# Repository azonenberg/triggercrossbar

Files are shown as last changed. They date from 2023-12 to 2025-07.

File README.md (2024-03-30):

# PROJECT STATUS

You probably don't want to build this as is, there's a couple of bugs. May or may not respin later on with fixes, for now I'm just bodging my prototype.

Bodge log at https://docs.google.com/document/d/14ighvhOLtBR-3ShkNhyRGlamA1f7WH5_sXfJCJYxb1o/edit

# What is it?

When finished, it will be a 1U rack-mountable appliance with a TBD number of BNC and/or SMA connectors on the back side for trigger inputs and outputs. Some will be input only, some output only, and some bidirectional. Exact mix is TBD.

Additionally, a front panel SMA input will be connected through a precision 10 GHz comparator (ADI HMC675LP3E) to an FPGA transceiver input, allowing single ended CDR triggering.

There may or may not be front panel SMA inputs/outputs connected to otherwise unused transceiver channels for expansion or additional trigger capabilities.

An Ethernet SCPI interface will allow configuration of an FPGA-based crossbar, with the internal CDR trigger as well as all of the input channels available as inputs. Any input can be forwarded to any output, allowing arbitrary cross-triggering of attached instruments without the need to recable.

Front panel LEDs with pulse stretching will display the states of trigger in/out ports.

This system is intended in part as a testbed to de-risk several future projects (validating stackup and power supply design etc), and to use up an FPGA that I had lying around the lab. Only one unit is ever expected to be built, so a functionally equivalent platform could definitely be built for lower cost.

# Physical architecture

# Trigger ports

Koaxis AL62-CC086F-RL10-6.00-MK (6" CC086F hand formable FEP jacket SMA - SMPM), length open to change based on final mechanical and board design.

## Input range

The range of the inputs should be sufficient to accommodate all common T&M instruments, which will likely require variable thresholding.

Representative instrument trigger output specs:

* PicoScope 6000E (bidirectional): not specified, need to measure
* PicoVNA 108: 3.3V into high-Z
* Siglent SSG5000X (bidirectional): 5V TTL for trigger, 3.3V CMOS for pulse
* Siglent SDG7000A: 5V TTL (voh = 3.8V)
* Teledyne LeCroy (all recent models): 1V into 1M ohm / 500 mV into 50 ohm by default, adjustable a bit?

## Output range

The range of the outputs should be compatible with all common T&M instruments, which will likely require variable swing.

Representative instrument trigger input specs:

* PicoScope 6000E (bidirectional): 2.5V CMOS high-z input, fixed 1.25V threshold
* PicoVNA 108: 3.3V CMOS high-Z, nominal 1.5V threshold
* Siglent SSG5000X (bidirectional): 5V TTL for trigger, 3.3V CMOS for pulse
* Siglent SDG7000A: 5V TTL (Vih = 2 to 5.5V)
* Teledyne LeCroy (all recent models): adjustable threshold up to +/- 400 mV or +/- 4V in 1x / 10x mode respectively

# Input buffer design

We need a total of seven inputs today, plan for at least ten to provide some margin

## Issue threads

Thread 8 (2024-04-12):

Full reboot support

azonenberg, 2024-04-12:
Rather than having the main MCU just reset itself when we run "reload", do a full power down/up sequence via the supervisor

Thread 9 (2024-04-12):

Full reboot support via front panel reset button

azonenberg, 2024-04-12:
Probably require holding it for a few seconds to avoid inadvertent resets?

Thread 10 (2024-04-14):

Intermittent SPI issues

azonenberg, 2024-04-14:
Example: version numbers shown on front panel having a byte truncated

Not sure if timing or Si or something else yet.

Closed 2024-04-15.

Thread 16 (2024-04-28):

Switch QSPI bus to memory mapped to improve performance

azonenberg, 2024-04-28:

azonenberg, 2024-05-23:
Fixed in b0f43f4e122610cb90c49703867806bcb94aeec4

Closed 2024-05-23.

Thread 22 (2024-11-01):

Resetting IBC results in a false panic shutdown from 12V power failure (this should be a clean sleep we can wake from when the IBC comes back up)

azonenberg, 2024-11-01:

azonenberg, 2024-11-03:
Should be fixed in 69b09eb50da21b395305ae7aaae45e123857d962

Closed 2024-11-03.

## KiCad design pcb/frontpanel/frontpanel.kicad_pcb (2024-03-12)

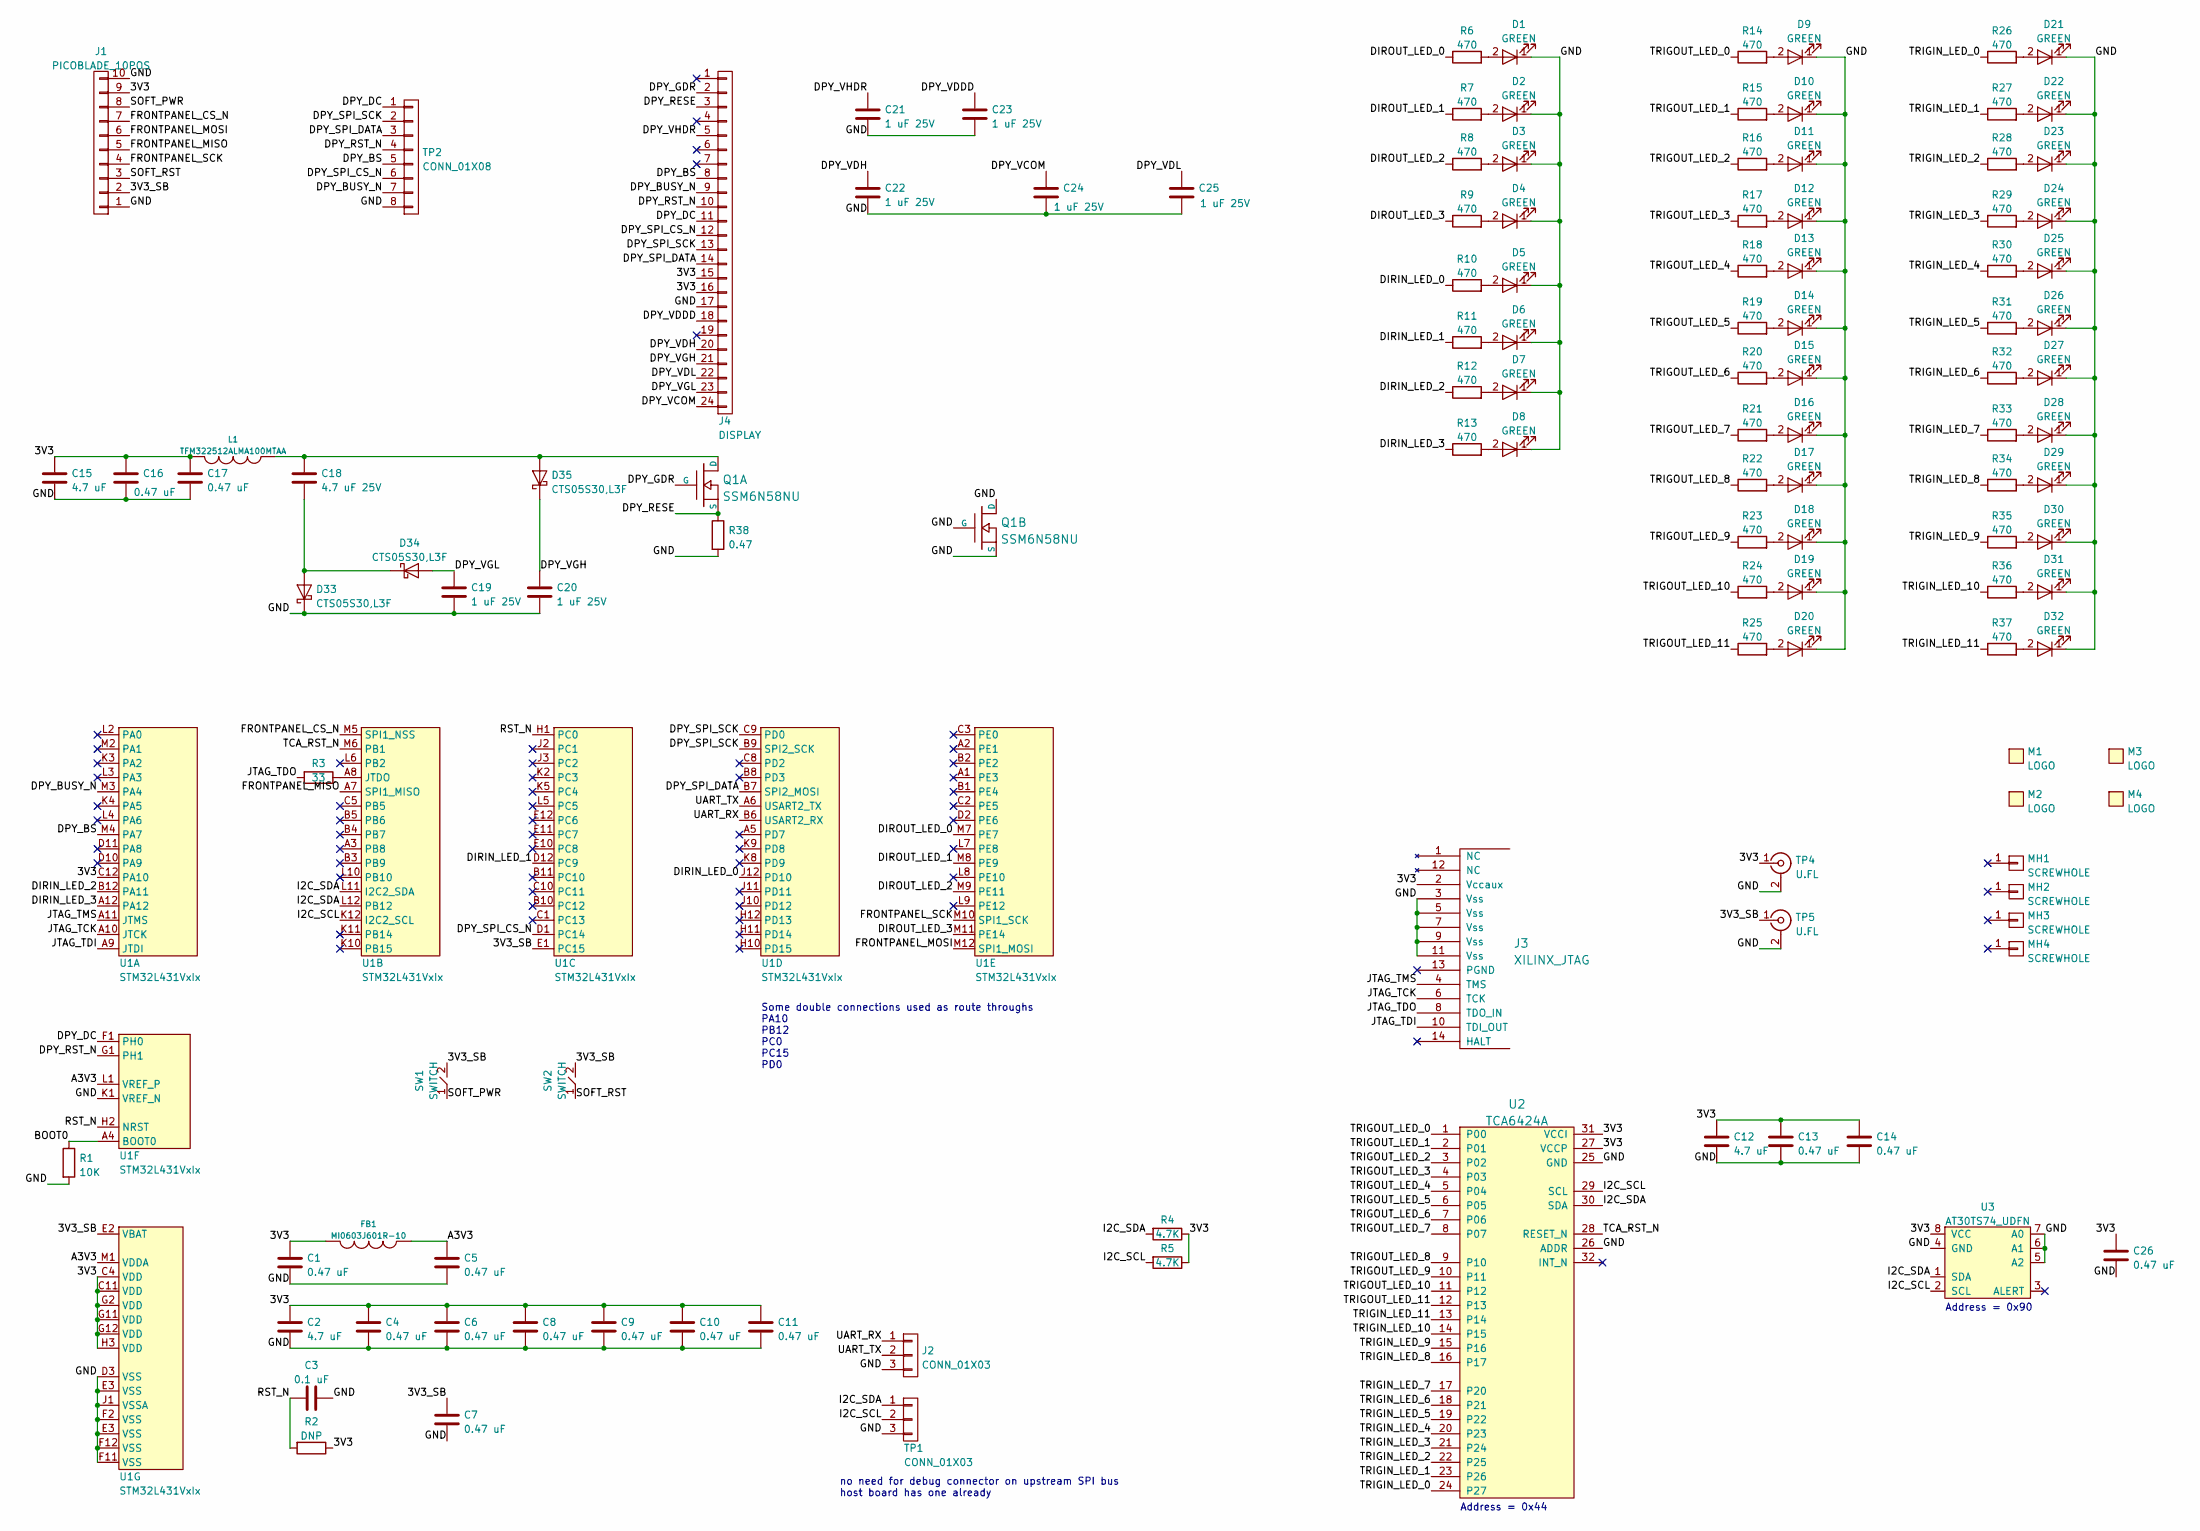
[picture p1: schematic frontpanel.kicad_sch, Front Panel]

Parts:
C1, C4, C5, C6, C7, C8, C9, C10, C11, C13, C14, C16, C17, C26: 0.47 uF; EIA_0402_CAP_NOSILK
C2, C12, C15: 4.7 uF; EIA_0603_CAP_NOSILK
C3: 0.1 uF; EIA_0402_CAP_NOSILK
C18: 4.7 uF 25V; EIA_0805_CAP_NOSILK
C19, C20, C21, C22, C23, C24, C25: 1 uF 25V; EIA_0805_CAP_NOSILK
D1, D2, D3, D4, D5, D6, D7, D8, D9, D10, D11, D12, D13, D14, D15, D16, D17, D18, D19, D20, D21, D22, D23, D24, D25, D26, D27, D28, D29, D30, D31, D32: GREEN; EIA_0603_LED
D33, D34, D35: CTS05S30,L3F; SOD882
FB1: MI0603J601R-10; EIA_0603_INDUCTOR_NOSILK
J1: PICOBLADE_10POS; CONN_MOLEX_PICOBLADE_10POS_0532611071
J2: CONN_01X03; CONN_HEADER_2.54MM_1x3
J3: XILINX_JTAG; XILINX_JTAG_PTH_MOLEX_0878311420
J4: DISPLAY; CONN_FFC_0.5MM_1x24_HIROSE_FH34SRJ-24S-0.5SH(50)
L1: TFM322512ALMA100MTAA; EIA_1210_CAP_NOSILK
M1: LOGO; LONGTHING-1200DPI
M2: LOGO; Logo_silk_WEEE_3.4x5mm
M3: LOGO; Logo_silk_OSHW_6x6mm
M4: LOGO; Logo_silk_ROHS_10x5.6mm
MH1, MH2, MH3, MH4: SCREWHOLE; MECHANICAL_CLEARANCEHOLE_4_40
Q1: SSM6N58NU; DFN_6_0.65MM_2x2MM_GDS
R1: 10K; EIA_0402_RES_NOSILK
R2: DNP; EIA_0402_RES_NOSILK
R3: 33; EIA_0402_RES_NOSILK
R4, R5: 4.7K; EIA_0402_RES_NOSILK
R6, R7, R8, R9, R10, R11, R12, R13, R14, R15, R16, R17, R18, R19, R20, R21, R22, R23, R24, R25, R26, R27, R28, R29, R30, R31, R32, R33, R34, R35, R36, R37: 470; EIA_0402_RES_NOSILK
R38: 0.47; EIA_0402_RES_NOSILK
SW1, SW2: SWITCH; SWITCH_RAFI_MICON_5
TP1: CONN_01X03; CONN_HEADER_2.54MM_1x3
TP2: CONN_01X08; CONN_HEADER_2.54MM_1x8
TP4, TP5: U.FL; CONN_U.FL_TE_1909763-1
U1: STM32L431VxIx; BGA_100_7x7_DEPOP_0.5MM_STM32_UFBGA100_OSHPARK
U2: TCA6424A; QFN_32_0.5MM_5x5MM
U3: AT30TS74_UDFN; DFN_8_0.5MM_2x3MM_TALL

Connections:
/3V3: C1.1, C2.1, C4.1, C6.1, C8.1, C9.1, C10.1, C11.1, C12.1, C13.1, C14.1, C15.1, C16.1, C17.1, C26.1, FB1.2, J1.9, J3.2 (Vccaux), J4.15, J4.16, L1.2, R2.1, R4.1, R5.1, TP4.1 (In), U1.C4 (VDD), U1.C11 (VDD), U1.C12 (PA10), U1.G2 (VDD), U1.G11 (VDD), U1.G12 (VDD), U1.H3 (VDD), U2.27 (VCCP), U2.31 (VCCI), U3.8 (VCC)
/3V3_SB: C7.1, J1.2, SW1.2, SW2.2, TP5.1 (In), U1.E1 (PC15), U1.E2 (VBAT)
/A3V3: C5.1, FB1.1, U1.L1 (VREF_P), U1.M1 (VDDA)
/BOOT0: R1.1, U1.A4 (BOOT0)
/DIRIN_LED_0: R10.1, U1.J12 (PD10)
/DIRIN_LED_1: R11.1, U1.D12 (PC9)
/DIRIN_LED_2: R12.1, U1.B12 (PA11)
/DIRIN_LED_3: R13.1, U1.A12
/DIROUT_LED_0: R6.1, U1.M7 (PE7)
/DIROUT_LED_1: R7.1, U1.M8 (PE9)
/DIROUT_LED_2: R8.1, U1.M9 (PE11)
/DIROUT_LED_3: R9.1, U1.M11 (PE14)
/DPY_BS: J4.8, TP2.5, U1.M4 (PA7)
/DPY_BUSY_N: J4.9, TP2.7, U1.M3 (PA4)
/DPY_DC: J4.11, TP2.1, U1.F1 (PH0)
/DPY_GDR: J4.2, Q1.G1 (G)
/DPY_RESE: J4.3, Q1.S1 (S), R38.1
/DPY_RST_N: J4.10, TP2.4, U1.G1 (PH1)
/DPY_SPI_CS_N: J4.12, TP2.6, U1.D1 (PC14)
/DPY_SPI_DATA: J4.14, TP2.3, U1.B7 (SPI2_MOSI)
/DPY_SPI_SCK: J4.13, TP2.2, U1.B9 (SPI2_SCK), U1.C9 (PD0)
/DPY_VCOM: C24.1, J4.24
/DPY_VDDD: C23.1, J4.18
/DPY_VDH: C22.1, J4.20
/DPY_VDL: C25.1, J4.22
/DPY_VGH: C20.1, D35.1 (K), J4.21
/DPY_VGL: C19.1, D34.2 (A), J4.23
/DPY_VHDR: C21.1, J4.5
/FRONTPANEL_CS_N: J1.7, U1.M5 (SPI1_NSS)
/FRONTPANEL_MISO: J1.5, U1.A7 (SPI1_MISO)
/FRONTPANEL_MOSI: J1.6, U1.M12 (SPI1_MOSI)
/FRONTPANEL_SCK: J1.4, U1.M10 (SPI1_SCK)
/GND: C1.2, C2.2, C3.2, C4.2, C5.2, C6.2, C7.2, C8.2, C9.2, C10.2, C11.2, C12.2, C13.2, C14.2, C15.2, C16.2, C17.2, C19.2, C20.2, C21.2, C22.2, C23.2, C24.2, C25.2, C26.2, D1.1 (K), D2.1 (K), D3.1 (K), D4.1 (K), D5.1 (K), D6.1 (K), D7.1 (K), D8.1 (K), D9.1 (K), D10.1 (K), D11.1 (K), D12.1 (K), D13.1 (K), D14.1 (K), D15.1 (K), D16.1 (K), D17.1 (K), D18.1 (K), D19.1 (K), D20.1 (K), D21.1 (K), D22.1 (K), D23.1 (K), D24.1 (K), D25.1 (K), D26.1 (K), D27.1 (K), D28.1 (K), D29.1 (K), D30.1 (K), D31.1 (K), D32.1 (K), D33.1 (K), J1.1, J1.10, J2.3, J3.3 (Vss), J3.5 (Vss), J3.7 (Vss), J3.9 (Vss), J3.11 (Vss), J4.17, Q1.D2 (D), Q1.G2 (G), Q1.S2 (S), R1.2, R38.2, TP1.3, TP2.8, TP4.2 (Ext), TP5.2 (Ext), U1.D3 (VSS), U1.E3 (VSS), U1.F2 (VSS), U1.F11 (VSS), U1.F12 (VSS), U1.J1 (VSSA), U1.K1 (VREF_N), U2.25 (GND), U2.26 (ADDR), U3.4 (GND), U3.5 (A2), U3.6 (A1), U3.7 (A0)
/I2C_SCL: R5.2, TP1.2, U1.K12 (I2C2_SCL), U2.29 (SCL), U3.2 (SCL)
/I2C_SDA: R4.2, TP1.1, U1.L11 (I2C2_SDA), U1.L12 (PB12), U2.30 (SDA), U3.1 (SDA)
/JTAG_TCK: J3.6 (TCK), U1.A10 (JTCK)
/JTAG_TDI: J3.10 (TDI_OUT), U1.A9 (JTDI)
/JTAG_TDO: J3.8 (TDO_IN), R3.2
/JTAG_TMS: J3.4 (TMS), U1.A11 (JTMS)
/RST_N: C3.1, R2.2, U1.H1 (PC0), U1.H2 (NRST)
/SOFT_PWR: J1.8, SW1.1
/SOFT_RST: J1.3, SW2.1
/TCA_RST_N: U1.M6 (PB1), U2.28 (RESET_N)
/TRIGIN_LED_0: R26.1, U2.24 (P27)
/TRIGIN_LED_1: R27.1, U2.23 (P26)
/TRIGIN_LED_2: R28.1, U2.22 (P25)
/TRIGIN_LED_3: R29.1, U2.21 (P24)
/TRIGIN_LED_4: R30.1, U2.20 (P23)
/TRIGIN_LED_5: R31.1, U2.19 (P22)
/TRIGIN_LED_6: R32.1, U2.18 (P21)
/TRIGIN_LED_7: R33.1, U2.17 (P20)
/TRIGIN_LED_8: R34.1, U2.16 (P17)
/TRIGIN_LED_9: R35.1, U2.15 (P16)
/TRIGIN_LED_10: R36.1, U2.14 (P15)
/TRIGIN_LED_11: R37.1, U2.13 (P14)
/TRIGOUT_LED_0: R14.1, U2.1 (P00)
/TRIGOUT_LED_1: R15.1, U2.2 (P01)
/TRIGOUT_LED_2: R16.1, U2.3 (P02)
/TRIGOUT_LED_3: R17.1, U2.4 (P03)
/TRIGOUT_LED_4: R18.1, U2.5 (P04)
/TRIGOUT_LED_5: R19.1, U2.6 (P05)
/TRIGOUT_LED_6: R20.1, U2.7 (P06)
/TRIGOUT_LED_7: R21.1, U2.8 (P07)
/TRIGOUT_LED_8: R22.1, U2.9 (P10)
/TRIGOUT_LED_9: R23.1, U2.10 (P11)
/TRIGOUT_LED_10: R24.1, U2.11 (P12)
/TRIGOUT_LED_11: R25.1, U2.12 (P13)
/UART_RX: J2.1, U1.B6 (USART2_RX)
/UART_TX: J2.2, U1.A6 (USART2_TX)
unnamed: C18.1, D35.2 (A), L1.1, Q1.D1 (D)
unnamed: C18.2, D33.2 (A), D34.1 (K)
unnamed: D1.2 (A), R6.2
unnamed: D2.2 (A), R7.2
unnamed: D3.2 (A), R8.2
unnamed: D4.2 (A), R9.2
unnamed: D5.2 (A), R10.2
unnamed: D6.2 (A), R11.2
unnamed: D7.2 (A), R12.2
unnamed: D8.2 (A), R13.2
unnamed: D9.2 (A), R14.2
unnamed: D10.2 (A), R15.2
unnamed: D11.2 (A), R16.2
unnamed: D12.2 (A), R17.2
unnamed: D13.2 (A), R18.2
unnamed: D14.2 (A), R19.2
unnamed: D15.2 (A), R20.2
unnamed: D16.2 (A), R21.2
unnamed: D17.2 (A), R22.2
unnamed: D18.2 (A), R23.2
unnamed: D19.2 (A), R24.2
unnamed: D20.2 (A), R25.2
unnamed: D21.2 (A), R26.2
unnamed: D22.2 (A), R27.2
unnamed: D23.2 (A), R28.2
unnamed: D24.2 (A), R29.2
unnamed: D25.2 (A), R30.2
unnamed: D26.2 (A), R31.2
unnamed: D27.2 (A), R32.2
unnamed: D28.2 (A), R33.2
unnamed: D29.2 (A), R34.2
unnamed: D30.2 (A), R35.2
unnamed: D31.2 (A), R36.2
unnamed: D32.2 (A), R37.2
unnamed: R3.1, U1.A8 (JTDO)

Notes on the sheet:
Address = 0x90
no need for debug connector on upstream SPI bus host board has one already
Address = 0x44
Some double connections used as route throughs PA10 PB12 PC0 PC15 PD0

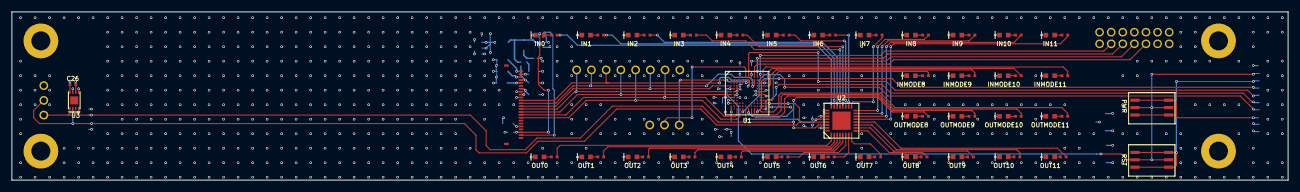
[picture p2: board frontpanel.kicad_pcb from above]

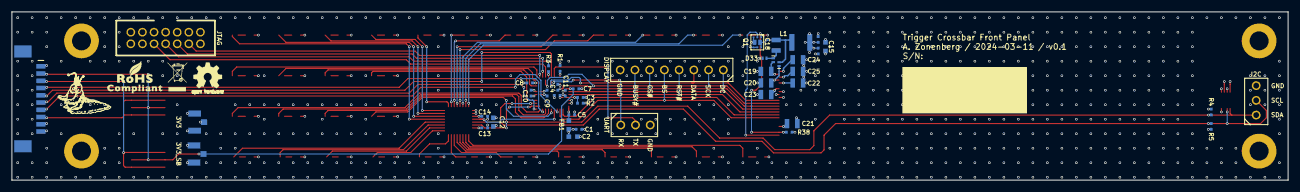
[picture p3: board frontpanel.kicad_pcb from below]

Board: 4 copper layers, 220.0 x 29.0 mm, 123 parts (52 on the bottom side), 104 nets.

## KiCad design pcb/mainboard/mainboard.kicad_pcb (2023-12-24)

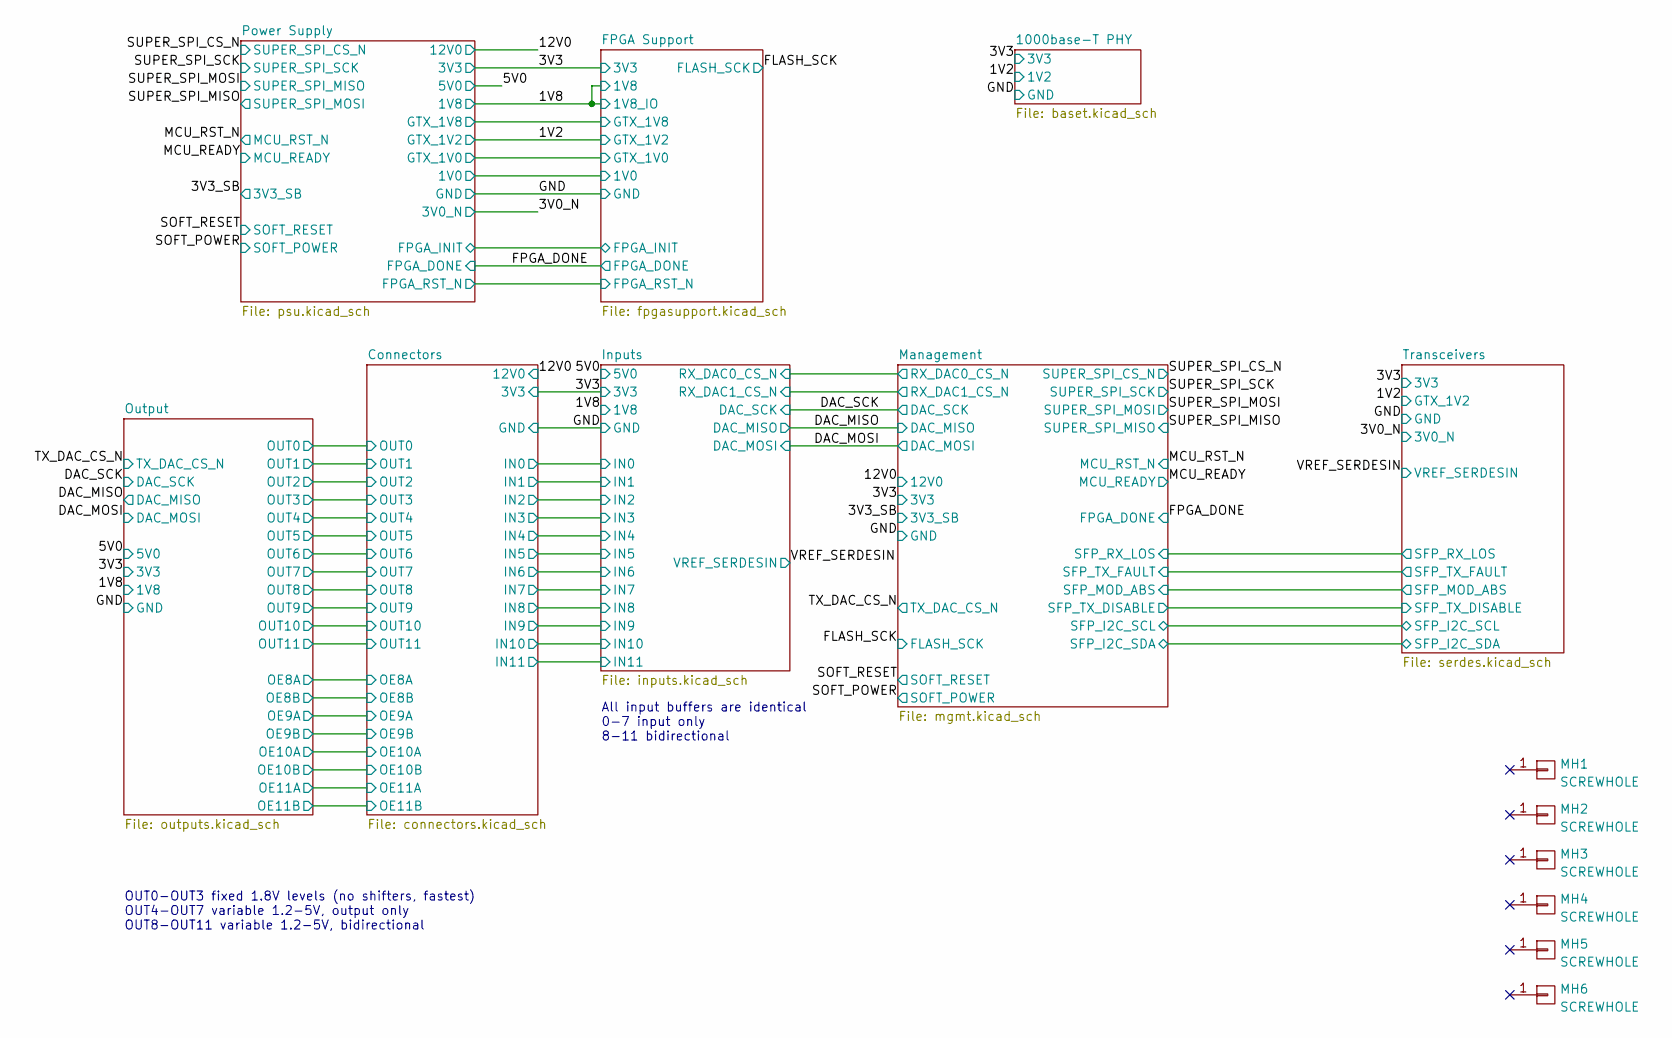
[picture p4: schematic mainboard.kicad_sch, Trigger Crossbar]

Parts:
MH1, MH2, MH3, MH4, MH5, MH6: SCREWHOLE; MECHANICAL_CLEARANCEHOLE_4_40

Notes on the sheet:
All input buffers are identical 0-7 input only 8-11 bidirectional
OUT0-OUT3 fixed 1.8V levels (no shifters, fastest) OUT4-OUT7 variable 1.2-5V, output only OUT8-OUT11 variable 1.2-5V, bidirectional

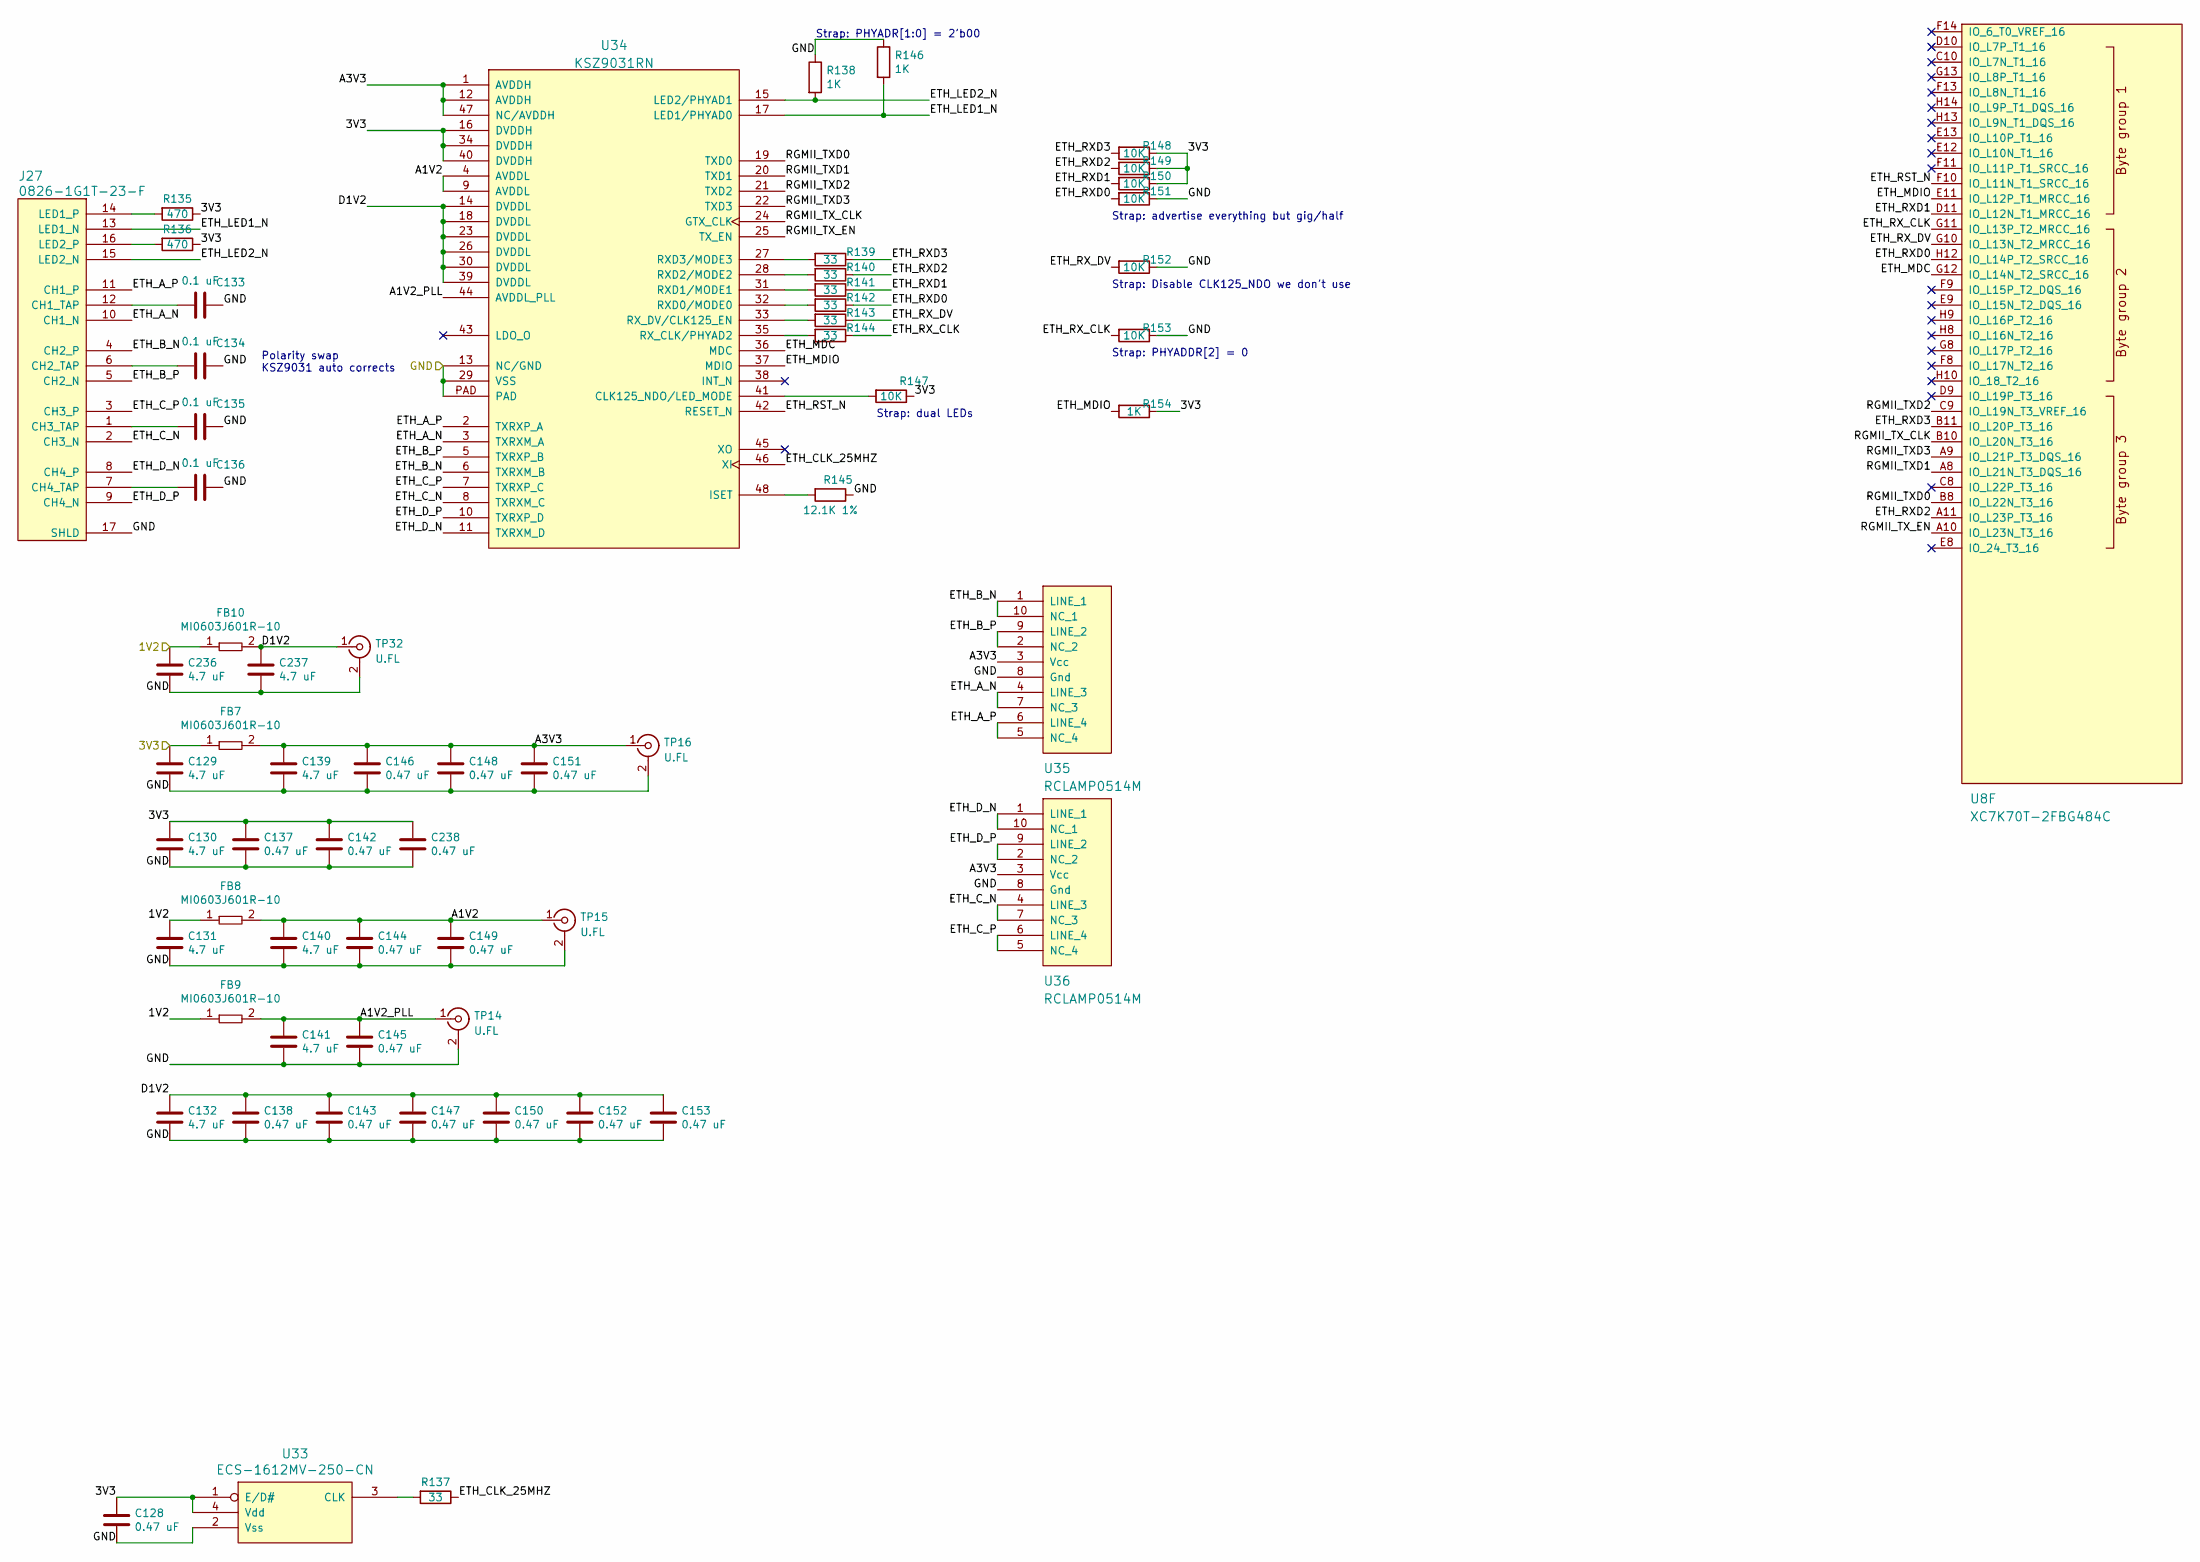
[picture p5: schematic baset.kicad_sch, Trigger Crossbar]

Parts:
C128, C137, C138, C142, C143, C144, C145, C146, C147, C148, C149, C150, C151, C152, C153, C238: 0.47 uF; EIA_0402_CAP_NOSILK
C129, C130, C131, C132, C139, C140, C141, C236, C237: 4.7 uF; EIA_0603_CAP_NOSILK
C133, C134, C135, C136: 0.1 uF; EIA_0402_CAP_NOSILK
FB7, FB8, FB9, FB10: MI0603J601R-10; EIA_0603_INDUCTOR_NOSILK
J27: 0826-1G1T-23-F; CONN_BELFUSE_0826_1G1T_23_F
R135, R136: 470; EIA_0402_RES_NOSILK
R137, R139, R140, R141, R142, R143, R144: 33; EIA_0402_RES_NOSILK
R138, R146, R154: 1K; EIA_0402_RES_NOSILK
R145: 12.1K 1%; EIA_0402_RES_NOSILK
R147, R148, R149, R150, R151, R152, R153: 10K; EIA_0402_RES_NOSILK
TP14, TP15, TP16, TP32: U.FL; CONN_U.FL_TE_1909763-1
U8: XC7K70T-2FBG484C; BGA_484_22x22_FULLARRAY_1MM
U33: ECS-1612MV-250-CN; OSCILLATOR_1.6x1.2
U34: KSZ9031RN; QFN_48_0.5MM_7x7MM
U35, U36: RCLAMP0514M; SOP_10_0.5MM_3MM

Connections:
/1V2: C131.1, C236.1, FB8.1, FB9.1, FB10.1; also elsewhere on the board
/3V3: C128.1, C129.1, C130.1, C137.1, C142.1, C238.1, FB7.1, R135.1, R136.1, R147.1, R148.1, R149.1, R150.1, R154.1, U33.1 (E/D#), U33.4 (Vdd), U34.16 (DVDDH), U34.34 (DVDDH), U34.40 (DVDDH); also elsewhere on the board
/1000base-T PHY/A1V2: C140.1, C144.1, C149.1, FB8.2, TP15.1 (In), U34.4 (AVDDL), U34.9 (AVDDL)
/1000base-T PHY/A1V2_PLL: C141.1, C145.1, FB9.2, TP14.1 (In), U34.44 (AVDDL_PLL)
/1000base-T PHY/A3V3: C139.1, C146.1, C148.1, C151.1, FB7.2, TP16.1 (In), U34.1 (AVDDH), U34.12 (AVDDH), U34.47 (NC/AVDDH), U35.3 (Vcc), U36.3 (Vcc)
/1000base-T PHY/D1V2: C132.1, C138.1, C143.1, C147.1, C150.1, C152.1, C153.1, C237.1, FB10.2, TP32.1 (In), U34.14 (DVDDL), U34.18 (DVDDL), U34.23 (DVDDL), U34.26 (DVDDL), U34.30 (DVDDL), U34.39 (DVDDL)
/1000base-T PHY/ETH_A_N: J27.10 (CH1_N), U34.3 (TXRXM_A), U35.4 (LINE_3), U35.7 (NC_3)
/1000base-T PHY/ETH_A_P: J27.11 (CH1_P), U34.2 (TXRXP_A), U35.5 (NC_4), U35.6 (LINE_4)
/1000base-T PHY/ETH_B_N: J27.4 (CH2_P), U34.6 (TXRXM_B), U35.1 (LINE_1), U35.10 (NC_1)
/1000base-T PHY/ETH_B_P: J27.5 (CH2_N), U34.5 (TXRXP_B), U35.2 (NC_2), U35.9 (LINE_2)
/1000base-T PHY/ETH_CLK_25MHZ: R137.1, U34.46 (XI)
/1000base-T PHY/ETH_C_N: J27.2 (CH3_N), U34.8 (TXRXM_C), U36.4 (LINE_3), U36.7 (NC_3)
/1000base-T PHY/ETH_C_P: J27.3 (CH3_P), U34.7 (TXRXP_C), U36.5 (NC_4), U36.6 (LINE_4)
/1000base-T PHY/ETH_D_N: J27.8 (CH4_P), U34.11 (TXRXM_D), U36.1 (LINE_1), U36.10 (NC_1)
/1000base-T PHY/ETH_D_P: J27.9 (CH4_N), U34.10 (TXRXP_D), U36.2 (NC_2), U36.9 (LINE_2)
/1000base-T PHY/ETH_LED1_N: J27.13 (LED1_N), R146.2, U34.17 (LED1/PHYAD0)
/1000base-T PHY/ETH_LED2_N: J27.15 (LED2_N), R138.2, U34.15 (LED2/PHYAD1)
/1000base-T PHY/ETH_MDC: U8.G12 (IO_L14N_T2_SRCC_16), U34.36 (MDC)
/1000base-T PHY/ETH_MDIO: R154.2, U8.E11 (IO_L12P_T1_MRCC_16), U34.37 (MDIO)
/1000base-T PHY/ETH_RST_N: U8.F10 (IO_L11N_T1_SRCC_16), U34.42 (RESET_N)
/1000base-T PHY/ETH_RXD0: R142.1, R151.2, U8.H12 (IO_L14P_T2_SRCC_16)
/1000base-T PHY/ETH_RXD1: R141.1, R150.2, U8.D11 (IO_L12N_T1_MRCC_16)
/1000base-T PHY/ETH_RXD2: R140.1, R149.2, U8.A11 (IO_L23P_T3_16)
/1000base-T PHY/ETH_RXD3: R139.1, R148.2, U8.B11 (IO_L20P_T3_16)
/1000base-T PHY/ETH_RX_CLK: R144.1, R153.2, U8.G11 (IO_L13P_T2_MRCC_16)
/1000base-T PHY/ETH_RX_DV: R143.1, R152.2, U8.G10 (IO_L13N_T2_MRCC_16)
/1000base-T PHY/RGMII_TXD0: U8.B8 (IO_L22N_T3_16), U34.19 (TXD0)
/1000base-T PHY/RGMII_TXD1: U8.A8 (IO_L21N_T3_DQS_16), U34.20 (TXD1)
/1000base-T PHY/RGMII_TXD2: U8.C9 (IO_L19N_T3_VREF_16), U34.21 (TXD2)
/1000base-T PHY/RGMII_TXD3: U8.A9 (IO_L21P_T3_DQS_16), U34.22 (TXD3)
/1000base-T PHY/RGMII_TX_CLK: U8.B10 (IO_L20N_T3_16), U34.24 (GTX_CLK)
/1000base-T PHY/RGMII_TX_EN: U8.A10 (IO_L23N_T3_16), U34.25 (TX_EN)
/GND: C128.2, C129.2, C130.2, C131.2, C132.2, C133.1, C134.1, C135.1, C136.1, C137.2, C138.2, C139.2, C140.2, C141.2, C142.2, C143.2, C144.2, C145.2, C146.2, C147.2, C148.2, C149.2, C150.2, C151.2, C152.2, C153.2, C236.2, C237.2, C238.2, J27.17 (SHLD), R138.1, R145.1, R146.1, R151.1, R152.1, R153.1, TP14.2 (Ext), TP15.2 (Ext), TP16.2 (Ext), TP32.2 (Ext), U33.2 (Vss), U34.13 (NC/GND), U34.29 (VSS), U34.PAD, U35.8 (Gnd), U36.8 (Gnd); also elsewhere on the board
unnamed: C133.2, J27.12 (CH1_TAP)
unnamed: C134.2, J27.6 (CH2_TAP)
unnamed: C135.2, J27.1 (CH3_TAP)
unnamed: C136.2, J27.7 (CH4_TAP)
unnamed: J27.14 (LED1_P), R135.2
unnamed: J27.16 (LED2_P), R136.2
unnamed: R137.2, U33.3 (CLK)
unnamed: R139.2, U34.27 (RXD3/MODE3)
unnamed: R140.2, U34.28 (RXD2/MODE2)
unnamed: R141.2, U34.31 (RXD1/MODE1)
unnamed: R142.2, U34.32 (RXD0/MODE0)
unnamed: R143.2, U34.33 (RX_DV/CLK125_EN)
unnamed: R144.2, U34.35 (RX_CLK/PHYAD2)
unnamed: R145.2, U34.48 (ISET)
unnamed: R147.2, U34.41 (CLK125_NDO/LED_MODE)

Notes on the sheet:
Polarity swap KSZ9031 auto corrects
Strap: PHYADR[1:0] = 2'b00
Strap: PHYADDR[2] = 0
Strap: advertise everything but gig/half
Strap: dual LEDs
Strap: Disable CLK125_NDO we don't use

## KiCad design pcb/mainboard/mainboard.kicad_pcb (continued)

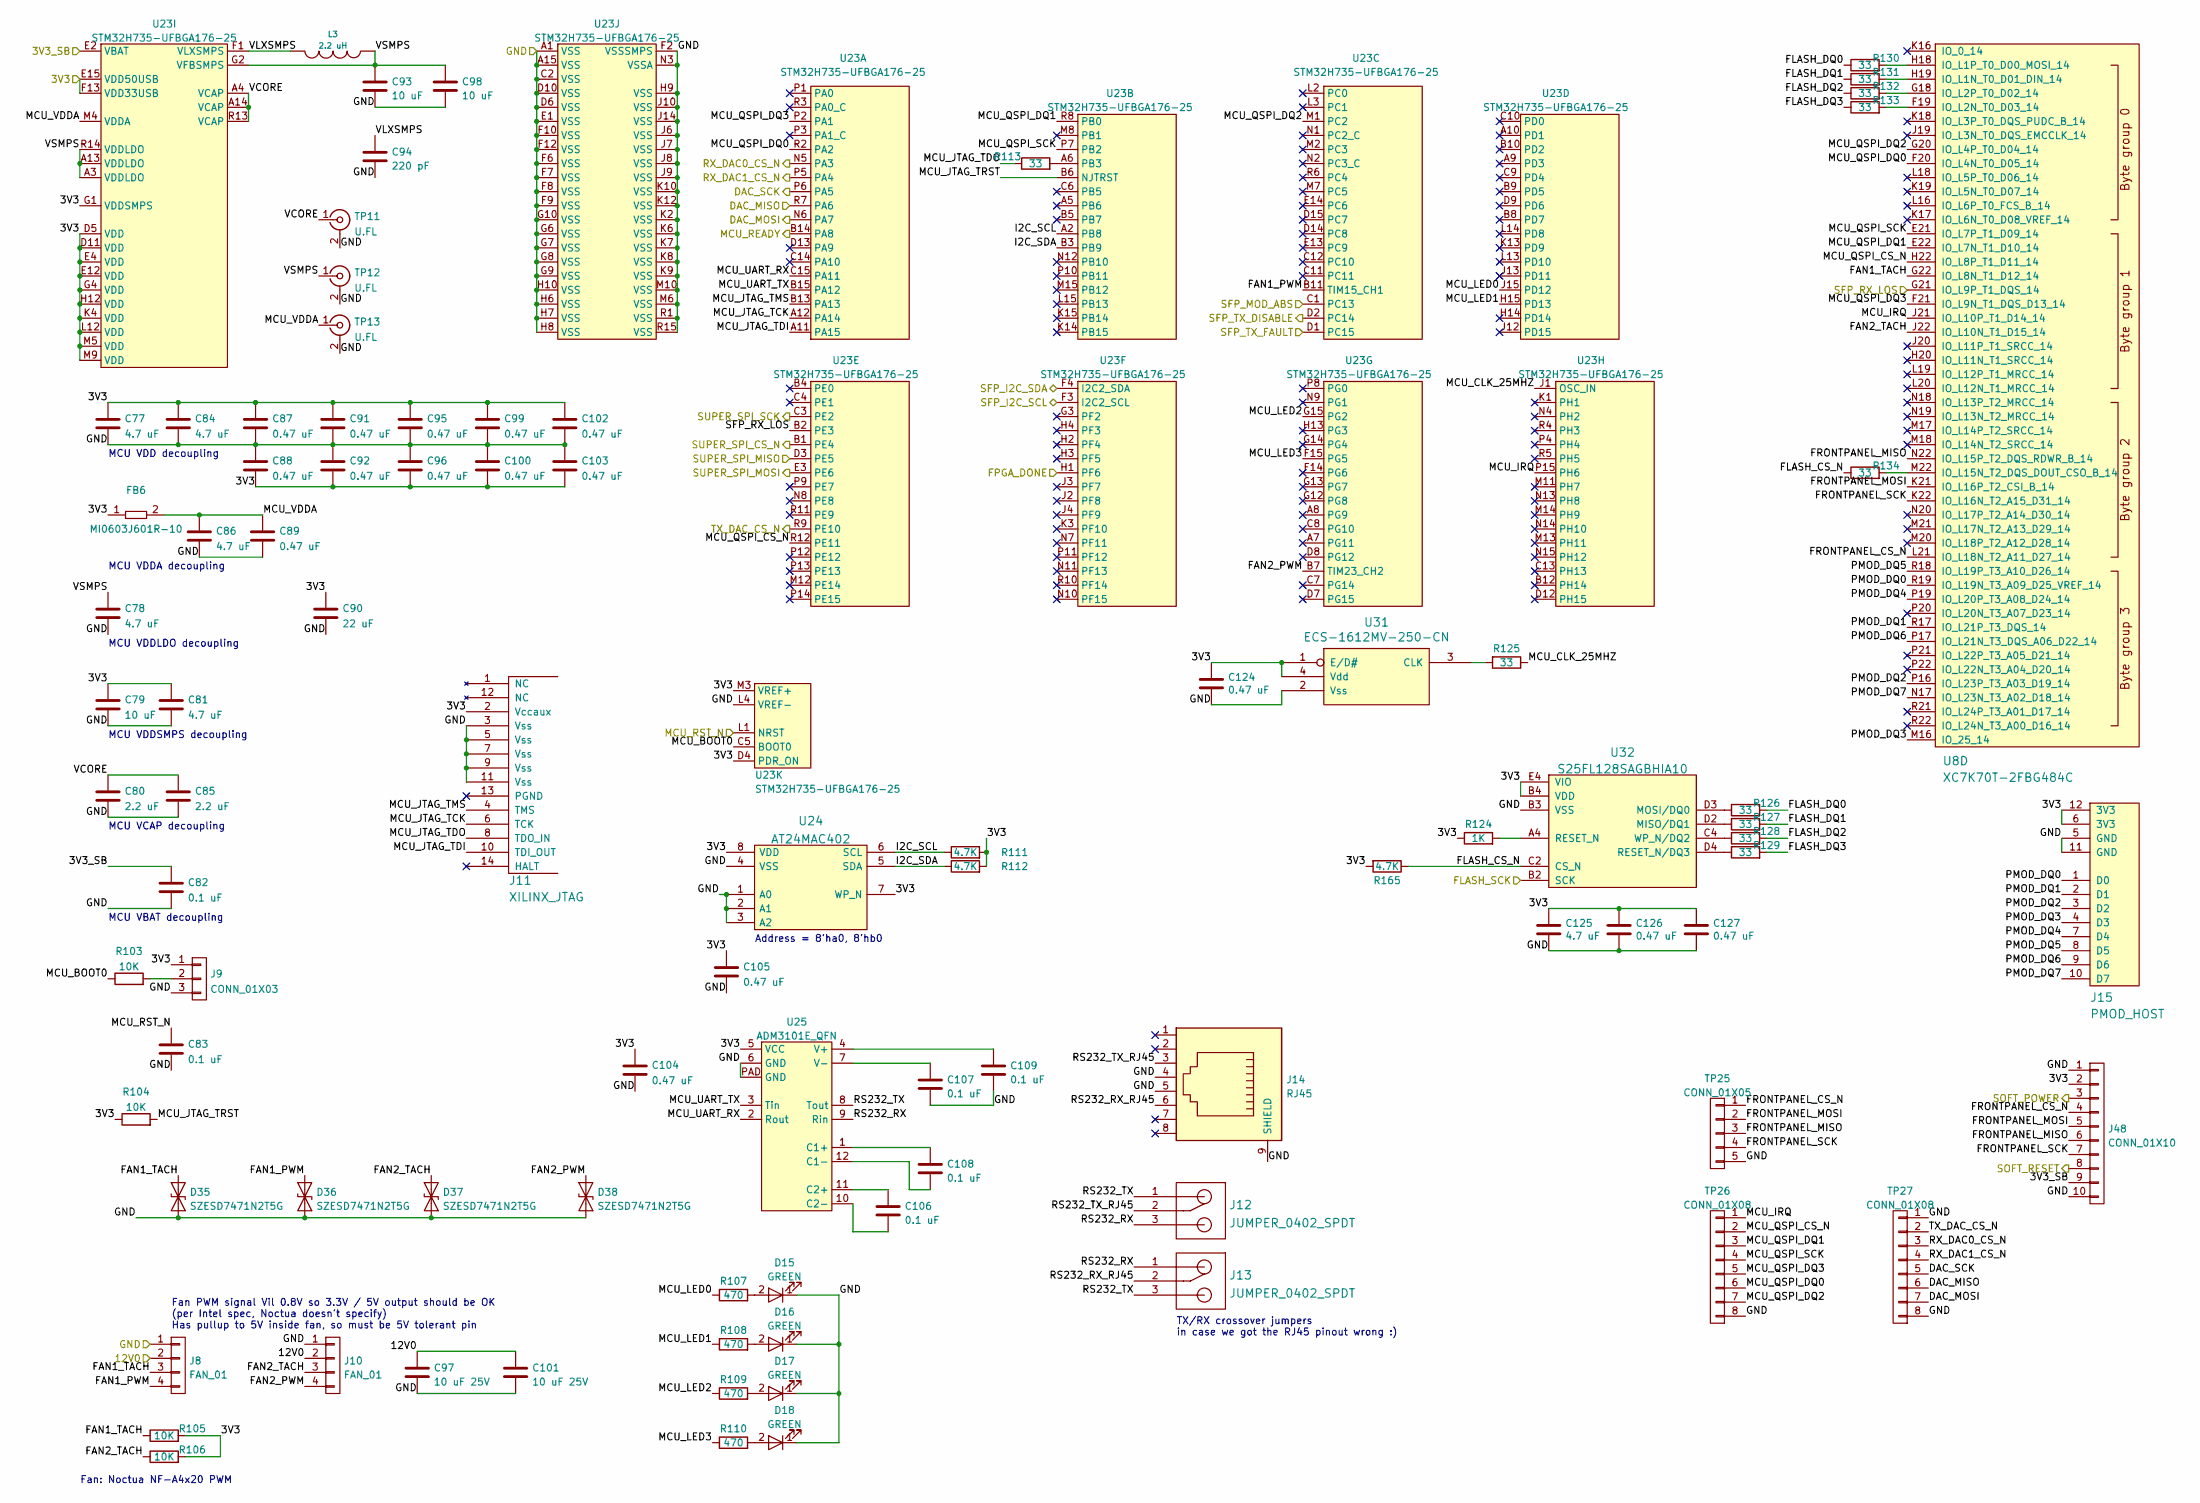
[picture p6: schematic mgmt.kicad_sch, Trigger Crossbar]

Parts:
C77, C78, C81, C84, C86, C125: 4.7 uF; EIA_0603_CAP_NOSILK
C79, C93, C98: 10 uF; EIA_0805_CAP_NOSILK
C80, C85: 2.2 uF; EIA_0805_CAP_NOSILK
C82, C83, C106, C107, C108, C109: 0.1 uF; EIA_0402_CAP_NOSILK
C87, C88, C89, C91, C92, C95, C96, C99, C100, C102, C103, C104, C105, C124, C126, C127: 0.47 uF; EIA_0402_CAP_NOSILK
C90: 22 uF; EIA_0805_CAP_NOSILK
C94: 220 pF; EIA_0402_CAP_NOSILK
C97, C101: 10 uF 25V; EIA_1210_CAP_NOSILK
D15, D16, D17, D18: GREEN; EIA_0603_LED
D35, D36, D37, D38: SZESD7471N2T5G; SOD882
FB6: MI0603J601R-10; EIA_0603_INDUCTOR_NOSILK
J8, J10: FAN_01; CONN_MOLEX_KK_0470531000
J9: CONN_01X03; CONN_HEADER_2.54MM_1x3
J11: XILINX_JTAG; XILINX_JTAG_PTH_MOLEX_0878311420
J12, J13: JUMPER_0402_SPDT; EIA_0402_JUMPER
J14: RJ45; CONN_RJ45_BELSTEWART_SS-7188S-A-PG4-1-BA-xx
J15: PMOD_HOST; CONN_HEADER_2.54MM_2x6_RA_PMOD_HOST
J48: CONN_01X10; CONN_MOLEX_PICOBLADE_10POS_0532611071
L3: 2.2 uH; EIA_1210_CAP_NOSILK
R103, R104, R105, R106: 10K; EIA_0402_RES_NOSILK
R107, R108, R109, R110: 470; EIA_0402_RES_NOSILK
R111, R112, R165: 4.7K; EIA_0402_RES_NOSILK
R113, R125, R126, R127, R128, R129, R130, R131, R132, R133, R134: 33; EIA_0402_RES_NOSILK
R124: 1K; EIA_0402_RES_NOSILK
TP11, TP12, TP13: U.FL; CONN_U.FL_TE_1909763-1
TP25: CONN_01X05; CONN_HEADER_2.54MM_1x5
TP26, TP27: CONN_01X08; CONN_HEADER_2.54MM_1x8
U8: XC7K70T-2FBG484C; BGA_484_22x22_FULLARRAY_1MM
U23: STM32H735-UFBGA176-25; BGA_201_10x10_DEPOP_0.65MM_OSHPARK
U24: AT24MAC402; DFN_8_0.5MM_2x3MM_TALL
U25: ADM3101E_QFN; QFN_12_0.5MM_3x3MM
U31: ECS-1612MV-250-CN; OSCILLATOR_1.6x1.2
U32: S25FL128SAGBHIA10; BGA_24_6x8_DEPOP1_1MM

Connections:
/3V3: C77.1, C79.1, C81.1, C84.1, C87.1, C88.2, C90.1, C91.1, C92.2, C95.1, C96.2, C99.1, C100.2, C102.1, C103.2, C104.1, C105.1, C124.1, C125.1, C126.1, C127.1, FB6.1, J9.1, J11.2 (Vccaux), J15.6 (3V3), J15.12 (3V3), J48.2, R104.1, R105.2, R106.2, R111.2, R112.2, R124.1, R165.2, U23.D4 (PDR_ON), U23.D5 (VDD), U23.D11 (VDD), U23.E4 (VDD), U23.E12 (VDD), U23.E15 (VDD50USB), U23.F13 (VDD33USB), U23.G1 (VDDSMPS), U23.G4 (VDD), U23.H12 (VDD), U23.K4 (VDD), U23.L12 (VDD), U23.M3 (VREF+), U23.M5 (VDD), U23.M9 (VDD), U24.7 (WP_N), U24.8 (VDD), U25.5 (VCC), U31.1 (E/D#), U31.4 (Vdd), U32.B4 (VDD), U32.E4 (VIO); also elsewhere on the board
/3V3_SB: C82.1, J48.9, U23.E2 (VBAT); also elsewhere on the board
/12V0: C97.1, C101.1, J8.2, J10.2; also elsewhere on the board
/DAC_MISO: TP27.6, U23.R7 (PA6); also elsewhere on the board
/DAC_MOSI: TP27.7, U23.N6 (PA7); also elsewhere on the board
/DAC_SCK: TP27.5, U23.P6 (PA5); also elsewhere on the board
/FLASH_SCK: U32.B2 (SCK); also elsewhere on the board
/FPGA_DONE: U23.H1 (PF6); also elsewhere on the board
/GND: C77.2, C78.2, C79.2, C80.2, C81.2, C82.2, C83.2, C84.2, C85.2, C86.2, C87.2, C88.1, C89.2, C90.2, C91.2, C92.1, C93.2, C94.2, C95.2, C96.1, C97.2, C98.2, C99.2, C100.1, C101.2, C102.2, C103.1, C104.2, C105.2, C107.2, C109.2, C124.2, C125.2, C126.2, C127.2, D15.1 (K), D16.1 (K), D17.1 (K), D18.1 (K), D35.1 (A1), D36.1 (A1), D37.1 (A1), D38.1 (A1), J8.1, J9.3, J10.1, J11.3 (Vss), J11.5 (Vss), J11.7 (Vss), J11.9 (Vss), J11.11 (Vss), J14.4, J14.5, J14.9 (SHIELD), J15.5 (GND), J15.11 (GND), J48.1, J48.10, TP11.2 (Ext), TP12.2 (Ext), TP13.2 (Ext), TP25.5, TP26.8, TP27.1, TP27.8, U23.A1 (VSS), U23.A15 (VSS), U23.C2 (VSS), U23.D6 (VSS), U23.D10 (VSS), U23.E1 (VSS), U23.F2 (VSSSMPS), U23.F6 (VSS), U23.F7 (VSS), U23.F8 (VSS), U23.F9 (VSS), U23.F10 (VSS), U23.F12 (VSS), U23.G6 (VSS), U23.G7 (VSS), U23.G8 (VSS), U23.G9 (VSS), U23.G10 (VSS), U23.H6 (VSS), U23.H7 (VSS), U23.H8 (VSS), U23.H9 (VSS), U23.H10 (VSS), U23.J6 (VSS), U23.J7 (VSS), U23.J8 (VSS), U23.J9 (VSS), U23.J10 (VSS), U23.J14 (VSS), U23.K2 (VSS), U23.K6 (VSS), U23.K7 (VSS), U23.K8 (VSS), U23.K9 (VSS), U23.K10 (VSS), U23.K12 (VSS), U23.L4 (VREF-), U23.M6 (VSS), U23.M10 (VSS), U23.N3 (VSSA), U23.R1 (VSS), U23.R15 (VSS), U24.1 (A0), U24.2 (A1), U24.3 (A2), U24.4 (VSS), U25.6 (GND), U25.PAD (GND), U31.2 (Vss), U32.B3 (VSS); also elsewhere on the board
/MCU_READY: U23.B14 (PA8); also elsewhere on the board
/MCU_RST_N: C83.1, U23.L1 (NRST); also elsewhere on the board
/Management/FAN1_PWM: D36.2 (A2), J8.4, U23.B11 (TIM15_CH1)
/Management/FAN1_TACH: D35.2 (A2), J8.3, R105.1, U8.G22 (IO_L8N_T1_D12_14)
/Management/FAN2_PWM: D38.2 (A2), J10.4, U23.B7 (TIM23_CH2)
/Management/FAN2_TACH: D37.2 (A2), J10.3, R106.1, U8.J22 (IO_L10N_T1_D15_14)
/Management/FLASH_CS_N: R134.1, R165.1, U32.C2 (CS_N)
/Management/FLASH_DQ0: R126.2, R130.1
/Management/FLASH_DQ1: R127.2, R131.1
/Management/FLASH_DQ2: R128.2, R132.1
/Management/FLASH_DQ3: R129.2, R133.1
/Management/FRONTPANEL_CS_N: J48.4, TP25.1, U8.L21 (IO_L18N_T2_A11_D27_14)
/Management/FRONTPANEL_MISO: J48.6, TP25.3, U8.N22 (IO_L15P_T2_DQS_RDWR_B_14)
/Management/FRONTPANEL_MOSI: J48.5, TP25.2, U8.K21 (IO_L16P_T2_CSI_B_14)
/Management/FRONTPANEL_SCK: J48.7, TP25.4, U8.K22 (IO_L16N_T2_A15_D31_14)
/Management/I2C_SCL: R111.1, U23.A2 (PB8), U24.6 (SCL)
/Management/I2C_SDA: R112.1, U23.B3 (PB9), U24.5 (SDA)
/Management/MCU_BOOT0: R103.1, U23.C5 (BOOT0)
/Management/MCU_CLK_25MHZ: R125.1, U23.J1 (OSC_IN)
/Management/MCU_IRQ: TP26.1, U8.J21 (IO_L10P_T1_D14_14), U23.P15 (PH6)
/Management/MCU_JTAG_TCK: J11.6 (TCK), U23.A12 (PA14)
/Management/MCU_JTAG_TDI: J11.10 (TDI_OUT), U23.A11 (PA15)
/Management/MCU_JTAG_TDO: J11.8 (TDO_IN), R113.1
/Management/MCU_JTAG_TMS: J11.4 (TMS), U23.B13 (PA13)
/Management/MCU_JTAG_TRST: R104.2, U23.B6 (NJTRST)
/Management/MCU_LED0: R107.1, U23.J15 (PD12)
/Management/MCU_LED1: R108.1, U23.H15 (PD13)
/Management/MCU_LED2: R109.1, U23.G15 (PG2)
/Management/MCU_LED3: R110.1, U23.F15 (PG5)
/Management/MCU_QSPI_CS_N: TP26.2, U8.H22 (IO_L8P_T1_D11_14), U23.R12 (PE11)
/Management/MCU_QSPI_DQ0: TP26.6, U8.F20 (IO_L4N_T0_D05_14), U23.R2 (PA2)
/Management/MCU_QSPI_DQ1: TP26.3, U8.E22 (IO_L7N_T1_D10_14), U23.R8 (PB0)
/Management/MCU_QSPI_DQ2: TP26.7, U8.G20 (IO_L4P_T0_D04_14), U23.M1 (PC2)
/Management/MCU_QSPI_DQ3: TP26.5, U8.F21 (IO_L9N_T1_DQS_D13_14), U23.P2 (PA1)
/Management/MCU_QSPI_SCK: TP26.4, U8.E21 (IO_L7P_T1_D09_14), U23.P7 (PB2)
/Management/MCU_UART_RX: U23.C15 (PA11), U25.2 (Rout)
/Management/MCU_UART_TX: U23.B15 (PA12), U25.3 (Tin)
/Management/MCU_VDDA: C86.1, C89.1, FB6.2, TP13.1 (In), U23.M4 (VDDA)
/Management/PMOD_DQ0: J15.1 (D0), U8.R19 (IO_L19N_T3_A09_D25_VREF_14)
/Management/PMOD_DQ1: J15.2 (D1), U8.R17 (IO_L21P_T3_DQS_14)
/Management/PMOD_DQ2: J15.3 (D2), U8.P16 (IO_L23P_T3_A03_D19_14)
/Management/PMOD_DQ3: J15.4 (D3), U8.M16 (IO_25_14)
/Management/PMOD_DQ4: J15.7 (D4), U8.P19 (IO_L20P_T3_A08_D24_14)
/Management/PMOD_DQ5: J15.8 (D5), U8.R18 (IO_L19P_T3_A10_D26_14)
/Management/PMOD_DQ6: J15.9 (D6), U8.P17 (IO_L21N_T3_DQS_A06_D22_14)
/Management/PMOD_DQ7: J15.10 (D7), U8.N17 (IO_L23N_T3_A02_D18_14)
/Management/RS232_RX: J12.3, J13.1, U25.9 (Rin)
/Management/RS232_RX_RJ45: J13.2, J14.6
/Management/RS232_TX: J12.1, J13.3, U25.8 (Tout)
/Management/RS232_TX_RJ45: J12.2, J14.3
/Management/RX_DAC0_CS_N: TP27.3, U23.N5 (PA3); also elsewhere on the board
/Management/RX_DAC1_CS_N: TP27.4, U23.P5 (PA4); also elsewhere on the board
/Management/SFP_MOD_ABS: U23.C1 (PC13); also elsewhere on the board
/Management/SFP_RX_LOS: U8.G21 (IO_L9P_T1_DQS_14), U23.B2 (PE3); also elsewhere on the board
/Management/SFP_TX_DISABLE: U23.D2 (PC14); also elsewhere on the board
/Management/SFP_TX_FAULT: U23.D1 (PC15); also elsewhere on the board
/Management/VCORE: C80.1, C85.1, TP11.1 (In), U23.A4 (VCAP), U23.A14 (VCAP), U23.R13 (VCAP)
/Management/VLXSMPS: C94.1, L3.2, U23.F1 (VLXSMPS)
/Management/VSMPS: C78.1, C93.1, C98.1, L3.1, TP12.1 (In), U23.A3 (VDDLDO), U23.A13 (VDDLDO), U23.G2 (VFBSMPS), U23.R14 (VDDLDO)
/SOFT_POWER: J48.3; also elsewhere on the board
/SOFT_RESET: J48.8; also elsewhere on the board
/SUPER_SPI_CS_N: U23.B1 (PE4); also elsewhere on the board
/SUPER_SPI_MISO: U23.D3 (PE5); also elsewhere on the board
/SUPER_SPI_MOSI: U23.E3 (PE6); also elsewhere on the board
/SUPER_SPI_SCK: U23.C3 (PE2); also elsewhere on the board
/TX_DAC_CS_N: TP27.2, U23.R9 (PE10); also elsewhere on the board
/Transceivers/SFP_I2C_SCL: U23.F3 (I2C2_SCL); also elsewhere on the board
/Transceivers/SFP_I2C_SDA: U23.F4 (I2C2_SDA); also elsewhere on the board
unnamed: C106.1, U25.11 (C2+)
unnamed: C106.2, U25.10 (C2-)
unnamed: C107.1, U25.7 (V-)
unnamed: C108.1, U25.1 (C1+)
unnamed: C108.2, U25.12 (C1-)
unnamed: C109.1, U25.4 (V+)
unnamed: D15.2 (A), R107.2
unnamed: D16.2 (A), R108.2
unnamed: D17.2 (A), R109.2
unnamed: D18.2 (A), R110.2
unnamed: J9.2, R103.2
unnamed: R113.2, U23.A6 (PB3)
unnamed: R124.2, U32.A4 (RESET_N)
unnamed: R125.2, U31.3 (CLK)
unnamed: R126.1, U32.D3 (MOSI/DQ0)
unnamed: R127.1, U32.D2 (MISO/DQ1)
unnamed: R128.1, U32.C4 (WP_N/DQ2)
unnamed: R129.1, U32.D4 (RESET_N/DQ3)
unnamed: R130.2, U8.H18 (IO_L1P_T0_D00_MOSI_14)
unnamed: R131.2, U8.H19 (IO_L1N_T0_D01_DIN_14)
unnamed: R132.2, U8.G18 (IO_L2P_T0_D02_14)
unnamed: R133.2, U8.F19 (IO_L2N_T0_D03_14)
unnamed: R134.2, U8.M22 (IO_L15N_T2_DQS_DOUT_CSO_B_14)

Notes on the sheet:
MCU VCAP decoupling
MCU VDDLDO decoupling
MCU VDDSMPS decoupling
MCU VDD decoupling
Fan: Noctua NF-A4x20 PWM
MCU VDDA decoupling
Fan PWM signal Vil 0.8V so 3.3V / 5V output should be OK (per Intel spec, Noctua doesn't specify) Has pullup to 5V inside fan, so must be 5V tolerant pin
Address = 8'ha0, 8'hb0
MCU VBAT decoupling
TX/RX crossover jumpers in case we got the RJ45 pinout wrong :)

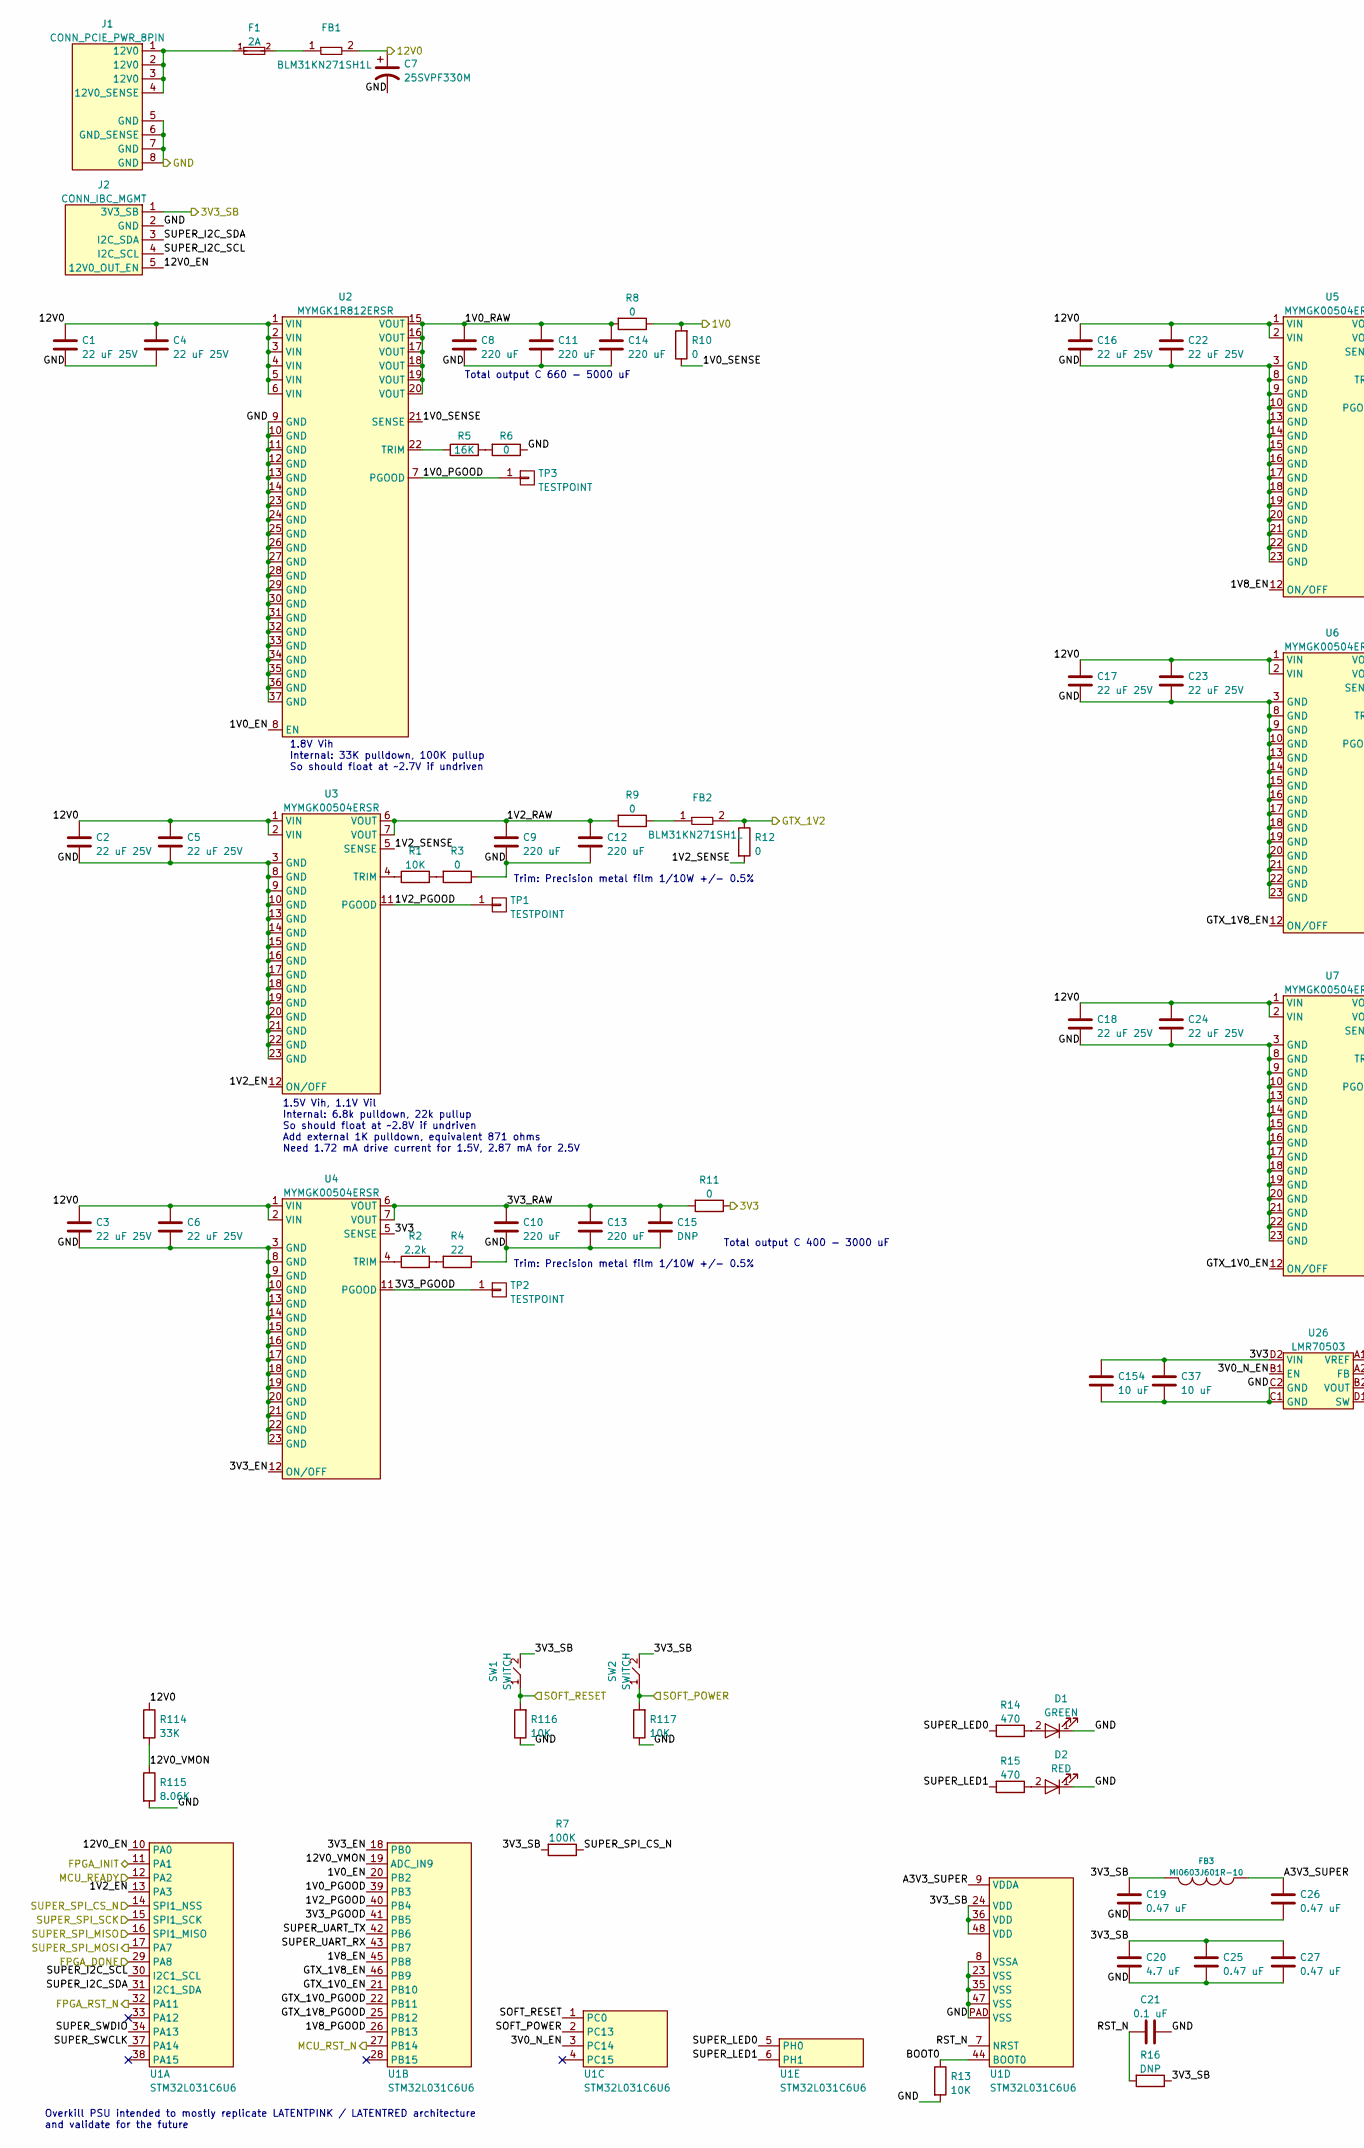
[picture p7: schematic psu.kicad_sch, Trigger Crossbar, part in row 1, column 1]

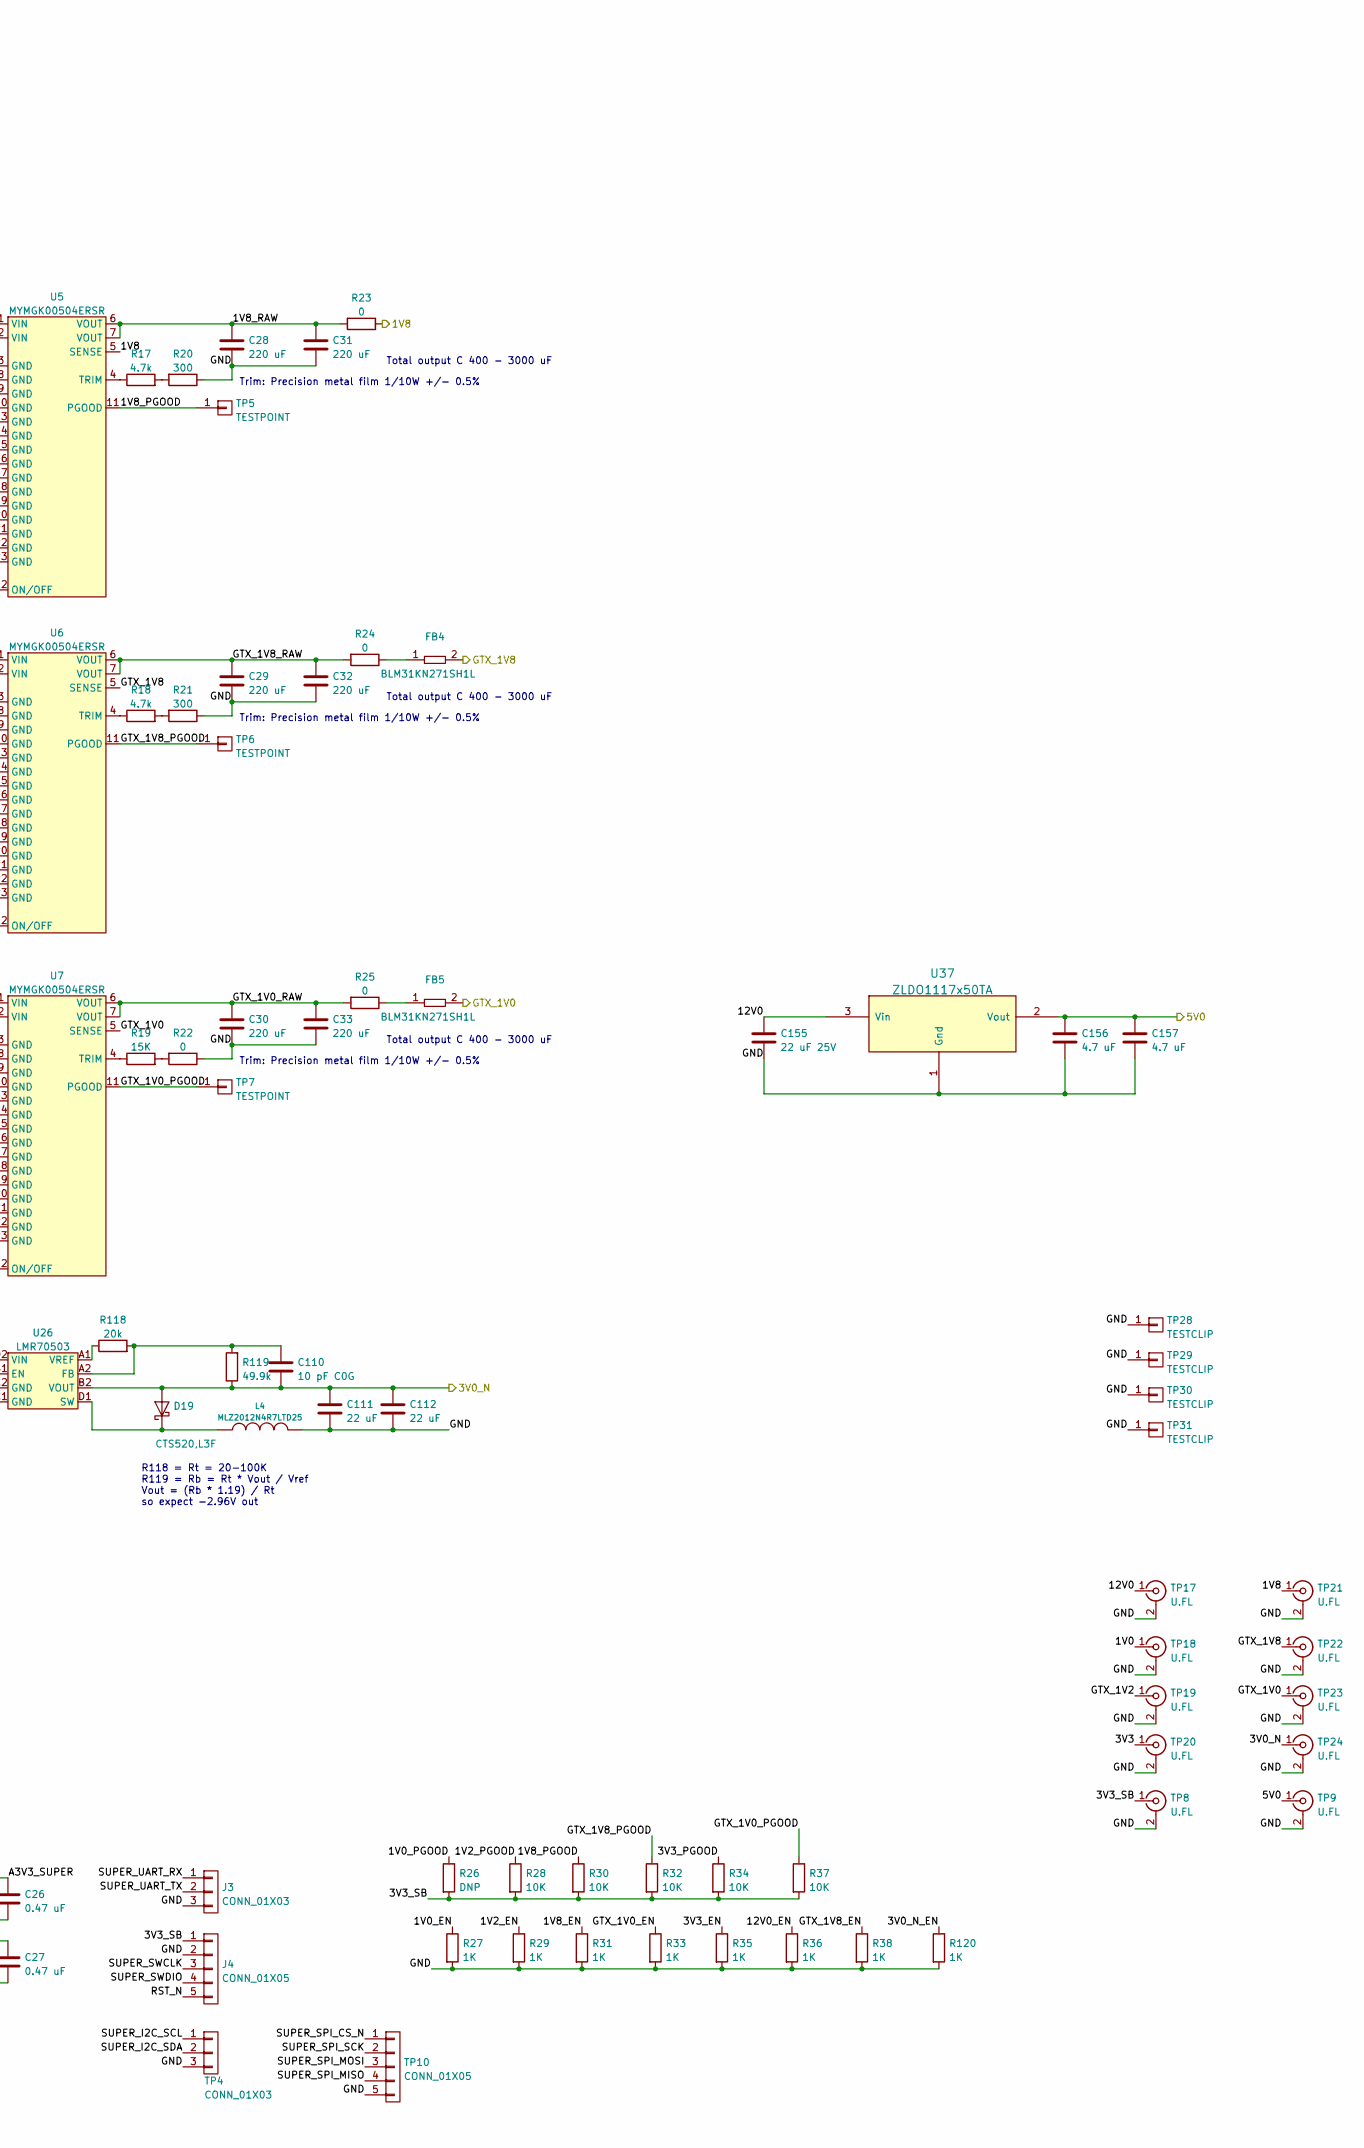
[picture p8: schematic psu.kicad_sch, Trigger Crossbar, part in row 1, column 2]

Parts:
C1, C2, C3, C4, C5, C6, C16, C17, C18, C22, C23, C24, C155: 22 uF 25V; EIA_1812_CAP_NOSILK
C7: 25SVPF330M; CAP_AL_10MM_SMT
C8, C9, C10, C11, C12, C13, C14, C28, C29, C30, C31, C32, C33: 220 uF; EIA_1210_CAP_NOSILK
C15: DNP; EIA_1210_CAP_NOSILK
C19, C25, C26, C27: 0.47 uF; EIA_0402_CAP_NOSILK
C20, C156, C157: 4.7 uF; EIA_0603_CAP_NOSILK
C21: 0.1 uF; EIA_0402_CAP_NOSILK
C37, C154: 10 uF; EIA_0805_CAP_NOSILK
C110: 10 pF C0G; EIA_0402_CAP_NOSILK
C111, C112: 22 uF; EIA_0805_CAP_NOSILK
D1: GREEN; EIA_0603_LED
D2: RED; EIA_0603_LED
D19: CTS520,L3F; SOD882
F1: 2A; EIA_0603_CAP_NOSILK
FB1, FB2, FB4, FB5: BLM31KN271SH1L; EIA_1206_CAP_NOSILK
FB3: MI0603J601R-10; EIA_0603_INDUCTOR_NOSILK
J1: CONN_PCIE_PWR_8PIN; CONN_MOLEX_MINIFITJR_8POS_0039291087
J2: CONN_IBC_MGMT; CONN_MOLEX_PICOBLADE_5POS_0532610571
J3: CONN_01X03; CONN_HEADER_2.54MM_1x3
J4: CONN_01X05; CONN_HEADER_2.54MM_1x5
L4: MLZ2012N4R7LTD25; EIA_0805_INDUCTOR_NOSILK
R1, R13, R28, R30, R32, R34, R37, R116, R117: 10K; EIA_0402_RES_NOSILK
R2: 2.2k; EIA_0402_RES_NOSILK
R3, R6, R8, R9, R10, R11, R12, R22, R23, R24, R25: 0; EIA_0402_RES_NOSILK
R4: 22; EIA_0402_RES_NOSILK
R5: 16K; EIA_0402_RES_NOSILK
R7: 100K; EIA_0402_RES_NOSILK
R14, R15: 470; EIA_0402_RES_NOSILK
R16, R26: DNP; EIA_0402_RES_NOSILK
R17, R18: 4.7k; EIA_0402_RES_NOSILK
R19: 15K; EIA_0402_RES_NOSILK
R20, R21: 300; EIA_0402_RES_NOSILK
R27, R29, R31, R33, R35, R36, R38, R120: 1K; EIA_0402_RES_NOSILK
R114: 33K; EIA_0402_RES_NOSILK
R115: 8.06K; EIA_0402_RES_NOSILK
R118: 20k; EIA_0402_RES_NOSILK
R119: 49.9k; EIA_0402_RES_NOSILK
SW1, SW2: SWITCH; SWITCH_RAFI_MICON_5
TP1, TP2, TP3, TP5, TP6, TP7: TESTPOINT; TESTPOINT_SMT_0.5MM
TP4: CONN_01X03; CONN_HEADER_2.54MM_1x3
TP8, TP9, TP17, TP18, TP19, TP20, TP21, TP22, TP23, TP24: U.FL; CONN_U.FL_TE_1909763-1
TP10: CONN_01X05; CONN_HEADER_2.54MM_1x5
TP28, TP29, TP30, TP31: TESTCLIP; TESTPOINT_SMT_KEYSTONE_5016
U1: STM32L031C6U6; QFN_48_0.5MM_7x7MM
U2: MYMGK1R812ERSR; MODULE_MURATA_MYMGK1R812
U3, U4, U5, U6, U7: MYMGK00504ERSR; MODULE_MURATA_MYMGK00504ERSR
U26: LMR70503; BGA_8_1.65x0.865_0.4MM_TI_YFX
U37: ZLDO1117x50TA; SOT223-4

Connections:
/1V2: FB2.2, R12.1, TP19.1 (In); also elsewhere on the board
/3V0_N: C110.2, C111.1, C112.1, D19.2 (A), R119.1, TP24.1 (In), U26.B2 (VOUT); also elsewhere on the board
/3V3: C37.1, C154.1, R11.1, TP20.1 (In), U4.5 (SENSE), U26.D2 (VIN); also elsewhere on the board
/3V3_SB: C19.1, C20.1, C25.1, C27.1, FB3.2, J2.1 (3V3_SB), J4.1, R7.2, R16.1, R26.2, R28.2, R30.2, R32.2, R34.2, R37.2, SW1.2, SW2.2, TP8.1 (In), U1.24 (VDD), U1.36 (VDD), U1.48 (VDD); also elsewhere on the board
/5V0: C156.1, C157.1, TP9.1 (In), U37.2 (Vout); also elsewhere on the board
/12V0: C1.1, C2.1, C3.1, C4.1, C5.1, C6.1, C7.1, C16.1, C17.1, C18.1, C22.1, C23.1, C24.1, C155.1, FB1.2, R114.1, TP17.1 (In), U2.1 (VIN), U2.2 (VIN), U2.3 (VIN), U2.4 (VIN), U2.5 (VIN), U2.6 (VIN), U3.1 (VIN), U3.2 (VIN), U4.1 (VIN), U4.2 (VIN), U5.1 (VIN), U5.2 (VIN), U6.1 (VIN), U6.2 (VIN), U7.1 (VIN), U7.2 (VIN), U37.3 (Vin); also elsewhere on the board
/FPGA Support/1V0: R8.1, R10.2, TP18.1 (In); also elsewhere on the board
/FPGA Support/FPGA_INIT: U1.11 (PA1); also elsewhere on the board
/FPGA Support/FPGA_RST_N: U1.32 (PA11); also elsewhere on the board
/FPGA Support/GTX_1V0: FB5.2, TP23.1 (In), U7.5 (SENSE); also elsewhere on the board
/FPGA Support/GTX_1V8: FB4.2, TP22.1 (In), U6.5 (SENSE); also elsewhere on the board
/FPGA_DONE: U1.29 (PA8); also elsewhere on the board
/GND: C1.2, C2.2, C3.2, C4.2, C5.2, C6.2, C7.2, C8.2, C9.2, C10.2, C11.2, C12.2, C13.2, C14.2, C15.2, C16.2, C17.2, C18.2, C19.2, C20.2, C21.2, C22.2, C23.2, C24.2, C25.2, C26.2, C27.2, C28.2, C29.2, C30.2, C31.2, C32.2, C33.2, C37.2, C111.2, C112.2, C154.2, C155.2, C156.2, C157.2, D1.1 (K), D2.1 (K), J1.5 (GND), J1.6 (GND_SENSE), J1.7 (GND), J1.8 (GND), J2.2 (GND), J3.3, J4.2, L4.2, R3.1, R4.1, R6.1, R13.2, R20.1, R21.1, R22.1, R27.2, R29.2, R31.2, R33.2, R35.2, R36.2, R38.2, R115.2, R116.1, R117.1, R120.2, TP4.3, TP8.2 (Ext), TP9.2 (Ext), TP10.5, TP17.2 (Ext), TP18.2 (Ext), TP19.2 (Ext), TP20.2 (Ext), TP21.2 (Ext), TP22.2 (Ext), TP23.2 (Ext), TP24.2 (Ext), TP28.1, TP29.1, TP30.1, TP31.1, U1.8 (VSSA), U1.23 (VSS), U1.35 (VSS), U1.47 (VSS), U1.PAD (VSS), U2.9 (GND), U2.10 (GND), U2.11 (GND), U2.12 (GND), U2.13 (GND), U2.14 (GND), U2.23 (GND), U2.24 (GND), U2.25 (GND), U2.26 (GND), U2.27 (GND), U2.28 (GND), U2.29 (GND), U2.30 (GND), U2.31 (GND), U2.32 (GND), U2.33 (GND), U2.34 (GND), U2.35 (GND), U2.36 (GND), U2.37 (GND), U3.3 (GND), U3.8 (GND), U3.9 (GND), U3.10 (GND), U3.13 (GND), U3.14 (GND), U3.15 (GND), U3.16 (GND), U3.17 (GND), U3.18 (GND), U3.19 (GND), U3.20 (GND), U3.21 (GND), U3.22 (GND), U3.23 (GND), U4.3 (GND), U4.8 (GND), U4.9 (GND), U4.10 (GND), U4.13 (GND), U4.14 (GND), U4.15 (GND), U4.16 (GND), U4.17 (GND), U4.18 (GND), U4.19 (GND), U4.20 (GND), U4.21 (GND), U4.22 (GND), U4.23 (GND), U5.3 (GND), U5.8 (GND), U5.9 (GND), U5.10 (GND), U5.13 (GND), U5.14 (GND), U5.15 (GND), U5.16 (GND), U5.17 (GND), U5.18 (GND), U5.19 (GND), U5.20 (GND), U5.21 (GND), U5.22 (GND), U5.23 (GND), U6.3 (GND), U6.8 (GND), U6.9 (GND), U6.10 (GND), U6.13 (GND), U6.14 (GND), U6.15 (GND), U6.16 (GND), U6.17 (GND), U6.18 (GND), U6.19 (GND), U6.20 (GND), U6.21 (GND), U6.22 (GND), U6.23 (GND), U7.3 (GND), U7.8 (GND), U7.9 (GND), U7.10 (GND), U7.13 (GND), U7.14 (GND), U7.15 (GND), U7.16 (GND), U7.17 (GND), U7.18 (GND), U7.19 (GND), U7.20 (GND), U7.21 (GND), U7.22 (GND), U7.23 (GND), U26.C1 (GND), U26.C2 (GND), U37.1 (Gnd); also elsewhere on the board
/MCU_READY: U1.12 (PA2); also elsewhere on the board
/MCU_RST_N: U1.27 (PB14); also elsewhere on the board
/Power Supply/1V0_EN: R27.1, U1.20 (PB2), U2.8 (EN)
/Power Supply/1V0_PGOOD: R26.1, TP3.1, U1.39 (PB3), U2.7 (PGOOD)
/Power Supply/1V0_RAW: C8.1, C11.1, C14.1, R8.2, U2.15 (VOUT), U2.16 (VOUT), U2.17 (VOUT), U2.18 (VOUT), U2.19 (VOUT), U2.20 (VOUT)
/Power Supply/1V0_SENSE: R10.1, U2.21 (SENSE)
/Power Supply/1V2_EN: R29.1, U1.13 (PA3), U3.12 (ON/OFF)
/Power Supply/1V2_PGOOD: R28.1, TP1.1, U1.40 (PB4), U3.11 (PGOOD)
/Power Supply/1V2_RAW: C9.1, C12.1, R9.2, U3.6 (VOUT), U3.7 (VOUT)
/Power Supply/1V2_SENSE: R12.2, U3.5 (SENSE)
/Power Supply/1V8_EN: R31.1, U1.45 (PB8), U5.12 (ON/OFF)
/Power Supply/1V8_PGOOD: R30.1, TP5.1, U1.26 (PB13), U5.11 (PGOOD)
/Power Supply/1V8_RAW: C28.1, C31.1, R23.2, U5.6 (VOUT), U5.7 (VOUT)
/Power Supply/3V0_N_EN: R120.1, U1.3 (PC14), U26.B1 (EN)
/Power Supply/3V3_EN: R35.1, U1.18 (PB0), U4.12 (ON/OFF)
/Power Supply/3V3_PGOOD: R34.1, TP2.1, U1.41 (PB5), U4.11 (PGOOD)
/Power Supply/3V3_RAW: C10.1, C13.1, C15.1, R11.2, U4.6 (VOUT), U4.7 (VOUT)
/Power Supply/12V0_EN: J2.5 (12V0_OUT_EN), R36.1, U1.10 (PA0)
/Power Supply/12V0_VMON: R114.2, R115.1, U1.19 (ADC_IN9)
/Power Supply/A3V3_SUPER: C26.1, FB3.1, U1.9 (VDDA)
/Power Supply/BOOT0: R13.1, U1.44 (BOOT0)
/Power Supply/GTX_1V0_EN: R33.1, U1.21 (PB10), U7.12 (ON/OFF)
/Power Supply/GTX_1V0_PGOOD: R37.1, TP7.1, U1.22 (PB11), U7.11 (PGOOD)
/Power Supply/GTX_1V0_RAW: C30.1, C33.1, R25.2, U7.6 (VOUT), U7.7 (VOUT)
/Power Supply/GTX_1V8_EN: R38.1, U1.46 (PB9), U6.12 (ON/OFF)
/Power Supply/GTX_1V8_PGOOD: R32.1, TP6.1, U1.25 (PB12), U6.11 (PGOOD)
/Power Supply/GTX_1V8_RAW: C29.1, C32.1, R24.2, U6.6 (VOUT), U6.7 (VOUT)
/Power Supply/RST_N: C21.1, J4.5, R16.2, U1.7 (NRST)
/Power Supply/SUPER_I2C_SCL: J2.4 (I2C_SCL), TP4.1, U1.30 (I2C1_SCL)
/Power Supply/SUPER_I2C_SDA: J2.3 (I2C_SDA), TP4.2, U1.31 (I2C1_SDA)
/Power Supply/SUPER_LED0: R14.2, U1.5 (PH0)
/Power Supply/SUPER_LED1: R15.2, U1.6 (PH1)
/Power Supply/SUPER_SWCLK: J4.3, U1.37 (PA14)
/Power Supply/SUPER_SWDIO: J4.4, U1.34 (PA13)
/Power Supply/SUPER_UART_RX: J3.1, U1.43 (PB7)
/Power Supply/SUPER_UART_TX: J3.2, U1.42 (PB6)
/SOFT_POWER: R117.2, SW2.1, U1.2 (PC13); also elsewhere on the board
/SOFT_RESET: R116.2, SW1.1, U1.1 (PC0); also elsewhere on the board
/SUPER_SPI_CS_N: R7.1, TP10.1, U1.14 (SPI1_NSS); also elsewhere on the board
/SUPER_SPI_MISO: TP10.3, U1.17 (PA7); also elsewhere on the board
/SUPER_SPI_MOSI: TP10.4, U1.16 (SPI1_MISO); also elsewhere on the board
/SUPER_SPI_SCK: TP10.2, U1.15 (SPI1_SCK); also elsewhere on the board
unnamed: C110.1, R118.2, R119.2, U26.A2 (FB)
unnamed: D1.2 (A), R14.1
unnamed: D2.2 (A), R15.1
unnamed: D19.1 (K), L4.1, U26.D1 (SW)
unnamed: F1.1, J1.1 (12V0), J1.2 (12V0), J1.3 (12V0), J1.4 (12V0_SENSE)
unnamed: F1.2, FB1.1
unnamed: FB2.1, R9.1
unnamed: FB4.1, R24.1
unnamed: FB5.1, R25.1
unnamed: R1.1, U3.4 (TRIM)
unnamed: R1.2, R3.2
unnamed: R2.1, U4.4 (TRIM)
unnamed: R2.2, R4.2
unnamed: R5.1, U2.22 (TRIM)
unnamed: R5.2, R6.2
unnamed: R17.1, U5.4 (TRIM)
unnamed: R17.2, R20.2
unnamed: R18.1, U6.4 (TRIM)
unnamed: R18.2, R21.2
unnamed: R19.1, U7.4 (TRIM)
unnamed: R19.2, R22.2
unnamed: R118.1, U26.A1 (VREF)

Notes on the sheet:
Trim: Precision metal film 1/10W +/- 0.5%
Total output C 400 - 3000 uF
Overkill PSU intended to mostly replicate LATENTPINK / LATENTRED architecture and validate for the future
R118 = Rt = 20-100K R119 = Rb = Rt * Vout / Vref Vout = (Rb * 1.19) / Rt so expect -2.96V out
1.8V Vih Internal: 33K pulldown, 100K pullup So should float at ~2.7V if undriven
Total output C 660 - 5000 uF
1.5V Vih, 1.1V Vil Internal: 6.8k pulldown, 22k pullup So should float at ~2.8V if undriven Add external 1K pulldown, equivalent 871 ohms Need 1.72 mA drive current for 1.5V, 2.87 mA for 2.5V

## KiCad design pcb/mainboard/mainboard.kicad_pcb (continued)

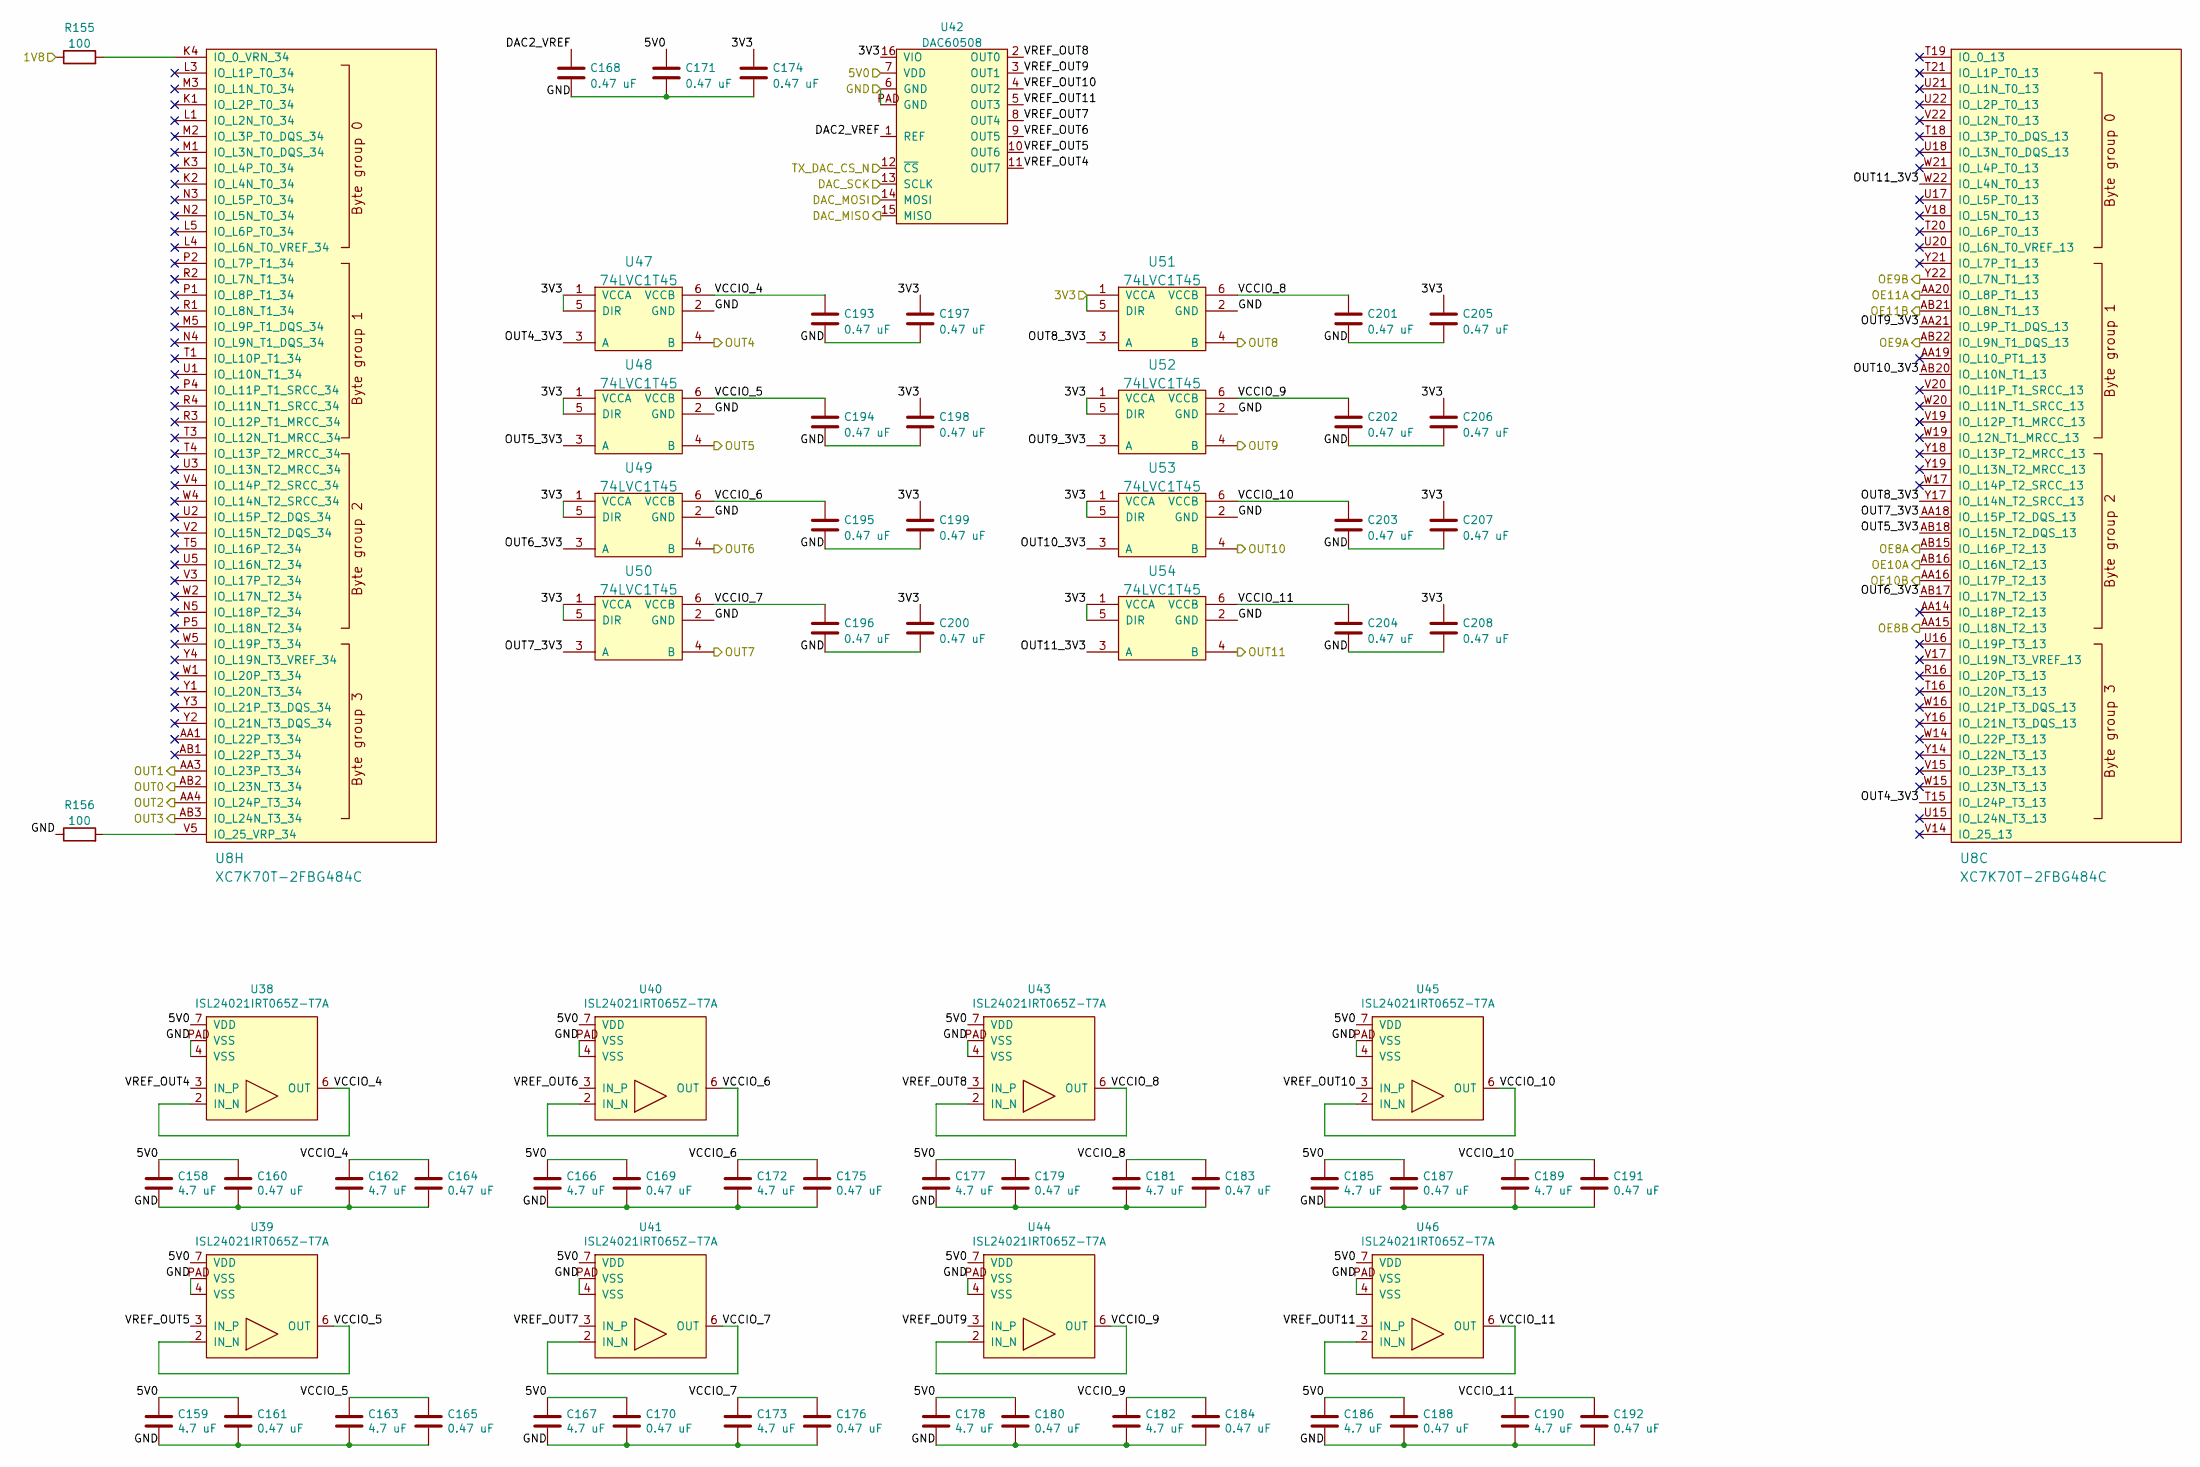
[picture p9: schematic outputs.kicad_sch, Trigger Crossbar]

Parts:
C158, C159, C162, C163, C166, C167, C172, C173, C177, C178, C181, C182, C185, C186, C189, C190: 4.7 uF; EIA_0603_CAP_NOSILK
C160, C161, C164, C165, C168, C169, C170, C171, C174, C175, C176, C179, C180, C183, C184, C187, C188, C191, C192, C193, C194, C195, C196, C197, C198, C199, C200, C201, C202, C203, C204, C205, C206, C207, C208: 0.47 uF; EIA_0402_CAP_NOSILK
R155, R156: 100; EIA_0402_RES_NOSILK
U8: XC7K70T-2FBG484C; BGA_484_22x22_FULLARRAY_1MM
U38, U39, U40, U41, U43, U44, U45, U46: ISL24021IRT065Z-T7A‎; DFN_8_0.65MM_3x3MM
U42: DAC60508; QFN_16_0.5MM_3x3MM
U47, U48, U49, U50, U51, U52, U53, U54: 74LVC1T45; DFN_6_0.5MM_1.6x1.6MM_TI_DPK

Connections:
/3V3: C174.1, C197.1, C198.1, C199.1, C200.1, C205.1, C206.1, C207.1, C208.1, U42.16 (VIO), U47.1 (VCCA), U47.5 (DIR), U48.1 (VCCA), U48.5 (DIR), U49.1 (VCCA), U49.5 (DIR), U50.1 (VCCA), U50.5 (DIR), U51.1 (VCCA), U51.5 (DIR), U52.1 (VCCA), U52.5 (DIR), U53.1 (VCCA), U53.5 (DIR), U54.1 (VCCA), U54.5 (DIR); also elsewhere on the board
/5V0: C158.1, C159.1, C160.1, C161.1, C166.1, C167.1, C169.1, C170.1, C171.1, C177.1, C178.1, C179.1, C180.1, C185.1, C186.1, C187.1, C188.1, U38.7 (VDD), U39.7 (VDD), U40.7 (VDD), U41.7 (VDD), U42.7 (VDD), U43.7 (VDD), U44.7 (VDD), U45.7 (VDD), U46.7 (VDD); also elsewhere on the board
/Connectors/OE8A: U8.AB15 (IO_L16P_T2_13); also elsewhere on the board
/Connectors/OE8B: U8.AA15 (IO_L18N_T2_13); also elsewhere on the board
/Connectors/OE9A: U8.AB22 (IO_L9N_T1_DQS_13); also elsewhere on the board
/Connectors/OE9B: U8.Y22 (IO_L7N_T1_13); also elsewhere on the board
/Connectors/OE10A: U8.AB16 (IO_L16N_T2_13); also elsewhere on the board
/Connectors/OE10B: U8.AA16 (IO_L17P_T2_13); also elsewhere on the board
/Connectors/OE11A: U8.AA20 (IO_L8P_T1_13); also elsewhere on the board
/Connectors/OE11B: U8.AB21 (IO_L8N_T1_13); also elsewhere on the board
/Connectors/OUT0: U8.AB2 (IO_L23N_T3_34); also elsewhere on the board
/Connectors/OUT1: U8.AA3 (IO_L23P_T3_34); also elsewhere on the board
/Connectors/OUT2: U8.AA4 (IO_L24P_T3_34); also elsewhere on the board
/Connectors/OUT3: U8.AB3 (IO_L24N_T3_34); also elsewhere on the board
/Connectors/OUT4: U47.4 (B); also elsewhere on the board
/Connectors/OUT5: U48.4 (B); also elsewhere on the board
/Connectors/OUT6: U49.4 (B); also elsewhere on the board
/Connectors/OUT7: U50.4 (B); also elsewhere on the board
/Connectors/OUT8: U51.4 (B); also elsewhere on the board
/Connectors/OUT9: U52.4 (B); also elsewhere on the board
/Connectors/OUT10: U53.4 (B); also elsewhere on the board
/Connectors/OUT11: U54.4 (B); also elsewhere on the board
/DAC_MISO: U42.15 (MISO); also elsewhere on the board
/DAC_MOSI: U42.14 (MOSI); also elsewhere on the board
/DAC_SCK: U42.13 (SCLK); also elsewhere on the board
/GND: C158.2, C159.2, C160.2, C161.2, C162.2, C163.2, C164.2, C165.2, C166.2, C167.2, C168.2, C169.2, C170.2, C171.2, C172.2, C173.2, C174.2, C175.2, C176.2, C177.2, C178.2, C179.2, C180.2, C181.2, C182.2, C183.2, C184.2, C185.2, C186.2, C187.2, C188.2, C189.2, C190.2, C191.2, C192.2, C193.2, C194.2, C195.2, C196.2, C197.2, C198.2, C199.2, C200.2, C201.2, C202.2, C203.2, C204.2, C205.2, C206.2, C207.2, C208.2, R156.1, U38.4 (VSS), U38.PAD (VSS), U39.4 (VSS), U39.PAD (VSS), U40.4 (VSS), U40.PAD (VSS), U41.4 (VSS), U41.PAD (VSS), U42.6 (GND), U42.PAD (GND), U43.4 (VSS), U43.PAD (VSS), U44.4 (VSS), U44.PAD (VSS), U45.4 (VSS), U45.PAD (VSS), U46.4 (VSS), U46.PAD (VSS), U47.2 (GND), U48.2 (GND), U49.2 (GND), U50.2 (GND), U51.2 (GND), U52.2 (GND), U53.2 (GND), U54.2 (GND); also elsewhere on the board
/Output/DAC2_VREF: C168.1, U42.1 (REF)
/Output/OUT4_3V3: U8.T15 (IO_L24P_T3_13), U47.3 (A)
/Output/OUT5_3V3: U8.AB18 (IO_L15N_T2_DQS_13), U48.3 (A)
/Output/OUT6_3V3: U8.AB17 (IO_L17N_T2_13), U49.3 (A)
/Output/OUT7_3V3: U8.AA18 (IO_L15P_T2_DQS_13), U50.3 (A)
/Output/OUT8_3V3: U8.Y17 (IO_L14N_T2_SRCC_13), U51.3 (A)
/Output/OUT9_3V3: U8.AA21 (IO_L9P_T1_DQS_13), U52.3 (A)
/Output/OUT10_3V3: U8.AB20 (IO_L10N_T1_13), U53.3 (A)
/Output/OUT11_3V3: U8.W22 (IO_L4N_T0_13), U54.3 (A)
/Output/VCCIO_4: C162.1, C164.1, C193.1, U38.2 (IN_N), U38.6 (OUT), U47.6 (VCCB)
/Output/VCCIO_5: C163.1, C165.1, C194.1, U39.2 (IN_N), U39.6 (OUT), U48.6 (VCCB)
/Output/VCCIO_6: C172.1, C175.1, C195.1, U40.2 (IN_N), U40.6 (OUT), U49.6 (VCCB)
/Output/VCCIO_7: C173.1, C176.1, C196.1, U41.2 (IN_N), U41.6 (OUT), U50.6 (VCCB)
/Output/VCCIO_8: C181.1, C183.1, C201.1, U43.2 (IN_N), U43.6 (OUT), U51.6 (VCCB)
/Output/VCCIO_9: C182.1, C184.1, C202.1, U44.2 (IN_N), U44.6 (OUT), U52.6 (VCCB)
/Output/VCCIO_10: C189.1, C191.1, C203.1, U45.2 (IN_N), U45.6 (OUT), U53.6 (VCCB)
/Output/VCCIO_11: C190.1, C192.1, C204.1, U46.2 (IN_N), U46.6 (OUT), U54.6 (VCCB)
/Output/VREF_OUT4: U38.3 (IN_P), U42.11 (OUT7)
/Output/VREF_OUT5: U39.3 (IN_P), U42.10 (OUT6)
/Output/VREF_OUT6: U40.3 (IN_P), U42.9 (OUT5)
/Output/VREF_OUT7: U41.3 (IN_P), U42.8 (OUT4)
/Output/VREF_OUT8: U42.2 (OUT0), U43.3 (IN_P)
/Output/VREF_OUT9: U42.3 (OUT1), U44.3 (IN_P)
/Output/VREF_OUT10: U42.4 (OUT2), U45.3 (IN_P)
/Output/VREF_OUT11: U42.5 (OUT3), U46.3 (IN_P)
/TX_DAC_CS_N: U42.12 (~CS); also elsewhere on the board
unnamed: R155.2, U8.K4 (IO_0_VRN_34)
unnamed: R156.2, U8.V5 (IO_25_VRP_34)

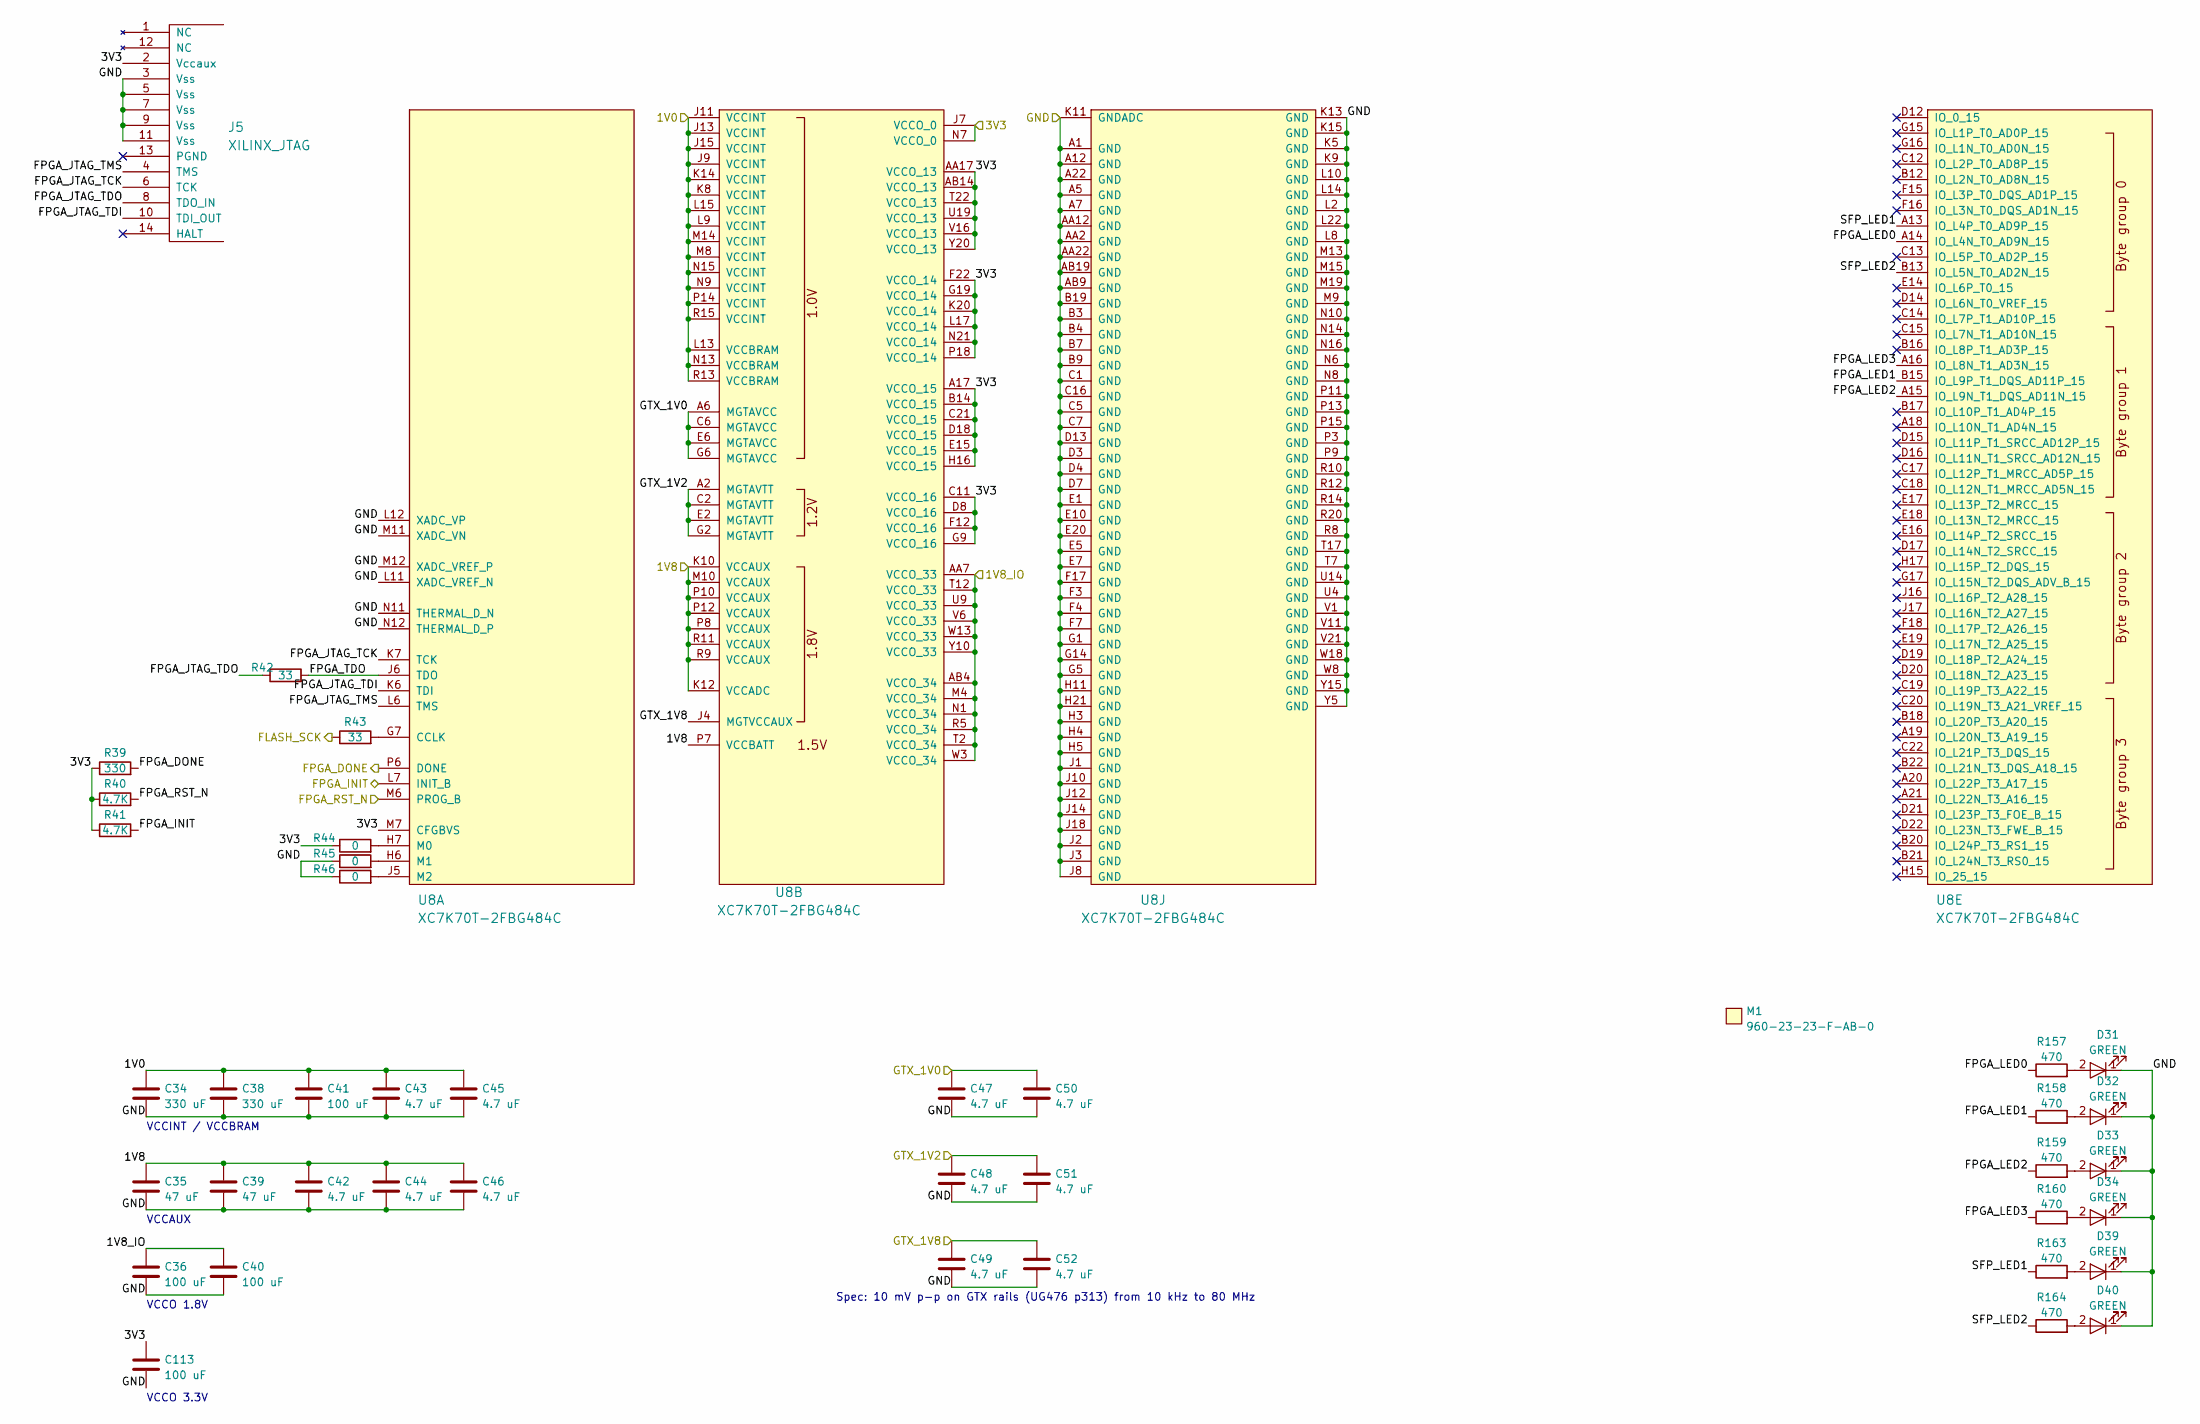
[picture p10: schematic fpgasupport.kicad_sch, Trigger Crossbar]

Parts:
C34, C38: 330 uF; EIA_1210_CAP_NOSILK
C35, C39: 47 uF; EIA_1210_CAP_NOSILK
C36, C40, C41: 100 uF; EIA_1206_CAP_NOSILK
C42, C43, C44, C45, C46, C47, C48, C49, C50, C51, C52: 4.7 uF; EIA_0603_CAP_NOSILK
C113: 100 uF; EIA_1210_CAP_NOSILK
D31, D32, D33, D34, D39, D40: GREEN; EIA_0603_LED
J5: XILINX_JTAG; XILINX_JTAG_PTH_MOLEX_0878311420
M1: 960-23-23-F-AB-0; HEATSINK_WAKEFIELDVETTE_960-23-23-F-AB-0
R39: 330; EIA_0402_RES_NOSILK
R40, R41: 4.7K; EIA_0402_RES_NOSILK
R42, R43: 33; EIA_0402_RES_NOSILK
R44, R45, R46: 0; EIA_0402_RES_NOSILK
R157, R158, R159, R160, R163, R164: 470; EIA_0402_RES_NOSILK
U8: XC7K70T-2FBG484C; BGA_484_22x22_FULLARRAY_1MM

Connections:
/1V2: C48.1, C51.1, U8.A2 (MGTAVTT), U8.C2 (MGTAVTT), U8.E2 (MGTAVTT), U8.G2 (MGTAVTT); also elsewhere on the board
/3V3: C113.1, J5.2 (Vccaux), R39.1, R40.1, R41.1, R44.1, U8.A17 (VCCO_15), U8.AA17 (VCCO_13), U8.AB14 (VCCO_13), U8.B14 (VCCO_15), U8.C11 (VCCO_16), U8.C21 (VCCO_15), U8.D8 (VCCO_16), U8.D18 (VCCO_15), U8.E15 (VCCO_15), U8.F12 (VCCO_16), U8.F22 (VCCO_14), U8.G9 (VCCO_16), U8.G19 (VCCO_14), U8.H16 (VCCO_15), U8.J7 (VCCO_0), U8.K20 (VCCO_14), U8.L17 (VCCO_14), U8.M7 (CFGBVS), U8.N7 (VCCO_0), U8.N21 (VCCO_14), U8.P18 (VCCO_14), U8.T22 (VCCO_13), U8.U19 (VCCO_13), U8.V16 (VCCO_13), U8.Y20 (VCCO_13); also elsewhere on the board
/FLASH_SCK: R43.1; also elsewhere on the board
/FPGA Support/1V0: C34.1, C38.1, C41.1, C43.1, C45.1, U8.J9 (VCCINT), U8.J11 (VCCINT), U8.J13 (VCCINT), U8.J15 (VCCINT), U8.K8 (VCCINT), U8.K14 (VCCINT), U8.L9 (VCCINT), U8.L13 (VCCBRAM), U8.L15 (VCCINT), U8.M8 (VCCINT), U8.M14 (VCCINT), U8.N9 (VCCINT), U8.N13 (VCCBRAM), U8.N15 (VCCINT), U8.P14 (VCCINT), U8.R13 (VCCBRAM), U8.R15 (VCCINT); also elsewhere on the board
/FPGA Support/FPGA_INIT: R41.2, U8.L7 (INIT_B); also elsewhere on the board
/FPGA Support/FPGA_JTAG_TCK: J5.6 (TCK), U8.K7 (TCK)
/FPGA Support/FPGA_JTAG_TDI: J5.10 (TDI_OUT), U8.K6 (TDI)
/FPGA Support/FPGA_JTAG_TDO: J5.8 (TDO_IN), R42.2
/FPGA Support/FPGA_JTAG_TMS: J5.4 (TMS), U8.L6 (TMS)
/FPGA Support/FPGA_LED0: R157.1, U8.A14 (IO_L4N_T0_AD9N_15)
/FPGA Support/FPGA_LED1: R158.1, U8.B15 (IO_L9P_T1_DQS_AD11P_15)
/FPGA Support/FPGA_LED2: R159.1, U8.A15 (IO_L9N_T1_DQS_AD11N_15)
/FPGA Support/FPGA_LED3: R160.1, U8.A16 (IO_L8N_T1_AD3N_15)
/FPGA Support/FPGA_RST_N: R40.2, U8.M6 (PROG_B); also elsewhere on the board
/FPGA Support/FPGA_TDO: R42.1, U8.J6 (TDO)
/FPGA Support/GTX_1V0: C47.1, C50.1, U8.A6 (MGTAVCC), U8.C6 (MGTAVCC), U8.E6 (MGTAVCC), U8.G6 (MGTAVCC); also elsewhere on the board
/FPGA Support/GTX_1V8: C49.1, C52.1, U8.J4 (MGTVCCAUX); also elsewhere on the board
/FPGA Support/SFP_LED1: R163.1, U8.A13 (IO_L4P_T0_AD9P_15)
/FPGA Support/SFP_LED2: R164.1, U8.B13 (IO_L5N_T0_AD2N_15)
/FPGA_DONE: R39.2, U8.P6 (DONE); also elsewhere on the board
/GND: C34.2, C35.2, C36.2, C38.2, C39.2, C40.2, C41.2, C42.2, C43.2, C44.2, C45.2, C46.2, C47.2, C48.2, C49.2, C50.2, C51.2, C52.2, C113.2, D31.1 (K), D32.1 (K), D33.1 (K), D34.1 (K), D39.1 (K), D40.1 (K), J5.3 (Vss), J5.5 (Vss), J5.7 (Vss), J5.9 (Vss), J5.11 (Vss), R45.1, R46.1, U8.A1 (GND), U8.A5 (GND), U8.A7 (GND), U8.A12 (GND), U8.A22 (GND), U8.AA2 (GND), U8.AA12 (GND), U8.AA22 (GND), U8.AB9 (GND), U8.AB19 (GND), U8.B3 (GND), U8.B4 (GND), U8.B7 (GND), U8.B9 (GND), U8.B19 (GND), U8.C1 (GND), U8.C5 (GND), U8.C7 (GND), U8.C16 (GND), U8.D3 (GND), U8.D4 (GND), U8.D7 (GND), U8.D13 (GND), U8.E1 (GND), U8.E5 (GND), U8.E7 (GND), U8.E10 (GND), U8.E20 (GND), U8.F3 (GND), U8.F4 (GND), U8.F7 (GND), U8.F17 (GND), U8.G1 (GND), U8.G5 (GND), U8.G14 (GND), U8.H3 (GND), U8.H4 (GND), U8.H5 (GND), U8.H11 (GND), U8.H21 (GND), U8.J1 (GND), U8.J2 (GND), U8.J3 (GND), U8.J8 (GND), U8.J10 (GND), U8.J12 (GND), U8.J14 (GND), U8.J18 (GND), U8.K5 (GND), U8.K9 (GND), U8.K11 (GNDADC), U8.K13 (GND), U8.K15 (GND), U8.L2 (GND), U8.L8 (GND), U8.L10 (GND), U8.L11 (XADC_VREF_N), U8.L12 (XADC_VP), U8.L14 (GND), U8.L22 (GND), U8.M9 (GND), U8.M11 (XADC_VN), U8.M12 (XADC_VREF_P), U8.M13 (GND), U8.M15 (GND), U8.M19 (GND), U8.N6 (GND), U8.N8 (GND), U8.N10 (GND), U8.N11 (THERMAL_D_N), U8.N12 (THERMAL_D_P), U8.N14 (GND), U8.N16 (GND), U8.P3 (GND), U8.P9 (GND), U8.P11 (GND), U8.P13 (GND), U8.P15 (GND), U8.R8 (GND), U8.R10 (GND), U8.R12 (GND), U8.R14 (GND), U8.R20 (GND), U8.T7 (GND), U8.T17 (GND), U8.U4 (GND), U8.U14 (GND), U8.V1 (GND), U8.V11 (GND), U8.V21 (GND), U8.W8 (GND), U8.W18 (GND), U8.Y5 (GND), U8.Y15 (GND); also elsewhere on the board
unnamed: D31.2 (A), R157.2
unnamed: D32.2 (A), R158.2
unnamed: D33.2 (A), R159.2
unnamed: D34.2 (A), R160.2
unnamed: D39.2 (A), R163.2
unnamed: D40.2 (A), R164.2
unnamed: R43.2, U8.G7 (CCLK)
unnamed: R44.2, U8.H7 (M0)
unnamed: R45.2, U8.H6 (M1)
unnamed: R46.2, U8.J5 (M2)

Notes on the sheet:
VCCO 1.8V
VCCAUX
Spec: 10 mV p-p on GTX rails (UG476 p313) from 10 kHz to 80 MHz
VCCO 3.3V
VCCINT / VCCBRAM

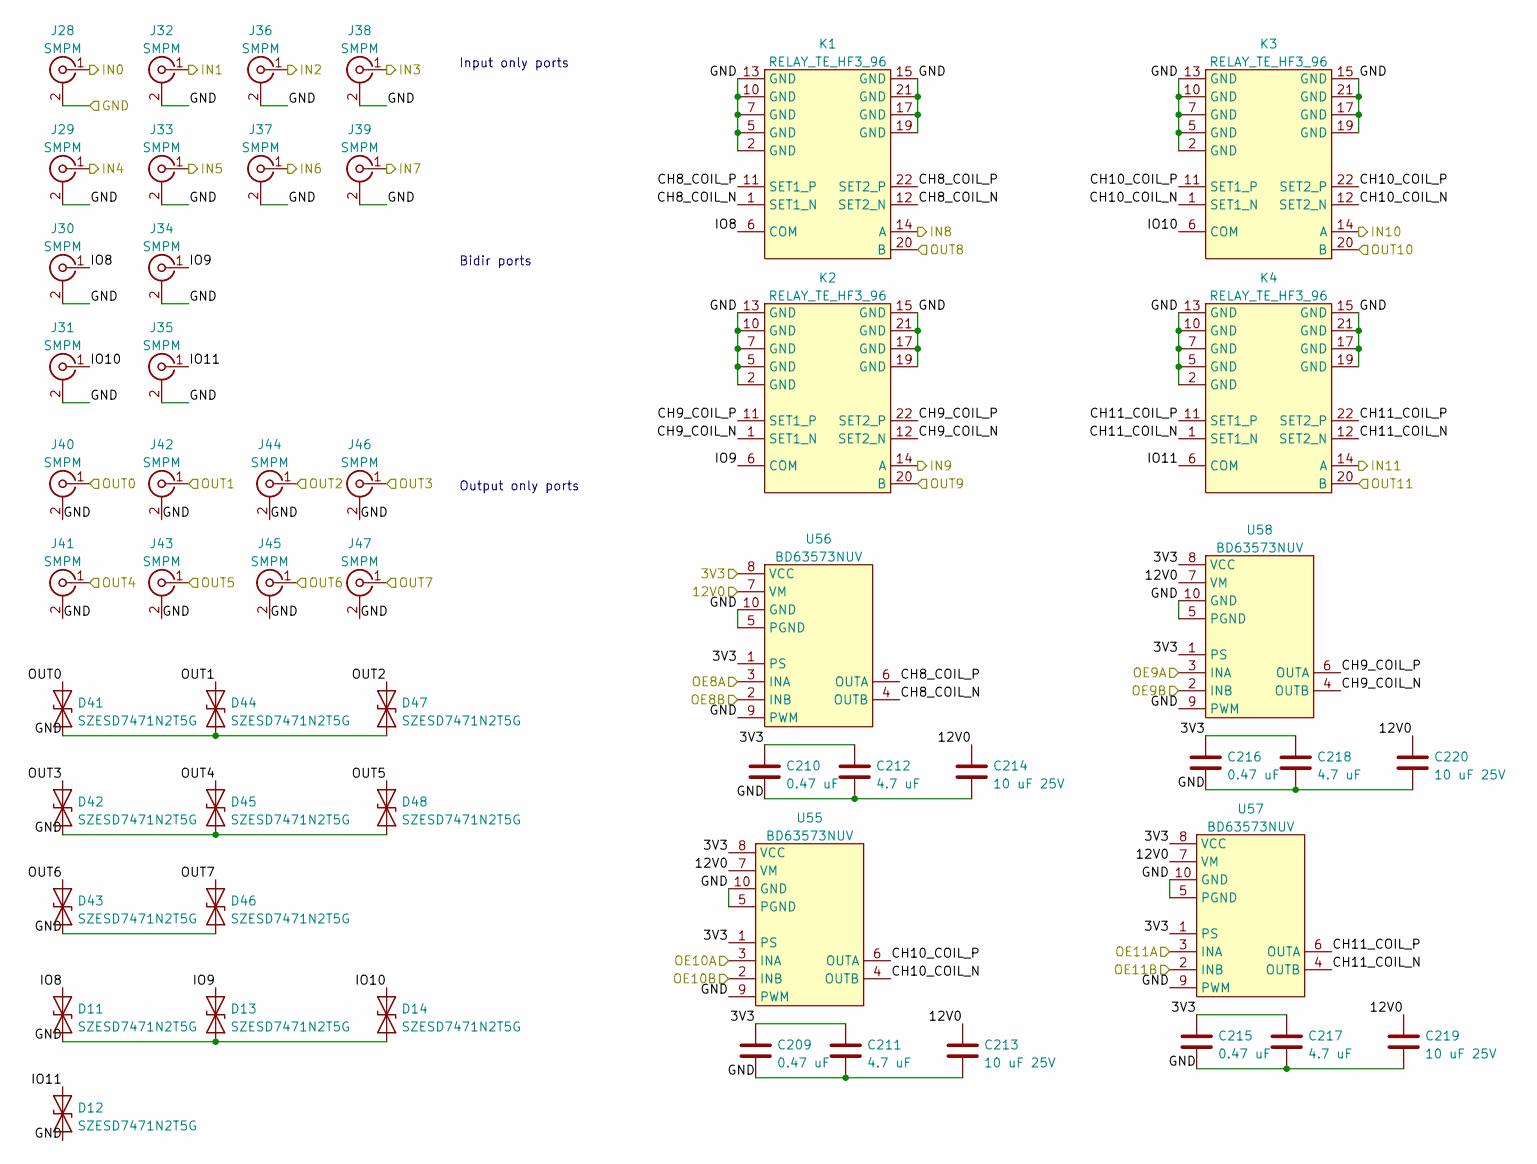
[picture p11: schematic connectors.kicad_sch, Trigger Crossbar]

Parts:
C209, C210, C215, C216: 0.47 uF; EIA_0402_CAP_NOSILK
C211, C212, C217, C218: 4.7 uF; EIA_0603_CAP_NOSILK
C213, C214, C219, C220: 10 uF 25V; EIA_1210_CAP_NOSILK
D11, D12, D13, D14, D41, D42, D43, D44, D45, D46, D47, D48: SZESD7471N2T5G; SOD882
J28, J29, J30, J31, J32, J33, J34, J35, J36, J37, J38, J39, J40, J41, J42, J43, J44, J45, J46, J47: SMPM; CONN_SMPM_AMPHENOL_C925-197J-51PT
K1, K2, K3, K4: RELAY_TE_HF3_96; RELAY_TE_HF3_2COIL_50OHM
U55, U56, U57, U58: BD63573NUV; DFN_10_0.5MM_3x3MM

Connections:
/3V3: C209.1, C210.1, C211.1, C212.1, C215.1, C216.1, C217.1, C218.1, U55.1 (PS), U55.8 (VCC), U56.1 (PS), U56.8 (VCC), U57.1 (PS), U57.8 (VCC), U58.1 (PS), U58.8 (VCC); also elsewhere on the board
/12V0: C213.1, C214.1, C219.1, C220.1, U55.7 (VM), U56.7 (VM), U57.7 (VM), U58.7 (VM); also elsewhere on the board
/Connectors/CH8_COIL_N: K1.1 (SET1_N), K1.12 (SET2_N), U56.4 (OUTB)
/Connectors/CH8_COIL_P: K1.11 (SET1_P), K1.22 (SET2_P), U56.6 (OUTA)
/Connectors/CH9_COIL_N: K2.1 (SET1_N), K2.12 (SET2_N), U58.4 (OUTB)
/Connectors/CH9_COIL_P: K2.11 (SET1_P), K2.22 (SET2_P), U58.6 (OUTA)
/Connectors/CH10_COIL_N: K3.1 (SET1_N), K3.12 (SET2_N), U55.4 (OUTB)
/Connectors/CH10_COIL_P: K3.11 (SET1_P), K3.22 (SET2_P), U55.6 (OUTA)
/Connectors/CH11_COIL_N: K4.1 (SET1_N), K4.12 (SET2_N), U57.4 (OUTB)
/Connectors/CH11_COIL_P: K4.11 (SET1_P), K4.22 (SET2_P), U57.6 (OUTA)
/Connectors/IN0: J28.1 (In); also elsewhere on the board
/Connectors/IN1: J32.1 (In); also elsewhere on the board
/Connectors/IN2: J36.1 (In); also elsewhere on the board
/Connectors/IN3: J38.1 (In); also elsewhere on the board
/Connectors/IN4: J29.1 (In); also elsewhere on the board
/Connectors/IN5: J33.1 (In); also elsewhere on the board
/Connectors/IN6: J37.1 (In); also elsewhere on the board
/Connectors/IN7: J39.1 (In); also elsewhere on the board
/Connectors/IN8: K1.14 (A); also elsewhere on the board
/Connectors/IN9: K2.14 (A); also elsewhere on the board
/Connectors/IN10: K3.14 (A); also elsewhere on the board
/Connectors/IN11: K4.14 (A); also elsewhere on the board
/Connectors/IO8: D11.2 (A2), J30.1 (In), K1.6 (COM)
/Connectors/IO9: D13.2 (A2), J34.1 (In), K2.6 (COM)
/Connectors/IO10: D14.2 (A2), J31.1 (In), K3.6 (COM)
/Connectors/IO11: D12.2 (A2), J35.1 (In), K4.6 (COM)
/Connectors/OE8A: U56.3 (INA); also elsewhere on the board
/Connectors/OE8B: U56.2 (INB); also elsewhere on the board
/Connectors/OE9A: U58.3 (INA); also elsewhere on the board
/Connectors/OE9B: U58.2 (INB); also elsewhere on the board
/Connectors/OE10A: U55.3 (INA); also elsewhere on the board
/Connectors/OE10B: U55.2 (INB); also elsewhere on the board
/Connectors/OE11A: U57.3 (INA); also elsewhere on the board
/Connectors/OE11B: U57.2 (INB); also elsewhere on the board
/Connectors/OUT0: D41.2 (A2), J40.1 (In); also elsewhere on the board
/Connectors/OUT1: D44.2 (A2), J42.1 (In); also elsewhere on the board
/Connectors/OUT2: D47.2 (A2), J44.1 (In); also elsewhere on the board
/Connectors/OUT3: D42.2 (A2), J46.1 (In); also elsewhere on the board
/Connectors/OUT4: D45.2 (A2), J41.1 (In); also elsewhere on the board
/Connectors/OUT5: D48.2 (A2), J43.1 (In); also elsewhere on the board
/Connectors/OUT6: D43.2 (A2), J45.1 (In); also elsewhere on the board
/Connectors/OUT7: D46.2 (A2), J47.1 (In); also elsewhere on the board
/Connectors/OUT8: K1.20 (B); also elsewhere on the board
/Connectors/OUT9: K2.20 (B); also elsewhere on the board
/Connectors/OUT10: K3.20 (B); also elsewhere on the board
/Connectors/OUT11: K4.20 (B); also elsewhere on the board
/GND: C209.2, C210.2, C211.2, C212.2, C213.2, C214.2, C215.2, C216.2, C217.2, C218.2, C219.2, C220.2, D11.1 (A1), D12.1 (A1), D13.1 (A1), D14.1 (A1), D41.1 (A1), D42.1 (A1), D43.1 (A1), D44.1 (A1), D45.1 (A1), D46.1 (A1), D47.1 (A1), D48.1 (A1), J28.2 (Ext), J29.2 (Ext), J30.2 (Ext), J31.2 (Ext), J32.2 (Ext), J33.2 (Ext), J34.2 (Ext), J35.2 (Ext), J36.2 (Ext), J37.2 (Ext), J38.2 (Ext), J39.2 (Ext), J40.2 (Ext), J41.2 (Ext), J42.2 (Ext), J43.2 (Ext), J44.2 (Ext), J45.2 (Ext), J46.2 (Ext), J47.2 (Ext), K1.2 (GND), K1.5 (GND), K1.7 (GND), K1.10 (GND), K1.13 (GND), K1.15 (GND), K1.17 (GND), K1.19 (GND), K1.21 (GND), K2.2 (GND), K2.5 (GND), K2.7 (GND), K2.10 (GND), K2.13 (GND), K2.15 (GND), K2.17 (GND), K2.19 (GND), K2.21 (GND), K3.2 (GND), K3.5 (GND), K3.7 (GND), K3.10 (GND), K3.13 (GND), K3.15 (GND), K3.17 (GND), K3.19 (GND), K3.21 (GND), K4.2 (GND), K4.5 (GND), K4.7 (GND), K4.10 (GND), K4.13 (GND), K4.15 (GND), K4.17 (GND), K4.19 (GND), K4.21 (GND), U55.5 (PGND), U55.9 (PWM), U55.10 (GND), U56.5 (PGND), U56.9 (PWM), U56.10 (GND), U57.5 (PGND), U57.9 (PWM), U57.10 (GND), U58.5 (PGND), U58.9 (PWM), U58.10 (GND); also elsewhere on the board

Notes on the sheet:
Bidir ports
Input only ports
Output only ports

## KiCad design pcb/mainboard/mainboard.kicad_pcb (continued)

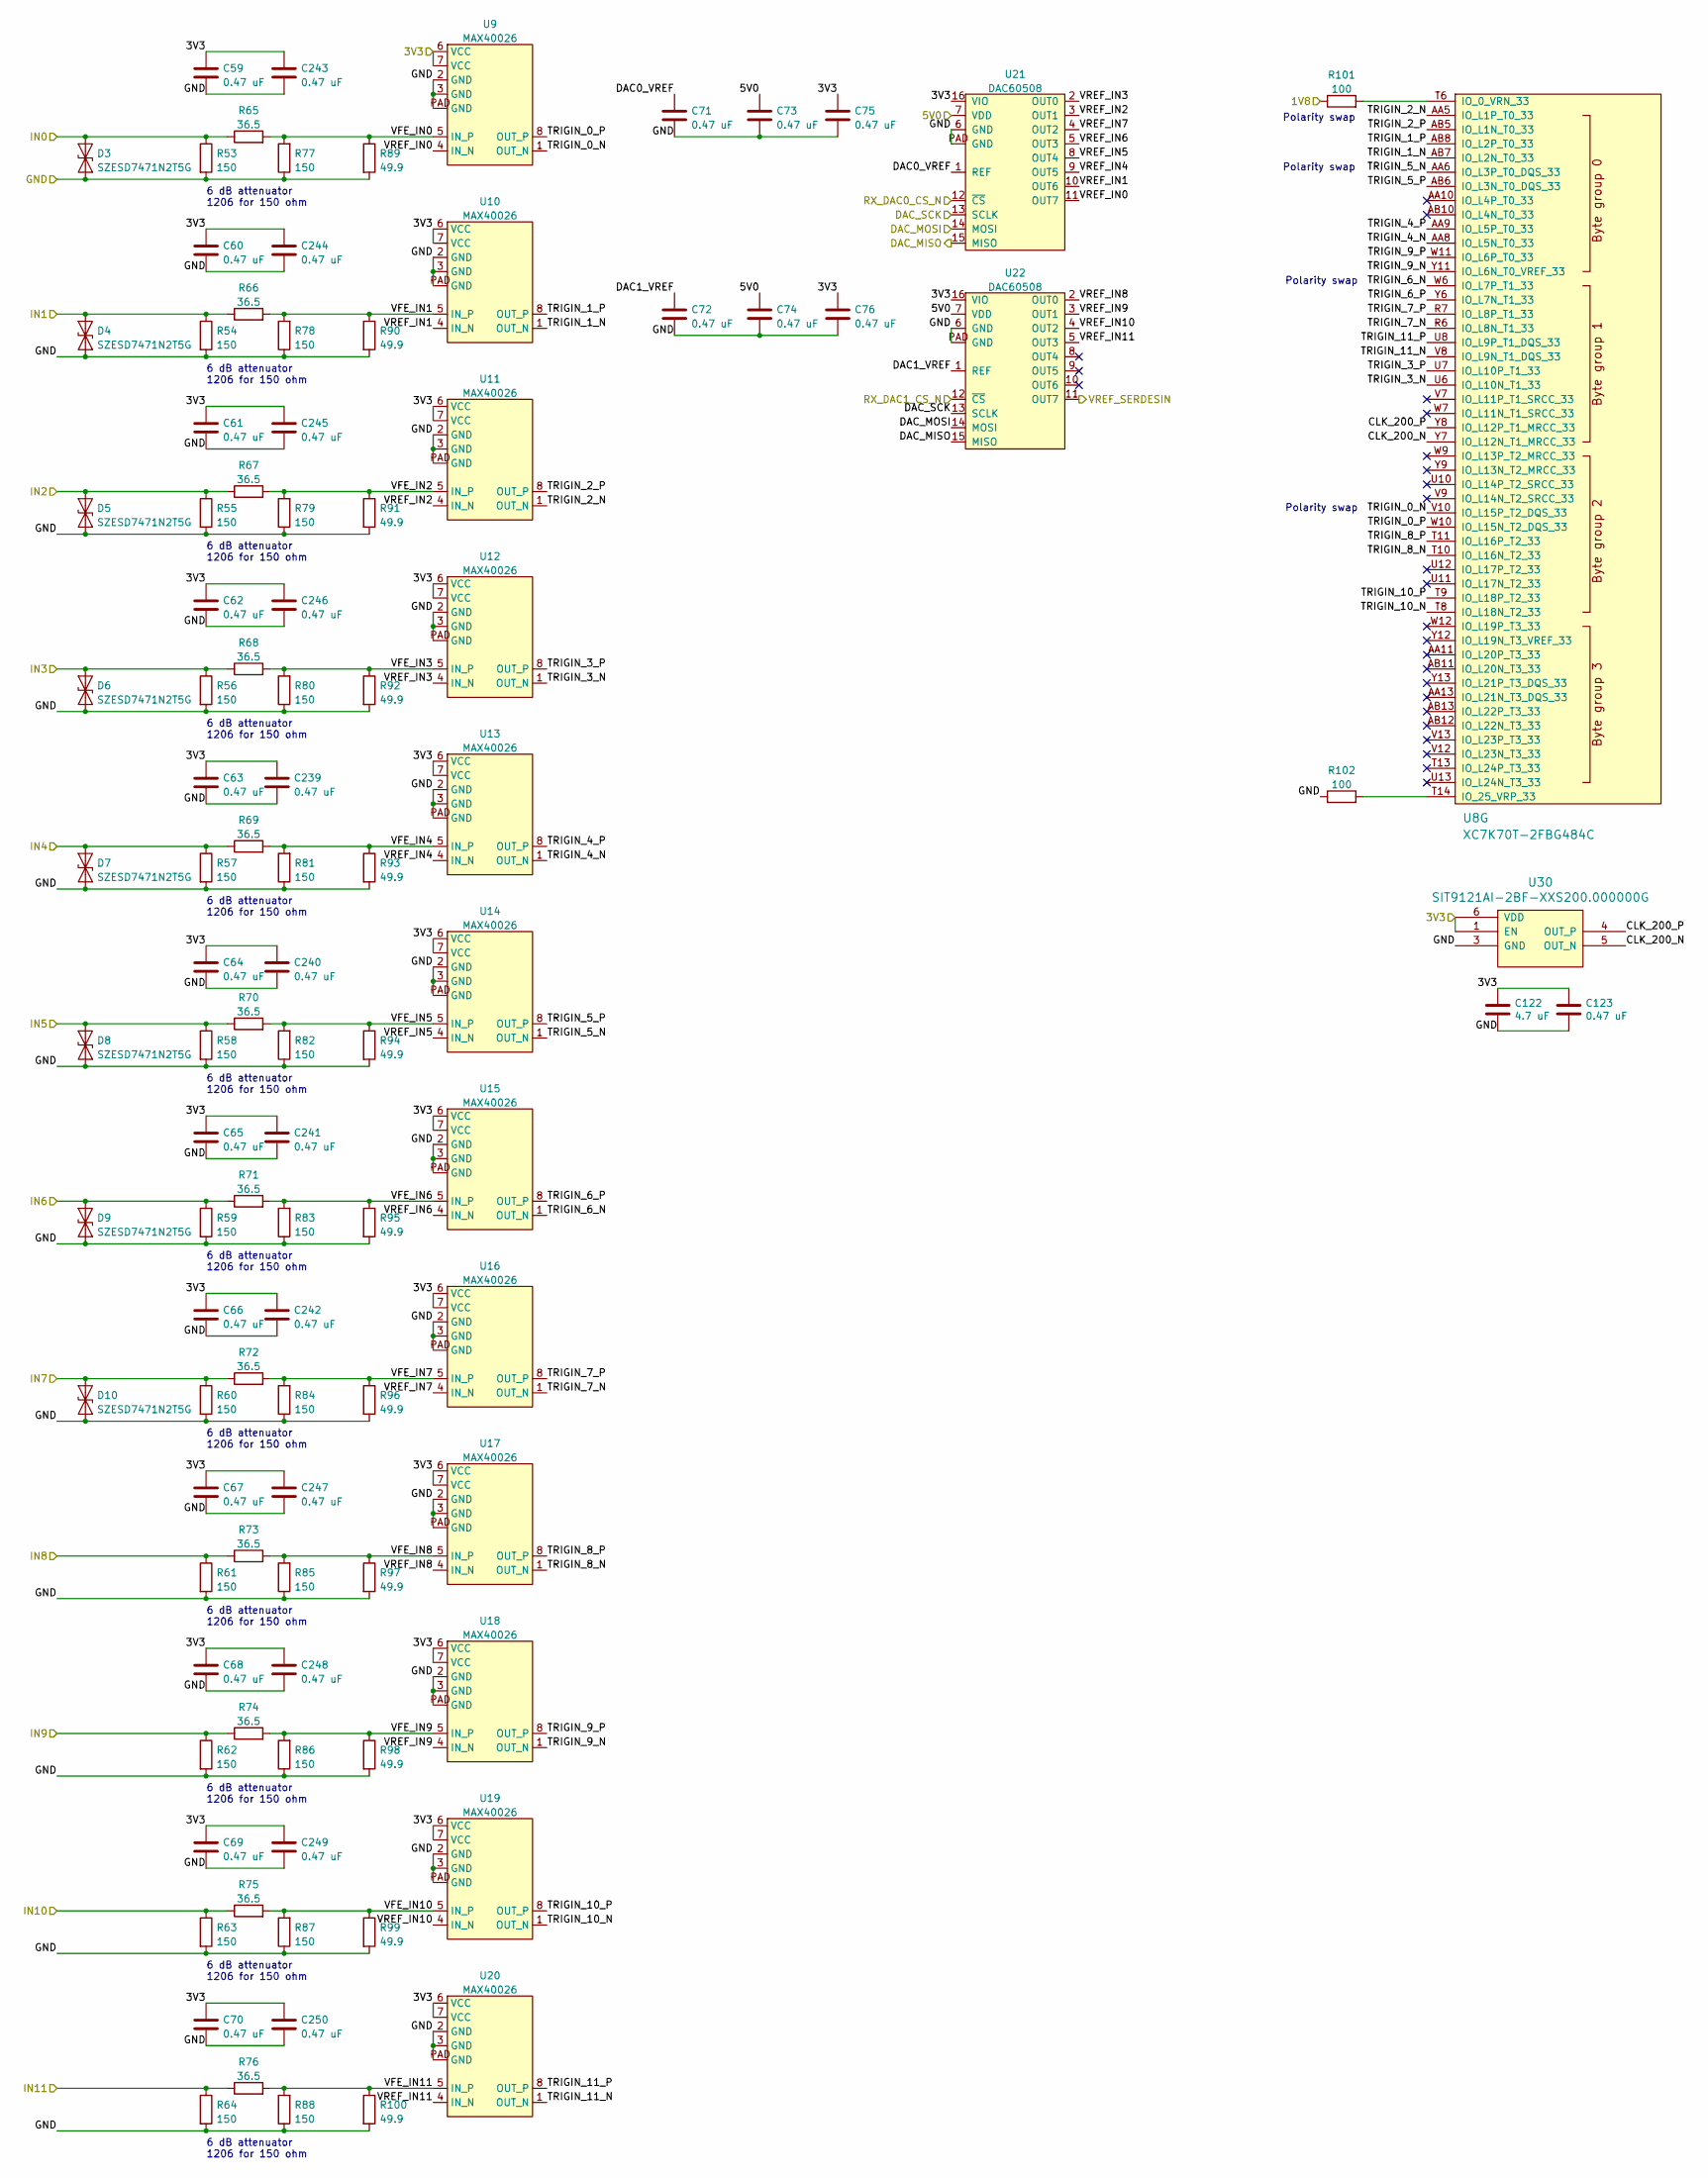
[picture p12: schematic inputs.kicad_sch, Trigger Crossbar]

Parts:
C59, C60, C61, C62, C63, C64, C65, C66, C67, C68, C69, C70, C71, C72, C73, C74, C75, C76, C123, C239, C240, C241, C242, C243, C244, C245, C246, C247, C248, C249, C250: 0.47 uF; EIA_0402_CAP_NOSILK
C122: 4.7 uF; EIA_0603_CAP_NOSILK
D3, D4, D5, D6, D7, D8, D9, D10: SZESD7471N2T5G; SOD882
R53, R54, R55, R56, R57, R58, R59, R60, R61, R62, R63, R64, R77, R78, R79, R80, R81, R82, R83, R84, R85, R86, R87, R88: 150; EIA_1206_CAP_NOSILK
R65, R66, R67, R68, R69, R70, R71, R72, R73, R74, R75, R76: 36.5; EIA_0402_RES_NOSILK
R89, R90, R91, R92, R93, R94, R95, R96, R97, R98, R99, R100: 49.9; EIA_0402_RES_NOSILK
R101, R102: 100; EIA_0402_RES_NOSILK
U8: XC7K70T-2FBG484C; BGA_484_22x22_FULLARRAY_1MM
U9, U10, U11, U12, U13, U14, U15, U16, U17, U18, U19, U20: MAX40026; DFN_8_0.5MM_2x2MM
U21, U22: DAC60508; QFN_16_0.5MM_3x3MM
U30: SIT9121AI-2BF-XXS200.000000G; OSCILLATOR_LVDS_3.2x2.5

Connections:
/3V3: C59.1, C60.1, C61.1, C62.1, C63.1, C64.1, C65.1, C66.1, C67.1, C68.1, C69.1, C70.1, C75.1, C76.1, C122.1, C123.1, C239.1, C240.1, C241.1, C242.1, C243.1, C244.1, C245.1, C246.1, C247.1, C248.1, C249.1, C250.1, U9.6 (VCC), U9.7 (VCC), U10.6 (VCC), U10.7 (VCC), U11.6 (VCC), U11.7 (VCC), U12.6 (VCC), U12.7 (VCC), U13.6 (VCC), U13.7 (VCC), U14.6 (VCC), U14.7 (VCC), U15.6 (VCC), U15.7 (VCC), U16.6 (VCC), U16.7 (VCC), U17.6 (VCC), U17.7 (VCC), U18.6 (VCC), U18.7 (VCC), U19.6 (VCC), U19.7 (VCC), U20.6 (VCC), U20.7 (VCC), U21.16 (VIO), U22.16 (VIO), U30.1 (EN), U30.6 (VDD); also elsewhere on the board
/5V0: C73.1, C74.1, U21.7 (VDD), U22.7 (VDD); also elsewhere on the board
/Connectors/IN0: D3.2 (A2), R53.1, R65.1; also elsewhere on the board
/Connectors/IN1: D4.2 (A2), R54.1, R66.1; also elsewhere on the board
/Connectors/IN2: D5.2 (A2), R55.1, R67.1; also elsewhere on the board
/Connectors/IN3: D6.2 (A2), R56.1, R68.1; also elsewhere on the board
/Connectors/IN4: D7.2 (A2), R57.1, R69.1; also elsewhere on the board
/Connectors/IN5: D8.2 (A2), R58.1, R70.1; also elsewhere on the board
/Connectors/IN6: D9.2 (A2), R59.1, R71.1; also elsewhere on the board
/Connectors/IN7: D10.2 (A2), R60.1, R72.1; also elsewhere on the board
/Connectors/IN8: R61.1, R73.1; also elsewhere on the board
/Connectors/IN9: R62.1, R74.1; also elsewhere on the board
/Connectors/IN10: R63.1, R75.1; also elsewhere on the board
/Connectors/IN11: R64.1, R76.1; also elsewhere on the board
/DAC_MISO: U21.15 (MISO), U22.15 (MISO); also elsewhere on the board
/DAC_MOSI: U21.14 (MOSI), U22.14 (MOSI); also elsewhere on the board
/DAC_SCK: U21.13 (SCLK), U22.13 (SCLK); also elsewhere on the board
/GND: C59.2, C60.2, C61.2, C62.2, C63.2, C64.2, C65.2, C66.2, C67.2, C68.2, C69.2, C70.2, C71.2, C72.2, C73.2, C74.2, C75.2, C76.2, C122.2, C123.2, C239.2, C240.2, C241.2, C242.2, C243.2, C244.2, C245.2, C246.2, C247.2, C248.2, C249.2, C250.2, D3.1 (A1), D4.1 (A1), D5.1 (A1), D6.1 (A1), D7.1 (A1), D8.1 (A1), D9.1 (A1), D10.1 (A1), R53.2, R54.2, R55.2, R56.2, R57.2, R58.2, R59.2, R60.2, R61.2, R62.2, R63.2, R64.2, R77.1, R78.1, R79.1, R80.1, R81.1, R82.1, R83.1, R84.1, R85.1, R86.1, R87.1, R88.1, R89.2, R90.2, R91.2, R92.2, R93.2, R94.2, R95.2, R96.2, R97.2, R98.2, R99.2, R100.2, R102.1, U9.2 (GND), U9.3 (GND), U9.PAD (GND), U10.2 (GND), U10.3 (GND), U10.PAD (GND), U11.2 (GND), U11.3 (GND), U11.PAD (GND), U12.2 (GND), U12.3 (GND), U12.PAD (GND), U13.2 (GND), U13.3 (GND), U13.PAD (GND), U14.2 (GND), U14.3 (GND), U14.PAD (GND), U15.2 (GND), U15.3 (GND), U15.PAD (GND), U16.2 (GND), U16.3 (GND), U16.PAD (GND), U17.2 (GND), U17.3 (GND), U17.PAD (GND), U18.2 (GND), U18.3 (GND), U18.PAD (GND), U19.2 (GND), U19.3 (GND), U19.PAD (GND), U20.2 (GND), U20.3 (GND), U20.PAD (GND), U21.6 (GND), U21.PAD (GND), U22.6 (GND), U22.PAD (GND), U30.3 (GND); also elsewhere on the board
/Inputs/CLK_200_N: U8.Y7 (IO_L12N_T1_MRCC_33), U30.5 (OUT_N)
/Inputs/CLK_200_P: U8.Y8 (IO_L12P_T1_MRCC_33), U30.4 (OUT_P)
/Inputs/DAC0_VREF: C71.1, U21.1 (REF)
/Inputs/DAC1_VREF: C72.1, U22.1 (REF)
/Inputs/TRIGIN_0_N: U8.V10 (IO_L15P_T2_DQS_33), U9.1 (OUT_N)
/Inputs/TRIGIN_0_P: U8.W10 (IO_L15N_T2_DQS_33), U9.8 (OUT_P)
/Inputs/TRIGIN_1_N: U8.AB7 (IO_L2N_T0_33), U10.1 (OUT_N)
/Inputs/TRIGIN_1_P: U8.AB8 (IO_L2P_T0_33), U10.8 (OUT_P)
/Inputs/TRIGIN_2_N: U8.AA5 (IO_L1P_T0_33), U11.1 (OUT_N)
/Inputs/TRIGIN_2_P: U8.AB5 (IO_L1N_T0_33), U11.8 (OUT_P)
/Inputs/TRIGIN_3_N: U8.U6 (IO_L10N_T1_33), U12.1 (OUT_N)
/Inputs/TRIGIN_3_P: U8.U7 (IO_L10P_T1_33), U12.8 (OUT_P)
/Inputs/TRIGIN_4_N: U8.AA8 (IO_L5N_T0_33), U13.1 (OUT_N)
/Inputs/TRIGIN_4_P: U8.AA9 (IO_L5P_T0_33), U13.8 (OUT_P)
/Inputs/TRIGIN_5_N: U8.AA6 (IO_L3P_T0_DQS_33), U14.1 (OUT_N)
/Inputs/TRIGIN_5_P: U8.AB6 (IO_L3N_T0_DQS_33), U14.8 (OUT_P)
/Inputs/TRIGIN_6_N: U8.W6 (IO_L7P_T1_33), U15.1 (OUT_N)
/Inputs/TRIGIN_6_P: U8.Y6 (IO_L7N_T1_33), U15.8 (OUT_P)
/Inputs/TRIGIN_7_N: U8.R6 (IO_L8N_T1_33), U16.1 (OUT_N)
/Inputs/TRIGIN_7_P: U8.R7 (IO_L8P_T1_33), U16.8 (OUT_P)
/Inputs/TRIGIN_8_N: U8.T10 (IO_L16N_T2_33), U17.1 (OUT_N)
/Inputs/TRIGIN_8_P: U8.T11 (IO_L16P_T2_33), U17.8 (OUT_P)
/Inputs/TRIGIN_9_N: U8.Y11 (IO_L6N_T0_VREF_33), U18.1 (OUT_N)
/Inputs/TRIGIN_9_P: U8.W11 (IO_L6P_T0_33), U18.8 (OUT_P)
/Inputs/TRIGIN_10_N: U8.T8 (IO_L18N_T2_33), U19.1 (OUT_N)
/Inputs/TRIGIN_10_P: U8.T9 (IO_L18P_T2_33), U19.8 (OUT_P)
/Inputs/TRIGIN_11_N: U8.V8 (IO_L9N_T1_DQS_33), U20.1 (OUT_N)
/Inputs/TRIGIN_11_P: U8.U8 (IO_L9P_T1_DQS_33), U20.8 (OUT_P)
/Inputs/VFE_IN0: R65.2, R77.2, R89.1, U9.5 (IN_P)
/Inputs/VFE_IN1: R66.2, R78.2, R90.1, U10.5 (IN_P)
/Inputs/VFE_IN2: R67.2, R79.2, R91.1, U11.5 (IN_P)
/Inputs/VFE_IN3: R68.2, R80.2, R92.1, U12.5 (IN_P)
/Inputs/VFE_IN4: R69.2, R81.2, R93.1, U13.5 (IN_P)
/Inputs/VFE_IN5: R70.2, R82.2, R94.1, U14.5 (IN_P)
/Inputs/VFE_IN6: R71.2, R83.2, R95.1, U15.5 (IN_P)
/Inputs/VFE_IN7: R72.2, R84.2, R96.1, U16.5 (IN_P)
/Inputs/VFE_IN8: R73.2, R85.2, R97.1, U17.5 (IN_P)
/Inputs/VFE_IN9: R74.2, R86.2, R98.1, U18.5 (IN_P)
/Inputs/VFE_IN10: R75.2, R87.2, R99.1, U19.5 (IN_P)
/Inputs/VFE_IN11: R76.2, R88.2, R100.1, U20.5 (IN_P)
/Inputs/VREF_IN0: U9.4 (IN_N), U21.11 (OUT7)
/Inputs/VREF_IN1: U10.4 (IN_N), U21.10 (OUT6)
/Inputs/VREF_IN2: U11.4 (IN_N), U21.3 (OUT1)
/Inputs/VREF_IN3: U12.4 (IN_N), U21.2 (OUT0)
/Inputs/VREF_IN4: U13.4 (IN_N), U21.9 (OUT5)
/Inputs/VREF_IN5: U14.4 (IN_N), U21.8 (OUT4)
/Inputs/VREF_IN6: U15.4 (IN_N), U21.5 (OUT3)
/Inputs/VREF_IN7: U16.4 (IN_N), U21.4 (OUT2)
/Inputs/VREF_IN8: U17.4 (IN_N), U22.2 (OUT0)
/Inputs/VREF_IN9: U18.4 (IN_N), U22.3 (OUT1)
/Inputs/VREF_IN10: U19.4 (IN_N), U22.4 (OUT2)
/Inputs/VREF_IN11: U20.4 (IN_N), U22.5 (OUT3)
/Management/RX_DAC0_CS_N: U21.12 (~CS); also elsewhere on the board
/Management/RX_DAC1_CS_N: U22.12 (~CS); also elsewhere on the board
/VREF_SERDESIN: U22.11 (OUT7); also elsewhere on the board
unnamed: R101.2, U8.T6 (IO_0_VRN_33)
unnamed: R102.2, U8.T14 (IO_25_VRP_33)

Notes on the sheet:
6 dB attenuator 1206 for 150 ohm
Polarity swap

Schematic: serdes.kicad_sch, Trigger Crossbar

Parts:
C53, C54, C57, C58, C116, C117, C118, C119, C120, C121: 0.1 uF; EIA_0402_CAP_NOSILK
C55, C56: 22 uF; EIA_0805_CAP_NOSILK
C114, C115: 0.47 uF; EIA_0402_CAP_NOSILK
C221, C222, C223, C230, C231: 4.7 uF; EIA_0603_CAP_NOSILK
C224, C225, C226, C232, C233: 330 pF; EIA_0402_CAP_NOSILK
C227, C228, C229, C234, C235: 100 pF; EIA_0402_CAP_NOSILK
D20, D21, D22, D23, D24, D25, D26, D27, D28, D29, D30: SZESD7471N2T5G; SOD882
J6: CONN_SFP_HOST; CONN_SFP+_AMPHENOL_UE76_A10_2000T
J7: SFP_CAGE; CONN_SFP_CAGE_TE_2007194-1
J16, J17, J18, J19, J20, J21, J22, J23, J24, J25, J26: SMPM; CONN_SMPM_AMPHENOL_C925-197J-51PT
L1, L2: 4.7 uH; EIA_0805_INDUCTOR_NOSILK
R47: 100; EIA_0402_RES_NOSILK
R48: 0.1; EIA_0402_RES_NOSILK
R49, R50: 0.5; EIA_0402_RES_NOSILK
R51, R52: 4.7K; EIA_0402_RES_NOSILK
R121, R122, R123: DNP; EIA_0402_RES_NOSILK
R161, R162: 1K; EIA_0402_RES_NOSILK
U8: XC7K70T-2FBG484C; BGA_484_22x22_FULLARRAY_1MM
U27: SIT9121AI-2BF-XXS200.000000G; OSCILLATOR_LVDS_3.2x2.5
U28: SIT9121AI-2BF-XXS156.250000G; OSCILLATOR_LVDS_3.2x2.5
U29: HMC675LP3E; QFN_16_0.5MM_3x3MM

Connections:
/1V2: C222.1, C225.1, C228.1, C231.1, C233.1, C235.1, U29.9 (VCCO), U29.12 (VCCO); also elsewhere on the board
/3V0_N: C223.1, C226.1, C229.1, U29.13 (VEE), U29.PAD (VEE); also elsewhere on the board
/3V3: C114.1, C115.1, C221.1, C224.1, C227.1, C230.1, C232.1, C234.1, R48.2, R51.2, R52.2, R121.1, R161.1, R162.1, U27.1 (EN), U27.6 (VDD), U28.1 (EN), U28.6 (VDD), U29.5 (VCCI), U29.16 (VCCI); also elsewhere on the board
/GND: C53.2, C54.2, C57.2, C58.2, C114.2, C115.2, C221.2, C222.2, C223.2, C224.2, C225.2, C226.2, C227.2, C228.2, C229.2, C230.2, C231.2, C232.2, C233.2, C234.2, C235.2, D20.1 (A1), D21.1 (A1), D22.1 (A1), D23.1 (A1), D24.1 (A1), D25.1 (A1), D26.1 (A1), D27.1 (A1), D28.1 (A1), D29.1 (A1), D30.1 (A1), J6.1 (GND_TX), J6.10 (GND_RX), J6.11 (GND_RX), J6.14 (GND_RX), J6.17 (GND_TX), J6.20 (GND_TX), J7.1, J16.2 (Ext), J17.2 (Ext), J18.2 (Ext), J19.2 (Ext), J20.2 (Ext), J21.2 (Ext), J22.2 (Ext), J23.2 (Ext), J24.2 (Ext), J25.2 (Ext), J26.2 (Ext), R49.1, R50.1, R122.1, R123.2, U27.3 (GND), U28.3 (GND), U29.1 (VTP), U29.8 (NC/GND), U29.15 (RTN); also elsewhere on the board
/Management/SFP_MOD_ABS: J6.6 (MOD_ABS); also elsewhere on the board
/Management/SFP_RX_LOS: J6.8 (RX_LOS); also elsewhere on the board
/Management/SFP_TX_DISABLE: J6.3 (TX_DISABLE); also elsewhere on the board
/Management/SFP_TX_FAULT: J6.2 (TX_FAULT); also elsewhere on the board
/Transceivers/BERT_RX0_N: D27.2 (A2), J23.1 (In), U8.B5 (GTX_RX_3_N)
/Transceivers/BERT_RX0_P: D26.2 (A2), J22.1 (In), U8.B6 (GTX_RX_3_P)
/Transceivers/BERT_RX1_N: D25.2 (A2), J21.1 (In), U8.C3 (GTX_RX_2_N)
/Transceivers/BERT_RX1_P: D24.2 (A2), J20.1 (In), U8.C4 (GTX_RX_2_P)
/Transceivers/BERT_TX0_N: D23.2 (A2), J19.1 (In), U8.A3 (GTX_TX_3_N)
/Transceivers/BERT_TX0_P: D22.2 (A2), J18.1 (In), U8.A4 (GTX_TX_3_P)
/Transceivers/BERT_TX1_N: D21.2 (A2), J17.1 (In), U8.B1 (GTX_TX_2_N)
/Transceivers/BERT_TX1_P: D20.2 (A2), J16.1 (In), U8.B2 (GTX_TX_2_P)
/Transceivers/CDRTRIG_IN: D28.2 (A2), J24.1 (In), U29.2 (IN_P)
/Transceivers/CDRTRIG_RX_AC_N: C121.1, U29.10 (Q_N)
/Transceivers/CDRTRIG_RX_AC_P: C120.1, U29.11 (Q_P)
/Transceivers/CDRTRIG_RX_N: C121.2, U8.E3 (GTX_RX_1_N)
/Transceivers/CDRTRIG_RX_P: C120.2, U8.E4 (GTX_RX_1_P)
/Transceivers/FASTSYNC_TX_N: D30.2 (A2), J26.1 (In), U8.D1 (GTX_TX_1_N)
/Transceivers/FASTSYNC_TX_P: D29.2 (A2), J25.1 (In), U8.D2 (GTX_TX_1_P)
/Transceivers/GTC1_N: C117.1, U27.5 (OUT_N)
/Transceivers/GTC1_P: C116.1, U27.4 (OUT_P)
/Transceivers/GTC2_N: C119.1, U28.5 (OUT_N)
/Transceivers/GTC2_P: C118.1, U28.4 (OUT_P)
/Transceivers/GTX_REFCLK_156M25_N: C119.2, U8.D5 (GTX_REFCLK_0_N)
/Transceivers/GTX_REFCLK_156M25_P: C118.2, U8.D6 (GTX_REFCLK_0_P)
/Transceivers/GTX_REFCLK_SPARE_N: C117.2, U8.F5 (GTX_REFCLK_1_N)
/Transceivers/GTX_REFCLK_SPARE_P: C116.2, U8.F6 (GTX_REFCLK_1_P)
/Transceivers/SFP_3V3: C53.1, C54.1, L1.2, L2.2, R48.1
/Transceivers/SFP_I2C_SCL: J6.5 (SCL), R52.1; also elsewhere on the board
/Transceivers/SFP_I2C_SDA: J6.4 (SDA), R51.1; also elsewhere on the board
/Transceivers/SFP_RS0: J6.7 (RS0), R161.2
/Transceivers/SFP_RS1: J6.9 (RS1), R162.2
/Transceivers/SFP_RX_N: J6.12 (RX_N), U8.G3 (GTX_RX_0_N)
/Transceivers/SFP_RX_P: J6.13 (RX_P), U8.G4 (GTX_RX_0_P)
/Transceivers/SFP_TX_N: J6.19 (TX_N), U8.F2 (GTX_TX_0_P)
/Transceivers/SFP_TX_P: J6.18 (TX_P), U8.F1 (GTX_TX_0_N)
/Transceivers/SFP_VDD_RX: C55.1, C57.1, J6.15 (VDD_RX), L1.1
/Transceivers/SFP_VDD_TX: C56.1, C58.1, J6.16 (VDD_TX), L2.1
/VREF_SERDESIN: U29.3 (IN_N); also elsewhere on the board
unnamed: C55.2, R49.2
unnamed: C56.2, R50.2
unnamed: R47.1, U8.H2 (GTX_RREF)
unnamed: R47.2, U8.H1 (GTX_VTTRCAL)
unnamed: R121.2, U29.6 (LE_N)
unnamed: R122.2, U29.7 (LE_P)
unnamed: R123.1, U29.4 (VTN)

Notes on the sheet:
Can use 156.25 for both Provide a second oscillator footprint just in case
Pair swap for routing
SFP+ power filtering
Single ended CDR trigger input

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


Board: 10 copper layers, 165.0 x 121.0 mm, 629 parts (182 on the bottom side), 396 nets.

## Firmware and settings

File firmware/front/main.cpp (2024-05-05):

/***********************************************************************************************************************
*                                                                                                                      *
* trigger-crossbar                                                                                                     *
*                                                                                                                      *
* Copyright (c) 2023-2024 Andrew D. Zonenberg and contributors                                                         *
* All rights reserved.                                                                                                 *
*                                                                                                                      *
* Redistribution and use in source and binary forms, with or without modification, are permitted provided that the     *
* following conditions are met:                                                                                        *
*                                                                                                                      *
*    * Redistributions of source code must retain the above copyright notice, this list of conditions, and the         *
*      following disclaimer.                                                                                           *
*                                                                                                                      *
*    * Redistributions in binary form must reproduce the above copyright notice, this list of conditions and the       *
*      following disclaimer in the documentation and/or other materials provided with the distribution.                *
*                                                                                                                      *
*    * Neither the name of the author nor the names of any contributors may be used to endorse or promote products     *
*      derived from this software without specific prior written permission.                                           *
*                                                                                                                      *
* THIS SOFTWARE IS PROVIDED BY THE AUTHORS "AS IS" AND ANY EXPRESS OR IMPLIED WARRANTIES, INCLUDING, BUT NOT LIMITED   *
* TO, THE IMPLIED WARRANTIES OF MERCHANTABILITY AND FITNESS FOR A PARTICULAR PURPOSE ARE DISCLAIMED. IN NO EVENT SHALL *
* THE AUTHORS BE HELD LIABLE FOR ANY DIRECT, INDIRECT, INCIDENTAL, SPECIAL, EXEMPLARY, OR CONSEQUENTIAL DAMAGES        *
* (INCLUDING, BUT NOT LIMITED TO, PROCUREMENT OF SUBSTITUTE GOODS OR SERVICES; LOSS OF USE, DATA, OR PROFITS; OR       *
* BUSINESS INTERRUPTION) HOWEVER CAUSED AND ON ANY THEORY OF LIABILITY, WHETHER IN CONTRACT, STRICT LIABILITY, OR TORT *
* (INCLUDING NEGLIGENCE OR OTHERWISE) ARISING IN ANY WAY OUT OF THE USE OF THIS SOFTWARE, EVEN IF ADVISED OF THE       *
* POSSIBILITY OF SUCH DAMAGE.                                                                                          *
*                                                                                                                      *
***********************************************************************************************************************/

#include "frontpanel.h"
#include "regids.h"

//UART console
//USART2 is on APB1 (40 MHz), so we need a divisor of 347.22, round to 347
UART<16, 256> g_uart(&USART2, 347);

Logger g_log;

//APB1 is 40 MHz
//Divide down to get 10 kHz ticks
Timer g_logTimer(&TIM15, Timer::FEATURE_GENERAL_PURPOSE_16BIT, 4000);

void RefreshDisplay(bool full);

const uint8_t g_tempI2cAddress = 0x90;

//I2C2 runs off our APB1 clock (40 MHz)
//Prescale by 4 to get 10 MHz
//Divide by 100 after that to get 100 kHz
I2C g_i2c(&I2C2, 4, 100);

TCA6424A* g_expander = nullptr;

//Divide 40 MHz base clock by 128 to get 312.5 kHz SPI
//We can run up to 10 MHz for writes but readback Fmax is ~2 MHz
DisplaySPIType g_displaySPI(&SPI2, false, 128);

Display* g_display = nullptr;

GPIOPin* g_inmodeLED[4] = {nullptr};
GPIOPin* g_outmodeLED[4] = {nullptr};

SPI<1024, 64> g_fpgaSPI(&SPI1, true, 2, false);
GPIOPin* g_fpgaSPICS = nullptr;

//Display state
int g_linkSpeed = 0;
uint8_t g_ipv4Addr[4] = {0};
uint16_t g_ipv6Addr[8] = {0};
uint8_t g_serial[8] = {0};
char g_mcuFirmware[20] = {0};
char g_ibcFirmware[20] = {0};
char g_superFirmware[20] = {0};
char g_fpgaFirmware[20] = {0};
uint16_t g_fpgaTemp = 0;
uint16_t g_mcuTemp = 0;
uint16_t g_ibcTemp = 0;
uint16_t g_vin = 0;
uint16_t g_iin = 0;
uint16_t g_vout = 0;
uint16_t g_iout = 0;
uint16_t g_fanspeed = 0;
uint16_t g_ipv4SubnetSize = 0;
uint16_t g_ipv6SubnetSize = 0;
bool g_staticIP = true;
char g_dataTimestamp[20] = {0};

//Indicates the main MCU is alive
bool	g_mainMCUDown = true;

bool RxSPIString(uint8_t nbyte, char* buf, uint8_t size, uint8_t data);

///@brief The battery-backed RAM used to store state across power cycles
volatile BootloaderBBRAM* g_bbram = reinterpret_cast<volatile BootloaderBBRAM*>(&_RTC.BKP[0]);

//Default MISO to be using alt mode 0 (NJTRST) so we can use JTAG for debug
GPIOPin g_fpgaMiso(&GPIOB, 4, GPIOPin::MODE_PERIPHERAL, GPIOPin::SLEW_FAST, 0);

bool g_misoIsJtag = true;

int main()
{
	//Copy .data from flash to SRAM (for some reason the default newlib startup won't do this??)
	memcpy(&__data_start, &__data_romstart, &__data_end - &__data_start + 1);

	//Re-enable interrupts since the bootloader turned them off to jump to us
	EnableInterrupts();

	//Hardware setup
	InitPower();
	InitClocks();
	InitUART();
	InitLog();
	DetectHardware();
	InitGPIOs();
	InitI2C();
	InitSensors();
	InitExpander();
	InitSPI();
	InitDisplay();

	g_log("Ready\n");

	uint32_t nextDisplayRefresh = 30;
	uint32_t nextFullRefresh = 5;		//Wait 5 sec after power up to do the first full refresh,
										//so main FPGA and MCU have a chance to come up

	//Main event loop
	const int logTimerMax = 60000;
	uint32_t next1HzTick = 0;
	uint8_t nbyte = 0;
	uint8_t cmd = 0;
	uint32_t secSinceLastMcuUpdate = 0;
	const uint32_t displayRefreshInterval = 3600;						//1 hour
	const uint32_t fullRefreshInterval = displayRefreshInterval * 24;	//1 day
	while(1)
	{
		//Check for overflows on our log message timer
		if(g_log.UpdateOffset(logTimerMax) && (next1HzTick >= logTimerMax) )
			next1HzTick -= logTimerMax;

		//Run the display state machine
		g_display->OnTick();

		//1 Hz timer event for display refreshes
		if(g_logTimer.GetCount() >= next1HzTick)
		{
			//g_log("1 Hz tick nextFull = %d nextDisplay = %d refreshing=%d\n",
			//	nextFullRefresh, nextDisplayRefresh, g_display->IsRefreshInProgress());

			next1HzTick = g_logTimer.GetCount() + 10000;

			//Watchdog timer to detect main MCU acting up
			secSinceLastMcuUpdate ++;
			if(secSinceLastMcuUpdate > 5)
			{
				if(!g_mainMCUDown)
				{
					g_mainMCUDown = true;
					nextDisplayRefresh = 1;
				}
			}

			//Update display if needed
			if(!g_display->IsRefreshInProgress())
			{
				//Full refresh once a day
				if(nextFullRefresh == 0)
				{
					nextFullRefresh = fullRefreshInterval;
					nextDisplayRefresh = displayRefreshInterval;
					RefreshDisplay(true);
				}

				//Default to refreshing the display once an hour
				else if(nextDisplayRefresh == 0)
				{
					nextDisplayRefresh = displayRefreshInterval;
					RefreshDisplay(false);
				}

				//Bump timer counts
				nextDisplayRefresh --;
				nextFullRefresh --;
			}
		}

		//Read and process SPI events
		if(g_fpgaSPI.HasEvents())
		{
			auto event = g_fpgaSPI.GetEvent();

			//Reset byte count on CS# rising or falling edge
			if(event.type == SPIEvent::TYPE_CS)
				nbyte = 0;

			//Process data byte
			else
			{
				auto data = event.data;

				//If main MCU was down, it's now up again
				secSinceLastMcuUpdate = 0;
				if(g_mainMCUDown)
				{
					g_mainMCUDown = false;
					nextDisplayRefresh = 1;
				}

				//First byte is command
				if(nbyte == 0)
				{
					cmd = data;

					switch(cmd)
					{
						//Reboot in bootloader mode
						case FRONT_ENTER_DFU:
							g_bbram->m_state = STATE_DFU;
							Reset();
							break;

						//Commands that produce SPI output
						case FRONT_GET_STATUS:
							{
								if(g_misoIsJtag)
									SetMisoToSPIMode();

								const uint8_t tmp = FRONT_NORMAL;
								g_fpgaSPI.NonblockingWriteFifo(&tmp, sizeof(tmp));
							}
							break;

						//sending any other SPI command returns us to JTAG mode
						default:
							if(!g_misoIsJtag)
								SetMisoToJTAGMode();
							break;
					}
				}

				//Then comes data bytes
				else
				{
					switch(cmd)
					{
						//Readback commands do nothing here
						case FRONT_GET_STATUS:
							break;

						//Schedule a display refresh
						case FRONT_REFRESH_FAST:
							nextDisplayRefresh = 0;
							break;

						case FRONT_REFRESH_FULL:
							nextFullRefresh = 0;
							break;

						//Link speed
						case FRONT_ETH_LINK:

							//If speed changed, trigger a display refresh
							if(g_linkSpeed != data)
								nextDisplayRefresh = 0;

							g_linkSpeed = data;
							break;

						//IPv4 address
						case FRONT_IP4_ADDR:
							if(nbyte <= 4)
							{
								//If IP changed, trigger a display refresh
								if(g_ipv4Addr[nbyte-1] != data)
									nextDisplayRefresh = 0;

								g_ipv4Addr[nbyte-1] = data;
							}
							break;

						//DHCP enable flag
						case FRONT_IPV4_DHCP:
							if(nbyte == 0)
								g_staticIP = nbyte ? true : false;
							break;

						//IPv6 address
						case FRONT_IP6_ADDR:
							if(nbyte <= 16)
							{
								int nword = (nbyte-1)/2;
								int half = (nbyte-1) % 2;

								if(half)
									g_ipv6Addr[nword] |= data;
								else
									g_ipv6Addr[nword] = data << 8;
							}
							break;

						//Serial number
						case FRONT_SERIAL:
							if(nbyte <= 8)
								g_serial[nbyte-1] = data;
							break;

						//Main MCU firmware
						case FRONT_MCU_FW:
							if(RxSPIString(nbyte, g_mcuFirmware, sizeof(g_mcuFirmware), data))
								nextDisplayRefresh = 0;
							break;

						//IBC MCU firmware
						case FRONT_IBC_FW:
							if(RxSPIString(nbyte, g_ibcFirmware, sizeof(g_ibcFirmware), data))
								nextDisplayRefresh = 0;
							break;

						//Supervisor MCU firmware
						case FRONT_SUPER_FW:
							if(RxSPIString(nbyte, g_superFirmware, sizeof(g_superFirmware), data))
								nextDisplayRefresh = 0;
							break;

						//FPGA firmware
						case FRONT_FPGA_FW:
							if(RxSPIString(nbyte, g_fpgaFirmware, sizeof(g_fpgaFirmware), data))
								nextDisplayRefresh = 0;
							break;

						//FPGA die temperature
						case FRONT_FPGA_TEMP:
							if(nbyte == 1)
								g_fpgaTemp = data;
							else if(nbyte == 2)
								g_fpgaTemp |= data << 8;
							break;

						//MCU die temperature
						case FRONT_MCU_TEMP:
							if(nbyte == 1)
								g_mcuTemp = data;
							else if(nbyte == 2)
								g_mcuTemp |= data << 8;
							break;

						//IBC board temperature
						case FRONT_IBC_TEMP:
							if(nbyte == 1)
								g_ibcTemp = data;
							else if(nbyte == 2)
								g_ibcTemp |= data << 8;
							break;

						//IBC input
						case FRONT_IBC_VIN:
							if(nbyte == 1)
								g_vin = data;
							else if(nbyte == 2)
								g_vin |= data << 8;
							break;
						case FRONT_IBC_IIN:
							if(nbyte == 1)
								g_iin = data;
							else if(nbyte == 2)
								g_iin |= data << 8;
							break;

						//IBC output
						case FRONT_IBC_VOUT:
							if(nbyte == 1)
								g_vout = data;
							else if(nbyte == 2)
								g_vout |= data << 8;
							break;
						case FRONT_IBC_IOUT:
							if(nbyte == 1)
								g_iout = data;
							else if(nbyte == 2)
								g_iout |= data << 8;
							break;

						//Fan RPM indicator
						case FRONT_FAN_RPM:
							if(nbyte == 1)
								g_fanspeed = data;
							else if(nbyte == 2)
								g_fanspeed |= data << 8;
							break;

						//Subnet mask
						case FRONT_IP4_SUBNET:
							if(nbyte == 1)
							{
								//If prefix changed, trigger a display refresh
								if(g_ipv4SubnetSize != data)
									nextDisplayRefresh = 0;

								g_ipv4SubnetSize = data;
							}
							break;
						case FRONT_IP6_SUBNET:
							if(nbyte == 1)
								g_ipv6SubnetSize = data;
							else if(nbyte == 2)
								g_ipv6SubnetSize |= data << 8;
							break;

						//Timestamp of sensor values
						case FRONT_TIMESTAMP:
							RxSPIString(nbyte, g_dataTimestamp, sizeof(g_dataTimestamp), data);
							break;

						//Port direction indicator LEDs
						case FRONT_DIR_LEDS:
							*g_outmodeLED[0] = (data & 1) == 1;
							*g_outmodeLED[1] = (data & 2) == 2;
							*g_outmodeLED[2] = (data & 4) == 4;
							*g_outmodeLED[3] = (data & 8) == 8;

							*g_inmodeLED[0] = (data & 0x10) == 0x10;
							*g_inmodeLED[1] = (data & 0x20) == 0x20;
							*g_inmodeLED[2] = (data & 0x40) == 0x40;
							*g_inmodeLED[3] = (data & 0x80) == 0x80;
							break;

						//Port status LEDs
						case FRONT_PORT_LEDS:
							if(nbyte <= 3)
								g_expander->BatchUpdateValue(nbyte-1, data);
							if(nbyte == 3)
								g_expander->BatchCommitValue();
							break;

						default:
							g_log("Unrecognized command %02x\n", cmd);
							break;

					}
				}

				nbyte ++;
			}
		}
	}

	return 0;
}

/**
	@brief Puts the SPI MISO pin in SPI mode (disconnecting JTAG)
 */
void SetMisoToSPIMode()
{
	g_fpgaMiso.SetMode(GPIOPin::MODE_PERIPHERAL, 5);
	g_misoIsJtag = false;
}

/**
	@brief Puts the SPI MISO pin in JTAG mode (reconnecting JTAG)
 */
void SetMisoToJTAGMode()
{
	g_fpgaMiso.SetMode(GPIOPin::MODE_PERIPHERAL, 0);
	g_misoIsJtag = true;
}

/**
	@brief Receive a string, return true if value has changed
 */
bool RxSPIString(uint8_t nbyte, char* buf, uint8_t size, uint8_t data)
{
	bool changed = false;
	if(nbyte < size-1)
	{
		//If value changed, trigger a display refresh
		if(g_mcuFirmware[nbyte-1] != data)
			changed = true;

		buf[nbyte-1] = data;
	}
	return changed;
}

////////////////////////////////////////////////////////////////////////////////////////////////////////////////////////
// Display interfacing

/**
	@brief Draw stuff on the screen
 */
void RefreshDisplay(bool forceFull)
{
	char tmp[128];
	StringBuffer buf(tmp, sizeof(tmp));

	g_display->Clear();

	////////////////////////////////////////////////////////////////////////////////////////////////////////////////////
	// Main text block

	//Initial constants
	uint8_t xleft = 0;
	uint8_t ytop = 103;
	uint8_t textheight = 8;
	uint8_t textwidth = 6;
	uint8_t xright = 211;

	//Text box extents
	uint8_t textleft = xleft + 2;
	uint8_t textright = textleft + 24*textwidth;
	uint8_t lineright = textright + 2;

	//Line at top of text
	uint8_t texty = ytop;
	g_display->Line(xleft, ytop, lineright, ytop, true);
	texty -= 2;

	//Top row: link speed
	texty -= textheight;
	const char* linkSpeed = "";
	switch(g_linkSpeed)
	{
		case 0:
			linkSpeed = "10M";
			break;

		case 1:
			linkSpeed = "100M";
			break;

		case 2:
			linkSpeed = "1000M";
			break;

		case 3:
			linkSpeed = "10G";
			break;

		default:
			linkSpeed = "DOWN";
			break;
	}
	g_display->Text6x8(textleft, texty, "Link", true);
	uint8_t vleft = 6*textwidth + textleft;
	if(g_linkSpeed > 3)
	{
		g_display->FilledRect(vleft - 1, texty, vleft + 4*textwidth + 1, texty + textheight+1, true);
		g_display->Text6x8(vleft, texty, linkSpeed, false);
	}
	else
		g_display->Text6x8(vleft, texty, linkSpeed, true);

	//DHCP mode
	g_display->Text6x8(textright - 6*textwidth, texty, g_staticIP ? "Static" : "  DHCP", true);

	//IPv4 address and subnet mask
	texty -= textheight;
	buf.Clear();
	buf.Printf("IPv4  %d.%d.%d.%d/%d",
		g_ipv4Addr[0], g_ipv4Addr[1], g_ipv4Addr[2], g_ipv4Addr[3], g_ipv4SubnetSize);
	g_display->Text6x8(textleft, texty, tmp, true);

	//Next rows: IPv6 address
	texty -= textheight;
	buf.Clear();
	buf.Printf("IPv6  %x:%x:%x:%x:", g_ipv6Addr[0], g_ipv6Addr[1], g_ipv6Addr[2], g_ipv6Addr[3]);
	g_display->Text6x8(textleft, texty, tmp, true);

	texty -= textheight;
	buf.Clear();
	buf.Printf("      %x:%x:%x:%x/%d", g_ipv6Addr[4], g_ipv6Addr[5], g_ipv6Addr[6], g_ipv6Addr[7], g_ipv6SubnetSize);
	g_display->Text6x8(textleft, texty, tmp, true);

	//Line between IP info and serial
	g_display->Line(xleft, texty, lineright, texty, true);
	texty -= 2;

	//Serial number
	texty -= textheight;
	buf.Clear();
	buf.Printf("S/N   %02x%02x%02x%02x%02x%02x%02x%02x",
		g_serial[0], g_serial[1], g_serial[2], g_serial[3],
		g_serial[4], g_serial[5], g_serial[6], g_serial[7]);
	g_display->Text6x8(textleft, texty, tmp, true);

	//Line between serial and version
	g_display->Line(xleft, texty, lineright, texty, true);
	texty -= 2;

	//Version info
	texty -= textheight;
	buf.Clear();
	buf.Printf("IBC   %s", g_ibcFirmware);
	g_display->Text6x8(textleft, texty, tmp, true);

	texty -= textheight;
	buf.Clear();
	buf.Printf("Super %s", g_superFirmware);
	g_display->Text6x8(textleft, texty, tmp, true);

	texty -= textheight;
	static const char* buildtime = __TIME__;
	buf.Clear();
	buf.Printf("Panel %s %c%c%c%c%c%c",
		__DATE__, buildtime[0], buildtime[1], buildtime[3], buildtime[4], buildtime[6], buildtime[7]);
	g_display->Text6x8(textleft, texty, tmp, true);

	texty -= textheight;
	buf.Clear();
	buf.Printf("MCU   %s", g_mcuFirmware);
	g_display->Text6x8(textleft, texty, tmp, true);

	texty -= textheight;
	buf.Clear();
	buf.Printf("FPGA  %s", g_fpgaFirmware);
	g_display->Text6x8(textleft, texty, tmp, true);

	//Line below version info
	texty --;
	g_display->Line(xleft, texty, lineright, texty, true);
	texty -= 2;

	//Data timestamp
	texty -= textheight;
	buf.Clear();
	buf.Printf("Updated         %s", g_dataTimestamp);
	g_display->Text6x8(textleft, texty, tmp, true);

	//Final bottom line
	texty --;
	g_display->Line(xleft, texty, lineright, texty, true);

	//Vertical line at left and right of text
	g_display->Line(xleft, ytop, xleft, texty, true);
	g_display->Line(lineright, ytop, lineright, texty, true);

	////////////////////////////////////////////////////////////////////////////////////////////////////////////////////
	// Right area: system health

	texty = ytop;

	//Horizontal line at top
	g_display->Line(lineright, texty, xright, texty, true);
	texty -= 2;

	//IBC input stats
	textleft = 151;
	texty -= textheight;
	buf.Clear();
	buf.Printf("IN %2d.%03dV", g_vin / 1000, g_vin % 1000);
	g_display->Text6x8(textleft, texty, tmp, true);

	texty -= textheight;
	buf.Clear();
	buf.Printf("   %2d.%03dA", g_iin / 1000, g_iin % 1000);
	g_display->Text6x8(textleft, texty, tmp, true);

	texty -= textheight;
	uint32_t pwr = ( (uint32_t)g_vin * (uint32_t)g_iin ) / 1000;	//gives power in mW
	buf.Clear();
	buf.Printf("   %2d.%03dW", pwr / 1000, pwr % 1000);
	g_display->Text6x8(textleft, texty, tmp, true);

	//horizontal line between input and output stats
	g_display->Line(lineright, texty, xright, texty, true);
	texty -= 2;

	//IBC output stats
	texty -= textheight;
	buf.Clear();
	buf.Printf("OP %2d.%03dV", g_vout / 1000, g_vout % 1000);
	g_display->Text6x8(textleft, texty, tmp, true);

	texty -= textheight;
	buf.Clear();
	buf.Printf("   %2d.%03dA", g_iout / 1000, g_iout % 1000);
	g_display->Text6x8(textleft, texty, tmp, true);

	texty -= textheight;
	pwr = ( (uint32_t)g_vout * (uint32_t)g_iout ) / 1000;
	buf.Clear();
	buf.Printf("   %2d.%03dW", pwr / 1000, pwr % 1000);
	g_display->Text6x8(textleft, texty, tmp, true);

	//Horizontal line before temps
	g_display->Line(lineright, texty, xright, texty, true);
	texty -= 2;

	//IBC temperature
	texty -= textheight;
	int degreal = g_ibcTemp >> 8;
	int degfrac = (g_ibcTemp & 0xff) * 10;
	buf.Clear();
	buf.Printf("IBC  %2d.%dC", degreal, degfrac >> 8);
	g_display->Text6x8(textleft, texty, tmp, true);

	texty -= textheight;
	degreal = g_mcuTemp >> 8;
	degfrac = (g_mcuTemp & 0xff) * 10;
	buf.Clear();
	buf.Printf("MCU  %2d.%dC", degreal, degfrac >> 8);
	g_display->Text6x8(textleft, texty, tmp, true);

	texty -= textheight;
	degreal = g_fpgaTemp >> 8;
	degfrac = (g_fpgaTemp & 0xff) * 10;
	buf.Clear();
	buf.Printf("FPGA %2d.%dC", degreal, degfrac >> 8);
	g_display->Text6x8(textleft, texty, tmp, true);

	texty -= textheight;
	auto fronttemp = ReadThermalSensor(g_tempI2cAddress);
	degreal = fronttemp >> 8;
	degfrac = (fronttemp & 0xff) * 10;
	buf.Clear();
	buf.Printf("PANL %2d.%dC", degreal, degfrac >> 8);
	g_display->Text6x8(textleft, texty, tmp, true);

	//Get the fan speed
	texty -= textheight;
	buf.Clear();
	buf.Printf("FAN  %5d", g_fanspeed);
	bool fanSpeedOK = true;
	if( (g_fanspeed < 7000) || (g_fanspeed > 15000) )
		fanSpeedOK = false;
	if(fanSpeedOK)
		g_display->Text6x8(textleft, texty, tmp, true);
	else
	{
		g_display->FilledRect(lineright, texty, xright, texty + textheight + 1, true);
		g_display->Text6x8(textleft, texty, tmp, false);
	}

	//horizontal line below text
	g_display->Line(lineright, texty, xright, texty, true);

	//Vertical line at left and right side
	g_display->Line(lineright, ytop, lineright, texty, true);
	g_display->Line(xright, ytop, xright, texty, true);

	////////////////////////////////////////////////////////////////////////////////////////////////////////////////////
	// Update the display if the main MCU goes down

	if(g_mainMCUDown)
	{
		static const char* err= "MCU or FPGA down";
		g_display->FilledRect(0, 0, strlen(err)*8 + 2, textheight+1, true);
		g_display->Text6x8(1, 0, err, false);
	}

	////////////////////////////////////////////////////////////////////////////////////////////////////////////////////
	// Done, push the update to the display

	g_display->StartRefresh(forceFull);
}

////////////////////////////////////////////////////////////////////////////////////////////////////////////////////////
// Sensor interfacing
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

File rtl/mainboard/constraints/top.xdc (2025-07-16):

########################################################################################################################
# Timestamp in usercode

set_property BITSTREAM.CONFIG.USR_ACCESS TIMESTAMP [current_design]

########################################################################################################################
# Pin assignments

set_property PACKAGE_PIN Y8 [get_ports clk_200mhz_p]
set_property IOSTANDARD LVCMOS18 [get_ports {trig_out[3]}]
set_property IOSTANDARD LVCMOS18 [get_ports {trig_out[2]}]
set_property IOSTANDARD LVCMOS18 [get_ports {trig_out[1]}]
set_property IOSTANDARD LVCMOS18 [get_ports {trig_out[0]}]
set_property PACKAGE_PIN AB3 [get_ports {trig_out[3]}]
set_property PACKAGE_PIN AA4 [get_ports {trig_out[2]}]
set_property PACKAGE_PIN AA3 [get_ports {trig_out[1]}]
set_property PACKAGE_PIN AB2 [get_ports {trig_out[0]}]
set_property IOSTANDARD LVCMOS33 [get_ports {led[3]}]
set_property IOSTANDARD LVCMOS33 [get_ports {led[2]}]
set_property IOSTANDARD LVCMOS33 [get_ports {led[1]}]
set_property IOSTANDARD LVCMOS33 [get_ports {led[0]}]
set_property PACKAGE_PIN A16 [get_ports {led[3]}]
set_property PACKAGE_PIN A15 [get_ports {led[2]}]
set_property PACKAGE_PIN B15 [get_ports {led[1]}]
set_property PACKAGE_PIN A14 [get_ports {led[0]}]

set_property DRIVE 8 [get_ports {trig_out[3]}]
set_property DRIVE 8 [get_ports {trig_out[2]}]
set_property DRIVE 8 [get_ports {trig_out[1]}]
set_property DRIVE 8 [get_ports {trig_out[0]}]

set_property IOSTANDARD LVCMOS33 [get_ports {trig_out[7]}]
set_property IOSTANDARD LVCMOS33 [get_ports {trig_out[6]}]
set_property IOSTANDARD LVCMOS33 [get_ports {trig_out[5]}]
set_property IOSTANDARD LVCMOS33 [get_ports {trig_out[4]}]
set_property SLEW FAST [get_ports {trig_out[0]}]
set_property SLEW FAST [get_ports {trig_out[1]}]
set_property SLEW FAST [get_ports {trig_out[2]}]
set_property SLEW FAST [get_ports {trig_out[3]}]
set_property PACKAGE_PIN AA18 [get_ports {trig_out[7]}]
set_property DRIVE 8 [get_ports {trig_out[7]}]
set_property DRIVE 8 [get_ports {trig_out[6]}]
set_property DRIVE 8 [get_ports {trig_out[5]}]
set_property DRIVE 8 [get_ports {trig_out[4]}]
set_property SLEW FAST [get_ports {trig_out[7]}]
set_property SLEW FAST [get_ports {trig_out[6]}]
set_property SLEW FAST [get_ports {trig_out[5]}]
set_property SLEW FAST [get_ports {trig_out[4]}]
set_property PACKAGE_PIN AB17 [get_ports {trig_out[6]}]
set_property PACKAGE_PIN AB18 [get_ports {trig_out[5]}]
set_property PACKAGE_PIN T15 [get_ports {trig_out[4]}]

set_property IOSTANDARD LVCMOS33 [get_ports {relay_a[3]}]
set_property IOSTANDARD LVCMOS33 [get_ports {relay_a[2]}]
set_property IOSTANDARD LVCMOS33 [get_ports {relay_a[1]}]
set_property IOSTANDARD LVCMOS33 [get_ports {relay_a[0]}]
set_property IOSTANDARD LVCMOS33 [get_ports {relay_b[3]}]
set_property IOSTANDARD LVCMOS33 [get_ports {relay_b[2]}]
set_property IOSTANDARD LVCMOS33 [get_ports {relay_b[1]}]
set_property IOSTANDARD LVCMOS33 [get_ports {relay_b[0]}]
set_property PACKAGE_PIN AB22 [get_ports {relay_a[3]}]
set_property PACKAGE_PIN AB16 [get_ports {relay_a[2]}]
set_property PACKAGE_PIN AB21 [get_ports {relay_a[1]}]
set_property PACKAGE_PIN AB15 [get_ports {relay_a[0]}]
set_property PACKAGE_PIN AA21 [get_ports {relay_b[3]}]
set_property PACKAGE_PIN AA16 [get_ports {relay_b[2]}]
set_property PACKAGE_PIN AA20 [get_ports {relay_b[1]}]
set_property PACKAGE_PIN AA15 [get_ports {relay_b[0]}]
set_property IOSTANDARD LVCMOS33 [get_ports {trig_out[11]}]
set_property IOSTANDARD LVCMOS33 [get_ports {trig_out[10]}]
set_property IOSTANDARD LVCMOS33 [get_ports {trig_out[9]}]
set_property IOSTANDARD LVCMOS33 [get_ports {trig_out[8]}]
set_property PACKAGE_PIN W22 [get_ports {trig_out[11]}]
set_property PACKAGE_PIN AB20 [get_ports {trig_out[10]}]
set_property PACKAGE_PIN Y22 [get_ports {trig_out[9]}]
set_property PACKAGE_PIN Y17 [get_ports {trig_out[8]}]

set_property IOSTANDARD LVCMOS33 [get_ports rgmii_rst_n]
set_property DRIVE 8 [get_ports rgmii_rst_n]
set_property PACKAGE_PIN F10 [get_ports rgmii_rst_n]

set_property PACKAGE_PIN G11 [get_ports rgmii_rxc]
set_property IOSTANDARD LVCMOS33 [get_ports rgmii_rxc]

set_property PACKAGE_PIN E4 [get_ports cdrtrig_n]
set_property PACKAGE_PIN D6 [get_ports gtx_refclk_156m25_p]
set_property PACKAGE_PIN F6 [get_ports gtx_refclk_200m_p]

set_property IOSTANDARD LVDS [get_ports clk_200mhz_p]
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

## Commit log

2023-10-16 Initial floorplan of IBC
    [ibc.kicad_pcb, ibc.kicad_sch]
2023-10-19 Finished v0.1 IBC ready for fab
    [ibc.kicad_pcb, ibc.kicad_sch]
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2023-11-29 Updated IBC board for v0.2 with antialiasing filter, plane fix, and 5V standby rail
    [ibc.kicad_pcb, ibc.kicad_sch]
2023-11-30 Respun again for v0.3, moving 48V shunt outside high dI/dT loop because I was derpy
    [ibc.kicad_pcb, ibc.kicad_sch]
2023-12-15 Initial work on main PCB schematic
    [fpgasupport.kicad_sch, inputs.kicad_sch, mainboard.kicad_pcb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]
2023-12-17 Continued initial work on main board
    [baset.kicad_sch, connectors.kicad_sch, fpgasupport.kicad_sch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]
2023-12-17 Finished initial iteration of schematic, needs a verification pass to check for missing features then schematic review
    [connectors.kicad_sch, fpgasupport.kicad_sch, inputs.kicad_sch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]
2023-12-17 Added missing decoupling caps to comparator
    [fpgasupport.kicad_sch, mainboard.kicad_sch, serdes.kicad_sch]
2023-12-17 Calculated power monitor voltage divider
    [baset.kicad_sch, connectors.kicad_sch, fpgasupport.kicad_sch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]
2023-12-17 Fixed typo, changed MCU Vbat to run on 3V3_SB
    [mainboard.kicad_sch, mgmt.kicad_sch, psu.kicad_sch]
2023-12-18 Began assigning footprints
    [baset.kicad_sch, connectors.kicad_sch, fpgasupport.kicad_sch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]
2023-12-18 Finished component footprint assignment, started some EM simulations. Ready for schematic review.
    [baset.kicad_sch, connectors.kicad_sch, fpgasupport.kicad_sch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]
2023-12-19 Finished initial schematic review of trigger crossbar mainboard
    [baset.kicad_sch, connectors.kicad_sch, fpgasupport.kicad_sch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]
2023-12-19 Initial floorplanning work, added SFP+ LEDs
    [fpgasupport.kicad_sch, mainboard.kicad_pcb, mainboard.kicad_sch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]
2023-12-20 Continued initial layout work
    [baset.kicad_sch, connectors.kicad_sch, fpgasupport.kicad_sch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]
2023-12-20 Initial MCU subsystem layout
    [baset.kicad_sch, mainboard.kicad_pcb, mainboard.kicad_sch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]
2023-12-21 Initial placement of rear I/O connectors
    [mainboard.kicad_pcb, mgmt.kicad_sch]
2023-12-21 Started layout of rear panel IO connectors and associated drivers/comparators
    [connectors.kicad_sch, inputs.kicad_sch, mainboard.kicad_pcb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]
2023-12-21 Grouped remaining components by subsystem, continued layout of IO area
    [mainboard.kicad_pcb]
2023-12-22 Initial FPGA routing
    [baset.kicad_sch, connectors.kicad_sch, fpgasupport.kicad_sch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]
2023-12-22 Hooked up most input pins
    [fpgasupport.kicad_sch, inputs.kicad_sch, mainboard.kicad_pcb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]
2023-12-22 Hooked up PMOD, initial placement of FPGA JTAG
    [inputs.kicad_sch, mainboard.kicad_pcb, mgmt.kicad_sch]
2023-12-23 Placed remainder of relays and drivers
    [mainboard.kicad_pcb, outputs.kicad_sch]
2023-12-23 Tweaks to debug connectors, hooked up TX DAC
    [connectors.kicad_sch, mainboard.kicad_pcb, outputs.kicad_sch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]
2023-12-23 Hooked up soft power/reset buttons
    [inputs.kicad_sch, mainboard.kicad_pcb, outputs.kicad_sch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]
2023-12-23 Initial routing of supervisor MCU
    [mainboard.kicad_pcb]
2023-12-23 Initial power etc routing for supervisor
    [mainboard.kicad_pcb]
2023-12-23 Initial layout of GTX_1V8 supply
    [mainboard.kicad_pcb]
2023-12-24 More work in supervisor region
    [mainboard.kicad_pcb, mgmt.kicad_sch, psu.kicad_sch]
2023-12-25 Continued layout, started plane fills. Everything routed except 1V8 regulator
    [baset.kicad_sch, connectors.kicad_sch, fpgasupport.kicad_sch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]
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2023-12-26 Finished first pass of routing cleanup, moved FPGA JTAG to edge of board
    [baset.kicad_sch, connectors.kicad_sch, fpgasupport.kicad_sch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]
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2023-12-27 Continued layout review, various routing and silkscreen cleanup. DRC clean.
    [mainboard.kicad_sch]
2023-12-30 Final gerber review completed, a few last minute bug fixes
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2024-02-26 Updated schematic with some notes on rework
    [baset.kicad_sch, connectors.kicad_sch, fpgasupport.kicad_sch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]
2024-02-26 Blink power LED if rails are all up, but FPGA is down
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2024-02-26 Supervisor can now read temp sensor on IBC over I2C, but not yet talk to IBC firmware
2024-02-27 Initial I2C comms between IBC and supervisor are working, although IBC seems to get unhappy if supervisor resets mid-transaction (need some timeout to recover). Power loss protection is working.
    [main.cpp]
2024-03-09 Initial front panel skeleton
    [frontpanel.kicad_pcb, frontpanel.kicad_sch]
2024-03-09 Continued work on front panel
    [frontpanel.kicad_sch]
2024-03-10 Updated front panel sch to use STM32L431 with more SRAM and SPI interfaces
    [frontpanel.kicad_pcb, frontpanel.kicad_sch]
2024-03-11 Finished initial front panel schematic and design review
    [frontpanel.kicad_pcb, frontpanel.kicad_sch]
2024-03-11 Continued front panel PCB layout
    [frontpanel.kicad_pcb, frontpanel.kicad_sch]
2024-03-11 Fully routed front panel ready for layout review
    [frontpanel.kicad_pcb, frontpanel.kicad_sch]
2024-03-12 Hopefully-final front panel PCB layout after layout review, pending final exports and mechanical fit check on enclosure
    [frontpanel.kicad_pcb, frontpanel.kicad_sch]
2024-03-12 Final front panel design ready for manufacture
    [frontpanel.kicad_pcb]
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2024-03-13 PCB library updates
    [baset.kicad_sch, fpgasupport.kicad_sch, inputs.kicad_sch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]
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2024-03-16 Removed Vivado IPs replaced with our own wrapper script, updated GTX wrapper to use it. Re-floorplanned 25519 block.
    [top.xdc]
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2024-03-16 QPLL / CPLL switching is now working and controllable over SCPI including readback
2024-03-24 Initial skeleton front panel firmware
    [dongle.cfg]
2024-03-24 Initial low-level driver for e-ink display. Only supports single-pixel updates and the refresh is blocking for now.
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2024-03-26 Power failure polling now uses same nonblocking sensor values
    [main.cpp]
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2024-03-28 FIxed incorrect fan RPM calculation. Added SPI registers to front panel for setting LEDs for bidirectional port state.
    [main.cpp, top.xdc]
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2024-03-31 Front panel display now refreshes every two hours, as well as after Ethernet link state changes. Base-T link speed on front panel is now correctly displayed.
    [main.cpp]
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2024-04-01 Improved handling of inbound 10GbE frames. Outbound 10G won't work without some more bitstream work.
    [main.cpp]
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2024-04-02 FPGA firmware version displayed no longer zero-prefixes day of month, to ensure consistency with MCU firmware version numbers
    [main.cpp]
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2024-04-09 DeviceCryptoEngine: avoid reading back results we don't care about
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2024-04-11 Fixed a bunch of bugs and bad design choices that led to excessive EPD wear on front panel display
    [Display.cpp, main.cpp]
2024-04-12 Front panel: Display fan failure state in reverse video for visibility. Trigger display refresh when IP address changes
    [main.cpp]
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2024-04-12 Added CLI commands for configuring the IP address and forcing a screen refresh. Fixes #1.
    [main.cpp]
2024-04-14 Fixed some pop logic in ManagementRegisterInterface, fixed frequency of Timer1
    [DeviceInit.cpp, top.xdc]
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2024-04-15 Various improvements to SPI bus reliability, ISR based message handling, etc. Fixes #10.
    [DeviceInit.cpp, main.cpp, top.xdc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]
2024-04-18 Added 32:33 and 2:1 (net 64:66) gearbox for 10GbE decoding. Doesn't yet do bit alignment.
    [top.xdc]
2024-04-19 Front panel: fixed bug causing potential timer hang
    [main.cpp]
2024-04-19 Upped CPU clock frequency to max (550 MHz) using external 25 MHz oscillator, vs ~512 using internal RC
    [DeviceInit.cpp]
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2024-04-26 Converted SPI class to take templated buffer size, increased buffer size on front panel to fix occasional data corruption from FIFO overruns. Moved SSH and network related modules from main firmware 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
    [DeviceInit.cpp, Display.cpp, Init.cpp]
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2024-04-28 Allow storing persistent nicknames of crossbar channels (not BERT for now). Thresholds and drive levels are now persisted as well. Fixes #14. Fixes #3.
    [main.cpp]
2024-05-01 Initial bootloader for front panel. Supports basic CRC integrity checks and then starts application but doesn't have any SPI reflash capability yet
    [DeviceInit.cpp, Init.cpp, main.cpp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]
2024-05-02 Front panel bootloader is now entered on explicit request from application or if a crash handler is called
    [main.cpp, vectors.cpp]
2024-05-02 PCB updates for kicad8
    [baset.kicad_sch, connectors.kicad_sch, fpgasupport.kicad_sch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]
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2024-05-09 Added "legacy read" and "legacy write" SPI instructions to avoid ambiguity as we start transitioning registers to APB. Moved some more headers to packages for better build/sim support
    [DeviceInit.cpp, top.xdc]
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2024-05-20 Saving current state, broken 1GbE
    [DeviceInit.cpp, main.cpp]
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2024-05-26 Initial skeleton of main CPU bootloader (doesn't implement reflashing, just integrity checking so far)
    [Init.cpp, hwinit.cpp, mainloop.cpp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]
2024-05-26 Added commands for application to reboot into DFU mode
    [hwinit.cpp, mainloop.cpp]
2024-05-30 Updated PCB schematic with note about R134 errata
    [mgmt.kicad_sch]
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2024-05-31 Began work on FPGA DFU. Can erase and blank check flash and begin parsing bitstream, but doesn't actually write bitstream to flash yet.
    [hwinit.cpp, top.xdc]
2024-05-31 Reset SPI flash before trying to talk to it
2024-08-18 Fixed bitrot in main firmware with latest libraries, moved old supervisor firmware to subdir, initial version of new supervisor firmware
    [Init.cpp, common-vectors.cpp, hwinit.cpp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]
2024-08-18 Continued work on new supervisor firmware, still need to handle buttons and input power failure
    [mainloop.cpp]
2024-08-21 Can now SSH to main application firmware, but fails to connect properly to front panel
    [top.xdc]
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2024-08-22 Increased SWO baud rate even if bootloader set it wrong
    [hwinit.cpp]
2024-08-22 Rearranged front panel firmware source to new directory structure
    [dongle.cfg]
2024-08-22 Removed legacy openocd config not being used anymore
    [dongle.cfg]
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2024-08-22 Fixed include paths for front panel restructuring; added delays between back to back SPI transactions
    [mainloop.cpp]
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2024-09-15 Removed firmware and board designs for legacy IBC, now using external common-ibc module
    [ibc.kicad_pcb, ibc.kicad_sch]
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
